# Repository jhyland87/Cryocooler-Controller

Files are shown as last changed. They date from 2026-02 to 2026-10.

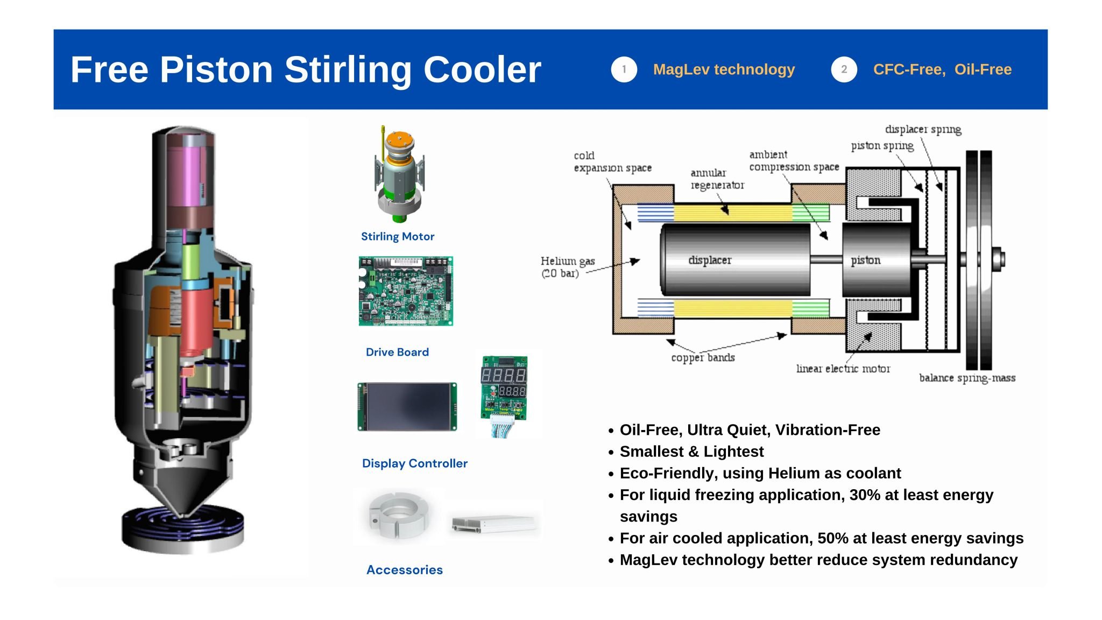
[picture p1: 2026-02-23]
resources/images/RS100-2-2048x1152.jpg

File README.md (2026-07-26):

# ESP32-S3 Cryocooler Controller

Firmware for an ESP32-S3 DevKit that automates the cooldown sequence of a cryogenic cooler. The controller manages a compressor-driven cold stage through ten operational states — from a cold start at room temperature (~295 K) down to an operating setpoint of 78 K, with a graceful shutdown sequence — while enforcing thermal safety limits, detecting back-EMF current spikes, streaming live telemetry via Protobuf over WebSocket, and serving a real-time Preact dashboard over WiFi.

---

## Hardware

| Component | Part | Interface | Address / Pin | Purpose |
|---|---|---|---|---|
| Microcontroller | ESP32-S3 DevKitC-1-N32R16V | — | — | Host MCU (32 MB flash, 16 MB PSRAM) |
| Cold-stage sensor | ADS122C04 + PT1000 RTD | I2C | 0x45 | Cold-stage temperature (4-wire, ratiometric) |
| Waveform generator | AD9833 DDS | SPI | CS: GPIO 7 | 60 Hz sine wave for compressor |
| DAC | AD5693R 16-bit | I2C | 0x4E | Amplifier power control |
| Power monitor | INA237 | I2C | auto | Bus voltage + current |
| IMU | LSM6DSOX 6-DOF | I2C | 0x6A | Vibration / overstroke detection |
| Fan / pump controller | EMC2303 three-channel PWM | I2C | 0x2F | Cooling fan (ch 0) + pump (ch 1) |
| Current sensor | ACS37800 | I2C | auto | Amplifier AC current monitoring |
| Compressor relay | SparkFun Qwiic Single Relay | I2C | 0x19 | Compressor on/off |
| Amplifier relay | SparkFun Qwiic Single Relay | I2C | 0x18 | Amplifier on/off |
| Coolant flow sensor | Alphacool ES (Hall-effect) | GPIO 10 | — | Coolant flow pulses |
| Coolant temperature | NTC thermistor | ADC GPIO 2 | — | Coolant temp via voltage divider |
| Status LED | WS2812 RGB | GPIO 38 | — | Fault / Ready indication |

**I2C bus:** SDA → GPIO 8, SCL → GPIO 9.

**SPI bus** (AD9833 only): CLK → GPIO 42, MISO → GPIO 41, MOSI → GPIO 40.

**Fan fault alert:** EMC2303 ALERT# → GPIO 14 (active-low, external pull-up).

---

## Architecture

All subsystem modules follow a standardised lifecycle pattern built on a CRTP base class (`ModuleBase<T>`) with compile-time interface enforcement. Modules are registered in declarative arrays and initialised/serviced via generic helpers — adding a new module is a one-liner. See [`docs/modules.md`](docs/modules.md) for the full module authoring guide.

```mermaid
flowchart TD
    subgraph Persistent ["Persistent Modules (init once at startup)"]
        HW[hardware<br/>Shared I2C + SPI buses]
        IMU[imu<br/>LSM6DSOX accelerometer]
        CMD[commands<br/>Serial console]
        DASH[dashboard<br/>WiFi + Preact SPA + WebSocket]
        TEL[telemetry<br/>Protobuf frame builder]
        SYS[sysinfo<br/>INA237 power monitor]
        OTA[ota<br/>HTTP firmware updates]
    end

    subgraph Control ["Control Modules (re-init on every Initialize state)"]
        COOL[cooling<br/>EMC2303 fan + pump<br/>software LUT]
        CH[cold_head<br/>ADS122C04 PT1000 RTD]
        AMP[amplifier<br/>AD9833 + AD5693R DAC + ACS37800]
        COMP[compressor<br/>Qwiic relay]
        IND[indicator<br/>WS2812 RGB LED]
    end

    subgraph FSM ["Core Logic"]
        SM[state_machine<br/>Pure FSM — no hardware calls]
    end

    CH  -->|tempC, coolingRate, stalled| SM
    AMP -->|rmsV, overstroke| SM
    IMU -->|overstroke| SM
    SYS -->|sysVoltage| SM

    SM -->|dacTarget| AMP
    SM -->|compressorRelay, amplifierRelay| COMP
    SM -->|faultIndMode, readyIndMode| IND
    SM -->|Output| TEL

    TEL --> DASH
    TEL --> CMD

    classDef persistent fill:#dbeafe,stroke:#3b82f6,color:#1e3a5f
    classDef control    fill:#dcfce7,stroke:#16a34a,color:#14532d
    classDef fsm        fill:#fef3c7,stroke:#d97706,color:#78350f

    class HW,IMU,CMD,DASH,TEL,SYS,OTA persistent
    class COOL,CH,AMP,COMP,IND control
    class SM fsm

    style Persistent fill:#eff6ff,stroke:#93c5fd
    style Control    fill:#f0fdf4,stroke:#86efac
    style FSM        fill:#fffbeb,stroke:#fcd34d
```

---

## Module Reference

### hardware

Initialises the shared I2C bus (`Wire.begin(SDA, SCL)`) and SPI bus (`SPI.begin(...)`) once at startup. All other modules access buses via `hardware::i2c()` and `hardware::spi()` rather than the global singletons. Provides `recoverI2c()` to reset the I2C bus to a clean idle state after a failed transaction, and an error monitor (`reportI2cError()` / `serviceI2c()`) that triggers automatic bus recovery when error counts exceed a threshold.

---

### state_machine

The core of the controller. Ingests sensor readings every tick and outputs a complete set of actuator targets. Contains no hardware calls — pure logic, fully unit-testable on the host PC.

**States:**

| # | Name | Description | FAULT LED | READY LED | DAC |
|---|---|---|---|---|-----|
| -1 | Off | System powered down | Off | Off | 0 |
| 0 | Initialize | Power-up self-check | Solid Amber | Solid Amber | 0 |
| 1 | Idle | Warm standby | Solid Red | Off | 0 |
| 2 | CoarseCooldown | Cooling above 85 K | Flash Fast Red | Off | proportional to temp |
| 3 | FineCooldown | Cooling below 85 K | Flash Fast Red | Flash Slow Green | proportional to temp |
| 4 | Overshoot | Below setpoint, settling | Flash Fast Red | Flash Fast Green | 0 |
| 5 | Settle | In setpoint band; Normal relay | Flash Fast Red | Flash Fast Green | 0 |
| 6 | Baseline | Collecting pre-run baseline (5 min) | Off | Solid Green | 0 |
| 7 | Operating | Normal cryogenic operation | Off | Solid Green | 0 |
| 8 | Shutdown | Graceful shutdown; DAC ramps down | Off | Off | ramps → 0 |
| 9 | Delay | Timed hold; resumes at configured next state | Solid Amber | Solid Amber | 0 |
| 127 | Fault | Terminal fault state | Flash Fast Red | Off | 0 |

**Key configuration** (all in `config.h`):

| Constant | Default | Description |
|---|---|---|
| `SETPOINT_C` | -195.15 °C (78 K) | Target cold-stage temperature |
| `COARSE_FINE_THRESHOLD_C` | -188.15 °C (85 K) | Coarse/Fine transition boundary |
| `SETPOINT_TOLERANCE_C` | 3.0 °C | Band around setpoint for settle/overshoot logic |
| `SETTLE_DURATION_MS` | 60 000 ms | Time stable before advancing to Baseline |
| `BASELINE_DURATION_MS` | 300 000 ms | Baseline collection window |
| `SHUTDOWN_DURATION_MS` | 5 000 ms | Graceful shutdown ramp duration |
| `STALL_DETECT_WINDOW_MS` | 600 000 ms | Stall detection observation window |
| `STALL_MIN_DROP_C` | 2.0 °C | Minimum temp drop required in the window |
| `BACKOFF_MAX_COUNT` | 10 | Max overstroke events before TooManyBackoffs fault |

---

### cold_head

Reads the PT1000 RTD via the ADS122C04 24-bit ADC over I2C (address 0x45). The ADC is configured for 4-wire ratiometric measurement with 250 µA IDAC excitation and a 3854 Ω external reference resistor. Raw ADC counts are converted to resistance, then to temperature via the Callendar-Van Dusen equation (above 0 °C) and AN709 polynomial (below 0 °C).

Uses a non-blocking two-phase state machine: start single-shot conversion → poll DRDY → read 24-bit result. Maintains a ring buffer of `TEMP_HISTORY_SIZE` timestamped samples for cooling-rate calculation (°C/min), stall detection, and cooldown progress (0–100 %).

| Function | Returns |
|---|---|
| `getLastTempK()` | Cold-stage temperature in Kelvin |
| `getLastTempC()` | Cold-stage temperature in Celsius |
| `getCoolingRateCPerMin()` | °C/min, positive = cooling |
| `isStalled()` | True if stall threshold exceeded |

---

### amplifier

Drives the AD9833 DDS (60 Hz sine wave), AD5693R 16-bit DAC (compressor power), and ACS37800 current sensor. Provides two ramp modes:

- `rampToVoltage(target)` — smooth ramp at ±`DAC_MAX_STEP_PER_INTERVAL` per tick
- `rampTowardShutdown(target)` — fast ramp at ±`DAC_SHUTDOWN_STEP_PER_INTERVAL` per tick

**Overstroke (back-EMF) detection:** A slow-tracking EMA forms the baseline. A reading exceeding `baseline + OVERSTROKE_CURRENT_THRESHOLD_A` fires `hasOverstroke()`, subject to `OVERSTROKE_DEBOUNCE_MS`. The EMA is primed for `OVERSTROKE_PRIME_READINGS` ticks on startup.

---

### imu

Drives the LSM6DSOX 6-DOF IMU over I2C (accelerometer only). On `init()` the accelerometer is configured and a one-time blocking calibration collects samples to compute per-axis offsets (gravity is removed from the Z offset).

Each `service()` call applies calibration offsets, runs a first-order low-pass filter, and computes roll/pitch from filtered acceleration. Motion / overstroke is flagged when acceleration magnitude deviates from 9.81 m/s² by more than `ACCEL_THRESHOLD_MPS2`; it clears after `MOTION_TIMEOUT_MS` of stillness.

A periodic FFT (`calculateFrequency()`) detects the compressor vibration frequency in the 45–75 Hz band using 256 samples at 400 Hz, with Hann windowing and quadratic peak interpolation.

| Function | Returns |
|---|---|
| `isInitialized()` | True if sensor was found and configured |
| `hasOverstroke()` | True while motion/overstroke is active |
| `getRoll()` / `getPitch()` | Orientation angles in degrees |
| `getAccelMag()` | Calibrated acceleration magnitude (m/s²) |
| `getFrequencyHz()` | Detected compressor frequency (Hz), or NAN |
| `getTemperature()` | IMU die temperature (°C) |

---

### sysinfo

Reads bus voltage and current via the INA237 power monitor over I2C. Applies EMA smoothing and exposes `getVoltage()`.

---

### cooling

Controls the cooling fan and pump via a single EMC2303 three-channel PWM controller over I2C (address 0x2F). Uses a custom `EMC230x` Arduino library (in `lib/EMC230x/`).

**Software LUT:** Replaces the previous EMC2101 hardware LUT. Each channel has an independently-configured temperature-to-duty lookup table with hysteresis, evaluated once per second from coolant temperature. Entries are sorted ascending by temperature; the evaluator only writes to the chip when the active row changes.

**Deferred init:** The EMC2303 is powered from a 3.3 V regulator derived from the 12 V rail. If 12 V is absent at boot, `init()` fails gracefully and `service()` retries once per second until the chip appears, then promotes itself to `MODULE_INIT_SUCCESS`.

**Fault detection:** The EMC2303's open-drain ALERT# pin (GPIO 14, external pull-up) is sampled every service tick. When asserted (LOW), all four status registers (fan, stall, spin-up, drive-fail) are read and decoded. Faults are exposed via `hasFanFault()` / `getFanFaultDurationMs()` and included in the telemetry frame.

**I2C bus recovery:** When the EMC2303 loses power mid-operation, it can hold the I2C SDA line low and block all other sensors on the shared bus. The service function calls `hardware::recoverI2c()` immediately on detecting an I2C failure to free the bus for other devices.

**Pump normalisation:** User-facing pump speeds are 0–100 % normalised, mapped to 0–`COOLING_PUMP_MAX_DUTY_PCT` (raw 0–255) at the hardware boundary. The pump stalls above ~16 % effective duty (~4400 RPM).

**Tracking monitors:** Score-based monitors for fan duty, coolant temperature, and flow rate detect sustained deviations from expected values.

| Function | Returns |
|---|---|
| `getCoolantTemperature()` | Coolant temperature in °C |
| `getCoolantFlowRate()` | Coolant flow rate in L/min |
| `getFanSpeed()` | Fan duty (0–255) |
| `getFanRPM()` | Fan tachometer RPM |
| `getPumpSpeed()` | Pump speed (normalised 0–100 %) |
| `getPumpRPM()` | Pump tachometer RPM |
| `hasFanFault()` | True while ALERT# is asserted |
| `getFanFaultDurationMs()` | Duration of current fault episode |

---

### compressor

Manages the compressor relay (SparkFun Qwiic Single Relay at 0x19) with timed-run support. `compressor start <duration>` energises the relay for a specified duration (e.g. `1h30m`, `45s`), clamped to `COMPRESSOR_MAX_RUN_MS`. Can be disabled at compile time with `ENABLE_COMPRESSOR false`.

---

### indicator

Drives the on-board WS2812 RGB LED (GPIO 38) according to the state machine's requested `Mode`. All flash timing is non-blocking — `update(nowMs)` is called every loop iteration.

| Mode | Colour | Rate |
|---|---|---|
| `SolidRed` | Red | — |
| `SolidGreen` | Green | — |
| `SolidAmber` | Amber | — |
| `FlashFastRed` | Red | 2 Hz |
| `FlashSlowGreen` | Green | 1 Hz |
| `FlashFastGreen` | Green | 2 Hz |

---

### dashboard

Connects to WiFi and serves a Preact single-page application with real-time telemetry:

- **HTTP** (port 80): serves the embedded SPA (`index.html`, `app.js`, `style.css`) and a JSON telemetry endpoint at `GET /api/telemetry`
- **WebSocket** (port 8080): streams Protobuf-encoded telemetry frames at 1 Hz
- **mDNS**: `cryocooler.local`

The dashboard frontend uses Preact + MUI + Vite and is bundled into firmware flash at build time via `scripts/embed_web.py`. WiFi credentials live in `include/arduino_secrets.h`.

---

### ota

HTTP OTA firmware update endpoint. `GET /ota` serves an upload form; `POST /ota` flashes new firmware. Enabled with `ENABLE_OTA true` in `config.h`.

---

### commands

Non-blocking USB serial command handler. `service()` accumulates characters and dispatches completed lines. The same `processLine()` function is used by the TCP server and by unit tests with a stub `Print`.

| Command | Action |
|---|---|
| `start` | Begin cooldown (from Off or Idle) |
| `stop` | Abort and return to Idle |
| `off` | Power off the system entirely |
| `reboot` | Reboot the MCU |
| `status` | Print current state and running flag |
| `summary` | Full snapshot of all sensor and actuator values |
| `fsm state` | Print current FSM state with time-in-state |
| `fsm history` | Print recent FSM state transitions |
| `fault clear` | Clear an active fault and return to Idle |
| `fault history` | Print fault log with reason and clear method |
| `board` | Print compile-time board/platform info |
| `i2c scan` | Scan I2C bus and print responding addresses |
| `reinit` | Re-initialise all or named modules |
| `cooling on/off` | Enable / disable cooling system |
| `cooling fan <N>` | Set fan: raw duty (0–255) or percent (0–100%) |
| `cooling pump <N>` | Set pump: raw duty (0–255) or percent (0–100%) |
| `set vout <V>` | Set DAC output voltage (0–120 V, 0–100 %, or `auto`) |
| `get vout` | Get current DAC output voltage |
| `relay` | Show current state of both relays |
| `relay amplifier on/off` | Control amplifier relay |
| `relay compressor on/off` | Control compressor relay |
| `compressor start <dur>` | Start timed compressor run (e.g. `1h30m`) |
| `compressor status` | Show compressor state and remaining time |
| `compressor stop` | Stop the compressor immediately |
| `telemetry on/off` | Enable / disable telemetry output |
| `telemetry delta on/off` | Delta-only or full frames |
| `dashboard on/off` | Enable / disable dashboard TCP broadcasts |
| `mock ...` | Sensor mock: `enable`, `disable`, `status`, `temp`, etc. |
| `ota status` | Print OTA partition and firmware version info |
| `update image` | Flash new firmware via HTTP upload |
| `help` | List all commands |

---

### telemetry

Snapshots all module values each tick into a `FrameBuilder`. The WebSocket path encodes frames as Protobuf binary via Nanopb; the HTTP `/api/telemetry` endpoint returns JSON. The schema source of truth is `proto/telemetry.proto`.

---

### frame_builder

Format-agnostic telemetry frame with a fluent field API. Renders to Serial Studio wire format or `JsonDocument` from the same snapshot.

---

### conversions

Header-only pure-math utilities with no hardware dependencies — safe for native unit tests.

| Function | Description |
|---|---|
| `resistanceToTemperaturePT1000(R)` | PT1000 Ω → °C (Callendar-Van Dusen / AN709) |
| `tempCToDacValue(...)` | Temperature → 12-bit DAC mapping |
| `tempCToFraction(...)` | Temperature → cooldown fraction [0.0, 1.0] |
| `msToHHMMSS(ms, buf)` | ms → `HH:MM:SS` string |
| `parseDurationMs(str, ...)` | Human duration string → ms (e.g. `1h30m`) |
| `formatDurationMs(ms, buf, len)` | ms → compact human string (e.g. `1h 30m 00s`) |

---

### sensor_mock

Injects synthetic sensor values into all modules for hardware-free FSM testing. When `sensor_mock::isActive()`, `read()`/`service()` in each module pull from `sensor_mock::get()` instead of hardware. Activated via the `mock` serial command.

---

## Transition Triggers

### Normal Operation Flow

`start()` selects the resume state from `tempK` and is valid from both **Off** and **Idle**. `Delay` is reachable from any non-Fault state via `startDelay()` — see [Global Transitions](#global-transitions).

```mermaid
stateDiagram-v2
    direction TB

    [*] --> Off
    Off  --> Initialize : reinit
    Idle --> Initialize : reinit
    Initialize --> Idle : init timer

    state "Cooldown Phase" as COOLDOWN {
        CoarseCooldown --> FineCooldown : temp < 85 K
        FineCooldown --> CoarseCooldown : temp > 85 K
    }

    state "Approaching Setpoint" as SETTLING {
        Overshoot --> Settle : in band
    }

    state "Stable Operation" as STABLE {
        Baseline --> Operating : baseline timer
    }

    Idle --> CoarseCooldown : start, temp <br/>≥ 85 K
    Idle --> FineCooldown   : start, below <br/>85 K
    Idle --> Overshoot      : start, below<br/> setpoint
    Idle --> Settle         : start, in band

    FineCooldown --> Overshoot : below setpoint
    FineCooldown --> Settle    : in band

    Settle --> Baseline : settle timer

    COOLDOWN --> Shutdown : stop
    SETTLING --> Shutdown : stop
    STABLE   --> Shutdown : stop
    Delay    --> Shutdown : stop
    Shutdown --> Idle     : shutdown<br/>timer

    Delay --> Idle           : timer → Idle
    Delay --> CoarseCooldown : timer → Coarse

    classDef startup  fill:#dbeafe,color:#1e3a5f
    classDef cooldown fill:#ccfbf1,color:#134e4a
    classDef settling fill:#fef3c7,color:#78350f
    classDef stable   fill:#dcfce7,color:#14532d
    classDef shutdown fill:#f1f5f9,color:#334155
    classDef delay    fill:#ede9fe,color:#3b0764

    class Off,Initialize,Idle startup
    class CoarseCooldown,FineCooldown cooldown
    class Overshoot,Settle settling
    class Baseline,Operating stable
    class Shutdown shutdown
    class Delay delay
```

### Fault Conditions

```mermaid
stateDiagram-v2
    direction LR

    state "Cooldown Phase" as COOLDOWN {
        CoarseCooldown
        FineCooldown
    }

    state "Approaching Setpoint" as SETTLING {
        Overshoot
        Settle
    }

    state "Stable Operation" as STABLE {
        Baseline
        Operating
    }

    COOLDOWN --> Fault : temp stall
    COOLDOWN --> Fault : too many backoffs
    SETTLING --> Fault : too many backoffs
    STABLE   --> Fault : too many backoffs
    Delay    --> Fault : too many backoffs

    Fault --> Idle       : clearFault()
    Fault --> Initialize : reinit()

    classDef cooldown fill:#ccfbf1,color:#134e4a
    classDef settling fill:#fef3c7,color:#78350f
    classDef stable   fill:#dcfce7,color:#14532d
    classDef delay    fill:#ede9fe,color:#3b0764
    classDef fault    fill:#fee2e2,stroke:#ef4444,color:#7f1d1d
    classDef startup  fill:#dbeafe,color:#1e3a5f

    class CoarseCooldown,FineCooldown cooldown
    class Overshoot,Settle settling
    class Baseline,Operating stable
    class Delay delay
    class Fault fault
    class Idle,Initialize startup
```

### Global Transitions

These originate from all non-Fault states and are omitted from the diagrams above.

| Trigger | Condition | To |
|---|---|-----|
| `off()` | — | Off |
| RMS overvoltage | `amplifier RMS V > AMPLIFIER_MAX_VOLTAGE_VAC` | Fault |
| Low system voltage | `systemVoltage > 0` and `< MIN_SYSTEM_VOLTAGE_VDC` | Fault |
| State oscillation | Same two states alternate ≥ `FSM_OSCILLATION_MIN_CYCLES` times in window | Fault |
| `startDelay()` | — | Delay |

---

## Build Pipeline

The firmware build runs three pre-build scripts in order before PlatformIO compiles:

### 1. Protobuf compilation (scripts/compile_proto.py)

Compiles `proto/telemetry.proto` into Nanopb C stubs (`src/generated/telemetry.pb.c`, `include/generated/telemetry.pb.h`). Auto-installs the `google.protobuf` Python package if missing.

Skip with `SKIP_PROTO_BUILD=1 pio run`.

### 2. Dashboard build (scripts/build_dashboard.py)

Runs `npm ci` in `dashboard/`, generates protobufjs stubs (`npm run proto:build`), then builds the Vite SPA (`npm run build`) into `data/`.

Skip with `SKIP_DASHBOARD_BUILD=1 pio run`.

### 3. Web embedding (scripts/embed_web.py)

Embeds `data/*.html/css/js` as `PROGMEM const char[]` arrays in `include/web_content.h`. The SPA is served directly from flash — no filesystem needed.

### Quick firmware iteration

```bash
SKIP_DASHBOARD_BUILD=1 pio run          # firmware only, skip npm/vite
SKIP_DASHBOARD_BUILD=1 pio run -t upload  # build + flash
```

---

## Dependencies

### PlatformIO libraries (platformio.ini)

| Library | Purpose |
|---|---|
| `majicdesigns/MD_AD9833` | DDS waveform generator |
| `bblanchon/ArduinoJson` | JSON serialisation |
| `mathieucarbou/ESPAsyncWebServer` | Async HTTP + WebSocket server |
| `robtillaart/RunningAverage` | Running average utility |
| `jonblack/arduino-fsm` | Finite state machine |
| `adafruit/Adafruit INA237 and INA238 Library` | I2C power monitor |
| `pololu/ACS37800` | AC current sensor |
| `kosme/arduinoFFT` | FFT for vibration frequency detection |
| `adafruit/Adafruit LSM6DS` | 6-DOF IMU driver |
| `adafruit/Adafruit AD569x Library` | AD5693R DAC |
| `sparkfun/SparkFun Qwiic Relay Arduino Library` | Relay control |
| `nanopb/Nanopb` | Protobuf C encoder/decoder |
| `sparkfun/SparkFun ADS122C04 ADC Arduino Library` | 24-bit ADC for PT1000 RTD |

### Local libraries (lib/)

| Library | Purpose |
|---|---|
| `EMC230x` | EMC2301/02/03/05 dual PWM fan/pump controller |
| `ContinuousZMCT103C` | Non-blocking AC current RMS sampling |
| `Device-Defined-Dashboard` | Serial Studio dashboard JSON generator |

### Dashboard (dashboard/package.json)

| Package | Purpose |
|---|---|
| Preact | Lightweight UI framework |
| MUI (Material UI) | Component library |
| MUI X-Charts | Telemetry chart components |
| Vite | Build tooling |
| protobufjs | WebSocket telemetry decoding |

### Platform

```ini
platform = espressif32@5.3.0   ; Arduino Core 2.0.6 + IDF 4.4.x
board    = esp32-s3-devkitc-1-n32r16v
```

---

## Setup

### WiFi credentials

Create `include/arduino_secrets.h` (excluded from version control):

```cpp
#define WIFI_SSID "your-network-name"
#define WIFI_PASS "your-password"
```

### Key tuning parameters

All application-level constants live in `config.h`. Hardware pin assignments live in `pin_config.h`. Internal algorithm parameters live in `config_advanced.h`. None have hardware includes, so all are safe to include in native unit tests.

---

## Testing

Unit tests run on the host PC via PlatformIO's native environment:

```bash
pio test -e native
```

Tests use a minimal Arduino stub (`test/test_native/stubs/`) that provides `millis()`, a `Print` class, and other shims. The state machine, serial command handler, and telemetry modules are compiled and exercised without hardware.

Embedded integration tests (requiring hardware) live in `test/test_embedded/` and run via:

```bash
pio test -e esp32s3
```

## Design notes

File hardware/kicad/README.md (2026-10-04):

# Cryocooler controller — KiCad schematic

KiCad 10 hierarchical schematic for the ESP32-S3 cryocooler controller. Open
`cryocooler.kicad_pro`. A PDF export is in `cryocooler-schematic.pdf`. No PCB layout yet.

GPIO assignments follow [`include/config/pin_config.h`](../../include/config/pin_config.h).
The hardware table in the top-level README is stale (wrong buses/pins for the IMU, DAC,
ACS37800 and EMC2303), so use this file instead.

## Sheets

| Sheet | Contents |
|---|---|
| `cryocooler.kicad_sch` (root) | ESP32-S3-WROOM-2-N32R16V, EN/BOOT, USB-C + ESD, I2C pull-ups |
| `power_input` | 12 V screw terminal, 5 A fuse, SMBJ16A TVS, bulk caps |
| `power_button` | LTC2954CTS8-2, IRF4905S high-side P-FET, KILL# bias, CL25N8-G (SOT-89) + red/green LED |
| `rails_logic` | AP63205 buck (12→5 V) → LD1117S33 (5→3.3 V) |
| `rails_15v` | ADP5071AREZ ±16.4 V (datasheet Fig. 47 values) → ADP7142 (+15 V), ADP7182 (−15 V) |
| `signal_gen` | 25 MHz osc, AD9833, OPA1656, MCP4921 + LM4040-2.5 + OPA188, AD633 |
| `amp_control` | GPIO6 → BSS138 → BSS84 high-side 12 V to amplifier REM, red/green LED |
| `amp_current` | ACS37800 (SPI) + ISO7741 + MIE1W0505 (VSEL→GND2 = 3.3 V output), 4×1 MΩ + 4.02 kΩ divider |
| `system_current` | INA237 (I2C 0x40) + 15 mΩ shunt in the switched 12 V rail |
| `cooling` | EMC2303 (0x4D via 33 kΩ ADDR_SEL pull-up; fan + pump), Alphacool ES flow tach and NTC |
| `cold_head` | ADS122C04 (I2C 0x45), 4-wire PT1000, 3.9 kΩ Rref |
| `imu` | LSM6DSOX in SPI mode with INT1/INT2 |
| `indicators` | READY / FAULT LEDs, WS2812B status LED behind a 74AHCT1G125 level shifter |

## GPIO map (ESP32-S3-WROOM-2)

| Signal | GPIO | Signal | GPIO |
|---|---|---|---|
| I2C SDA / SCL | 8 / 9 | AD9833 FSYNC | 7 |
| SPI SCK / MOSI / MISO | 42 / 41 / 40 | MCP4921 CS | 5 |
| LSM6DSOX CS / INT1 / INT2 | 1 / 2 / 39 | ACS37800 SCK / MOSI / MISO / CS | 11 / 12 / 13 / 17 |
| Amp REM enable | 6 | PWR_KILL (LTC2954 KILL#) | 10 |
| FAULT / READY LED | 14 / 15 | Flow tach | 18 |
| EMC2303 ALERT# | 21 | NTC ADC | 4 |
| Status RGB (WS2812B) | 38 | LTC2954 INT# (optional, unused by firmware) | 16 |

GPIO43 (TXD0) is left unconnected because it toggles with ROM boot messages; ACS37800 chip-select is on GPIO17. GPIO26–37 are reserved
by the octal flash/PSRAM and are left unconnected.

## Drawing conventions

Power symbols are always upright (supplies point up, grounds hang down) and resistors use the US zig-zag symbol
(`Device:R_US`). Every sheet is hand-laid in the same style: signal flow runs left to right, supplies are drawn as
shared rails with decoupling caps hanging off them, switching loops are kept compact, and nets are wired with
lines rather than net labels (labels are used only for global signals such as the GPIO nets, and for a few
local nets that would otherwise need long detours, for example the ISO7741 isolated-side SPI lines).

Bypass/decoupling capacitors for each IC are drawn together in a labelled block at the side of the sheet (supply rail, caps, ground bus) and connect to the IC through the shared power nets; regulator input/output and compensation capacitors stay in the circuit.

**No-overlap text rule.** Reference, value, net-label and note text may not overlap other text or a symbol body
(plus 1 mm for pin numbers). `tools/textlayout.py` places each field in the first free spot, hides a field only
if none exists, and `gen_schematic.py` exits non-zero if `text overlap check` reports any overlap. Pin names and
numbers drawn inside a library symbol, and labels that sit on their own wire, are outside the rule.

## Regenerating

The schematic files are generated; edit the Python and re-run, don't hand-edit the `.kicad_sch` files.
Each `build_*` function in `tools/gen_schematic.py` sets `sh.handwired = True` and draws its sheet in grid cells
(1 cell = 1.27 mm) with `place_ic`, `pose=at(column, row, rot)`, `wire`, `rail_symbol`, `rail_flag`, `spur` and
`net_label`; `tools/layout.py` (the auto-router) is still there for sheets that leave `handwired` off.
Wires are split at pins automatically, so a pin in the middle of a wire is connected.

```bash
python3 hardware/kicad/tools/make_lib.py        # lib/cryocooler.kicad_sym
python3 hardware/kicad/tools/gen_schematic.py   # root + sheets/
```

`tools/verify_netlist.py` checks the GPIO map against `pin_config.h`, missing footprints and
single-pin nets on a `kicad-cli sch export netlist` output; `tools/compare_netlists.py` compares the
connectivity of two netlists (useful after changing layout, which must not change connections; two-pin
passives may be flipped), and `tools/datasheet_rules.py` checks datasheet-critical connections.

## Review status

Every IC was audited against its datasheet; see [`DESIGN_REVIEW.md`](DESIGN_REVIEW.md) for the
errors found and fixed, what was verified, and the open issues that need a decision (notably:
the 12 V → 5 V stage is now an AP63205 buck instead of the over-limit LD1117S50).
`tools/datasheet_rules.py` re-checks 117 datasheet-derived connections on every change.

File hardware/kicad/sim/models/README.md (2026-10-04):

# Simulation models

- `ad633_behavioral.lib` - hand-written AD633 stand-in (W = X*Y/10, rail-limited). Not an Analog Devices model.
- `ti_original/OPA1656.LIB`, `ti_original/OPAx188.LIB` - Texas Instruments SPICE models. Not committed:
  download them from the OPA1656 and OPA188 product pages on ti.com (Design tools & simulation,
  SPICE model) and put the `.LIB` files in `ti_original/`. `cryocooler_sim.kicad_sch` references them
  through its Sim.Library fields.
- `opa1656.lib`, `opax188.lib` - ngspice-converted copies made by `../prep_models.py`. They did not converge
  in the headless runner; KiCad's own simulator runs the originals.

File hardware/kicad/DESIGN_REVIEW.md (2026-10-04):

# Design review: datasheet audit

Every IC and active discrete in the schematic was checked against its manufacturer datasheet
(pinout, supply range, required external parts, unused-pin rules, absolute maximums). The
connection-level findings are encoded as regression tests in
[`tools/datasheet_rules.py`](tools/datasheet_rules.py) (117 rules, run against the exported
netlist). ERC alone cannot catch a wrong circuit, so run both after any change:

```bash
kicad-cli sch export netlist --format kicadsexpr -o /tmp/cryo.net hardware/kicad/cryocooler.kicad_sch
python3 hardware/kicad/tools/datasheet_rules.py /tmp/cryo.net
python3 hardware/kicad/tools/verify_netlist.py /tmp/cryo.net      # GPIO map vs pin_config.h
```

## Errors found and fixed

These were wrong in my first version (several were also wrong in the original draft):

| Part | Problem | Datasheet fact | Fix |
|---|---|---|---|
| EMC2303 | ADDR_SEL tied to GND | ADDR_SEL decodes a **pull-up resistor** (Table 5-1): 33 kΩ → 0x4D | 33 kΩ to 3V3 |
| EMC2303 | PWM outputs unpulled | PWM outputs are open-drain by default and need a pull-up | 10 kΩ to 3V3 on PWM1/PWM2 |
| MIE1W0505 | VSEL tied to GND2 but a 5 V rail assumed | VSEL → GND2 gives **3.3 V**; 5 V needs VSEL to VOUT/float | Kept VSEL → GND2; the module now makes ISO_3V3 directly, so the LD1117 and ISO_5V on that side were removed |
| MIE1W0505 | Wrong output cap | 22 µF + 0.1 µF out, 10 µF + 0.1 µF in | Corrected. (It is an MPS part, not Murata.) |
| CL25 | Pin 2/3 swapped (VB was on NC) | VA = 1, VB = 2 (centre lead + tab), NC = 3 in both packages; N3 is TO-92, **N8 is SOT-89** | Fixed pinout; now **CL25N8-G (SOT-89)** as requested |
| Power LED | 120 Ω legs diverted the 25 mA away from the LED | CL25 is a 25 mA source shared by both legs | 330 Ω (about 9 mA reaches the LED) |
| ADP7182 | EN tied to GND | EN is dual-polarity (\|VEN\| ≥ 2 V); **EN = 0 V is off** | EN tied to VIN (−16.5 V) |
| ADP7182 | No stability cap | 100 pF across RFB1 recommended | Added |
| ADP5071 | Draft values (L1 10 µH, RC1 100 k, CC1 10 nF, …) | Tested values in Fig. 47 / Tables 9-11 | L1 3.3 µH, L2 6.8 µH, RC1 5.6 k / CC1 47 nF, RC2 12 k / CC2 68 nF, DFLS240 diodes, 10 µF/50 V outputs |
| ADP5071 | Rails only about ±15 V (no LDO headroom) | VPOS = 0.8 V (1 + RFT1/RFB1); VNEG = 0.8 V − 0.8 V·RFT2/RFB2 | RFT1 2.67 M / RFB1 137 k → +16.39 V; RFT2 2.55 M / RFB2 118 k → −16.49 V |
| ADP7142 / ADP7182 | 2.2 µF caps lose capacitance at 15 V DC bias | ≥ 1.5 µF effective required | 4.7 µF / 25 V |
| LSM6DSOX | SDx (pin 2) and SCx (pin 3) left floating | Must be tied to **VDDIO or GND** in I²C/SPI mode | Tied to GND |
| MCP4921 | Only 100 nF on VDD; Vref bias marginal | 0.1 µF + 10 µF on VDD; LM4040 needs ≥ 60-65 µA | + 10 µF; 8.2 k → 6.8 k |
| WS2812B | 3.3 V data into a 5 V part | VIH = 0.7 × VDD = 3.5 V | 74AHCT1G125 level shifter |
| AD633 | Output offset up to ±50 mV reached the amplifier | AD633 spec: output offset ±5 to ±50 mV | 10 µF DC-blocking cap + 100 kΩ |
| OPA1656 (sine gain stage) | R8 33 k gave 3.3 V pk (6.6 Vpp) full scale, under-using the amplifier's input range | ZE500.1 RCA input 0.2-6 V (unverified, from retailer listings); user wants Vctl 10 V = 10 Vpp (5 V pk, 3.5 Vrms) | R8 33 k → 51 k (gain 16.45, ~4.9 V pk with the AD9833's assumed 0.3 V pk; calibrate in firmware) |

## Verified as correct (no change needed)

| Part | Checked against | Result |
|---|---|---|
| LTC2954-2 (TSOT-23-8) | LTC2954 datasheet 2954fb | Pinout; no internal KILL pull-up (so the 5 V bias is required); KILL abs max 7 V; ONT floating = 32 ms; 100 nF PDT ≈ 0.7 s hold-off; EN#/INT# ratings |
| ESP32-S3-WROOM-2 | Datasheet v1.7 | Pins 28-30 are NC; IO47/48 are 1.8 V on R16V parts; strapping pins; EN needs a defined level |
| AD633JR (SOIC) | AD633 Rev A (pin drawing) | 1 Y1, 2 Y2, 3 −VS, 4 Z, 5 W, 6 +VS, 7 X1, 8 X2; ±15 V; RL ≥ 2 kΩ |
| AD9833 | AD9833 Rev E | COMP 10 nF → VDD, CAP/2.5V 100 nF, 0.1 + 10 µF on VDD, VINH 2.8 V at 5 V VDD |
| OPA1656 / OPA188 | TI datasheets | Pinouts, supply (VS ≤ 40 V), NC pins may float |
| INA237 | TI datasheet | Pinout, 0x40 with A0 = A1 = GND, IN+/IN− polarity, ±163.84 mV range |
| ADS122C04 | TI SBAS751B | Pinout, 0x45 (A0 = A1 = DVDD), ratiometric 4-wire RTD circuit, VREF ≥ 0.75 V (0.975 V), AIN2 may float |
| ISO7741 | TI SLLSEP4K | Pinout and channel directions, 0.1 µF decoupling, default output high |
| ACS37800 | Allegro datasheet | Pinout, 3.3 V variant, 0.1 µF, 4 × 1 MΩ + RSENSE divider (Fig. 1), SPI VIH 2.8 V |
| LD1117S33 | ST Rev 26 | Pinout (tab = VOUT), ≥ 10 µF output cap, 5 V input within the 15 V limit |
| AP63205 | Diodes DS41326 Rev 3-2 | Pinout 1 FB, 2 EN, 3 VIN, 4 GND, 5 SW, 6 BST; component values from Fig. 1 / Table 3; VIN ≤ 32 V |
| IRF4905S, BSS84, BSS138 | Infineon / Diodes / onsemi | Ratings and VGS(th); ±20 V gate limit not exceeded |
| USBLC6-2SC6 | ST Rev 7 | Pinout; drawn as a pass-through (ESP32 side on pins 4/6, connector side on 3/1) so each data line crosses the protection device instead of being tied across it |
| LM4040 | TI LM4040-N | SOT-23 pinout (pin 3 may float) |
| SG-8002CA | Epson datasheet (supplied) | Pin map 1 OE/ST, 2 GND, 3 OUT, 4 VCC; **PH = 5 V CMOS** with OE (high or open = enabled); 0.01-0.1 µF bypass; no filter in the supply line; 7.0×5.0 mm, 5.08 mm pitch footprint. Order the PH variant, e.g. SG-8002CA 25.000000 MHz PH |
| Alphacool ES | Datasheet + manual | Standard 3-pin fan connector; NTC 0.53-194 kΩ (10 kΩ at 25 °C) |

## Resolved: 12 V → 5 V stage

The LD1117S50 (7 V drop, estimated 1.9-4.1 W in a SOT-223, VIN abs max 15 V) was replaced with the
**Diodes AP63205WU-7** 5 V / 2 A synchronous buck, using the datasheet circuit (DS41326 Fig. 1 / Table 3):
4.7 µH (Bourns SRN6045TA-4R7M: 26 mΩ, Isat 6.8 A, Irms 4.5 A), 10 µF + 100 nF input, 2 × 22 µF output,
100 nF bootstrap, EN to VIN, FB to the 5 V output. VIN rating is 3.8-32 V (40 V for 400 ms), which covers the
26 V TVS clamp. Estimated loss at 0.3-0.6 A is 0.1-0.4 W (θJA 89 °C/W, about 10-36 °C rise). The LD1117S33
stays on the 5 V rail (1.7 V headroom, about 0.7 W at 400 mA).

## Supply: Dell XYK93 (Delta DPS-2000EB class)

Reseller listings give about 12.2 V at about 164 A (200-240 V mains in) and a 12 V standby rail rated 3.5 A. Check
the Delta DPS-2000EB datasheet for the exact figures and the PS_ON pinout (I could not find it).

* **Use the main 12 V rail** with PS_ON held low (breakout board). The standby rail is limited to 3.5 A, which is tight
  for the fans and pump. The LTC2954 button still works, because it switches the board's own supply.
* **Fault current:** the supply can deliver about 160 A, so the 5 A SMD fuse (F1) is a backup only; confirm its
  DC breaking capacity in the chosen part's datasheet. Add an **inline high-breaking-capacity fuse (7.5-10 A, for example an
  automotive blade fuse) at the PSU end** of the cable.
* **Standby LED current** (about 25 mA, 0.3 W) is not a concern on a mains-powered supply.
* The 12.2 V level is inside every regulator's limits (AP63205 3.8-32 V, LTC2954 2.7-26.4 V, IRF4905 55 V).

## Open issues

1. Power LED draws about 25 mA from VIN in standby (the CL25 current is always flowing); acceptable on this supply.
2. *Resolved:* ACS37800 chip-select moved from GPIO43 (U0TXD, toggles with ROM boot messages) to **GPIO17**
   (`pin_config.h` updated), and 10 kΩ pull-ups to 3V3 on the ISO7741 CS, SCLK and MOSI inputs give defined idle
   levels while the ESP32 GPIOs float in reset.
2. Order the AP63205 as **AP63205WU-7** (fixed 5 V, 1.1 MHz); the 5 V buck switches with ±6% spread spectrum,
   so keep the SW node and input loop small on the PCB.

## Not verifiable from a datasheet I could read

* **LM4040 accuracy grade:** choose the A or B grade for the DAC reference.
* **MIE1W0505 footprint:** your vendor model (SnapEDA); I checked pad names, not the land pattern.
* **SPI modes** (AD9833 mode 2, ACS37800 mode 3, others mode 0/3): set by the firmware libraries.
* **PCB-level items** (creepage between ISO_GND and the logic side, ground returns, copper pours).

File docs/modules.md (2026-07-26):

# Module System

This document covers the module lifecycle pattern, how to create a new module, and how modules are initialised and serviced in `main.cpp`.

---

## Overview

Every subsystem in the firmware is implemented as a C++ **namespace** with free functions. A thin `Module` struct inside each namespace inherits from `ModuleBase<T>` (CRTP) to provide a standardised lifecycle interface that the compiler enforces at build time.

Modules are registered in **declarative arrays** of `ModuleEntry` descriptors. Generic helpers (`initGroup`, `serviceWithLog`, `reportStatus`) drive init and service loops from these arrays — no per-module boilerplate in `main.cpp`.

**Key files:**

| File | Role |
|---|---|
| `include/module.h` | CRTP base, enums, traits, registry helpers |
| `src/main.cpp` | Module arrays, init groups, service loop |

---

## Lifecycle

Every module goes through two phases:

### 1. Initialisation (init)

Called once during `setup()`. Returns an `InitStatus`:

| Status | Meaning |
|---|---|
| `MODULE_INIT_NOT_STARTED` | `init()` has not been called yet |
| `MODULE_INIT_IN_PROGRESS` | Still running (calibration, WiFi, etc.) |
| `MODULE_INIT_SUCCESS` | Completed successfully |
| `MODULE_INIT_HARDWARE_ERROR` | Hardware device failed to respond (I2C/SPI NACK) |
| `MODULE_INIT_DEPENDENCY_ERROR` | A required dependency is unavailable |
| `MODULE_INIT_CONFIG_ERROR` | Invalid or missing configuration |
| `MODULE_INIT_TIMEOUT` | Exceeded allowed time budget |
| `MODULE_INIT_UNKNOWN_ERROR` | Catch-all |

### 2. Service (service)

Called every `loop()` tick. Returns a `ServiceStatus`:

| Status | Meaning |
|---|---|
| `MODULE_SERVICE_NOT_STARTED` | `service()` has not been called yet |
| `MODULE_SERVICE_OK` | Ran and produced valid output this tick |
| `MODULE_SERVICE_SKIPPED` | Skipped this tick (time-gated, disabled, no new data) |
| `MODULE_SERVICE_ERROR` | A recoverable error occurred; output may be stale |

---

## Creating a New Module

### Step 1: Define the namespace and functions

```cpp
// include/mymodule.h
#pragma once
#include "module.h"

namespace mymodule {

module::InitStatus    init();
module::ServiceStatus service();
float getValue();

// ── Module adapter ──────────────────────────────────────────────
struct Module : ModuleBase<Module> {
    static module::InitStatus    init()    { return _initStatus = mymodule::init(); }
    static module::ServiceStatus service() { return _serviceStatus = mymodule::service(); }
};

ASSERT_MODULE_INTERFACE(Module);

} // namespace mymodule
```

### Step 2: Implement the functions

```cpp
// src/mymodule.cpp
#include "mymodule.h"
#include "hardware.h"
#include "logger.h"

static LogStream _Log = Log.createChildLogger("mymodule");

namespace mymodule {

module::InitStatus init() {
    // Hardware setup, calibration, etc.
    TwoWire& i2c = hardware::i2c();
    i2c.beginTransmission(0x42);
    if (i2c.endTransmission() != 0) {
        return module::MODULE_INIT_HARDWARE_ERROR;
    }
    _Log.println("Sensor detected");
    return module::MODULE_INIT_SUCCESS;
}

module::ServiceStatus service() {
    // Non-blocking periodic work
    // ...
    return module::MODULE_SERVICE_OK;
}

float getValue() { return 42.0f; }

} // namespace mymodule
```

### Step 3: Register in main.cpp

Add the module to the appropriate array:

```cpp
#include "mymodule.h"

// Add to the appropriate group:
static const module::ModuleEntry persistentModules[] = {
    // ... existing entries ...
    MODULE_ENTRY(mymodule, false),   // false = non-fatal init failure
};
```

That's it. The module will be automatically initialised, serviced, and included in the boot status banner.

### Key rules

1. **`init()` must cache its result** by assigning to `_initStatus`:
   ```cpp
   static module::InitStatus init() { return _initStatus = mymodule::init(); }
   ```

2. **`service()` must cache its result** by assigning to `_serviceStatus`:
   ```cpp
   static module::ServiceStatus service() { return _serviceStatus = mymodule::service(); }
   ```

3. **`service()` must not block.** Use time-gating, state machines, or async patterns for long operations.

4. **Use `ASSERT_MODULE_INTERFACE(Module);`** after the struct definition. This produces a clear compile error if `init()` or `service()` is missing or has the wrong return type.

---

## Module Registry

### ModuleEntry struct

A type-erased descriptor with function pointers — no vtable, no heap allocation:

```cpp
struct ModuleEntry {
    const char*    name;
    InitStatus     (*initFn)();
    InitStatus     (*getInitStatus)();
    ServiceStatus  (*serviceFn)();
    ServiceStatus  (*getServiceStatus)();
    bool           fatal;   // true = halt startup if init fails
};
```

### MODULE_ENTRY macro

Creates a `ModuleEntry` from any namespace containing a conforming `Module` struct:

```cpp
MODULE_ENTRY(cooling, false)
// expands to:
// { "cooling", cooling::Module::init, cooling::Module::getInitStatus,
//   cooling::Module::service, cooling::Module::getServiceStatus, false }
```

### Helper functions

All three are templates that accept any printf-style log function:

| Function | Purpose |
|---|---|
| `module::initGroup(entries, count, emitFn, logFn, yieldFn)` | Initialise every module in an array. Logs before/after each init. Calls optional `emitFn` (e.g. `telemetry::emitSafe`) after each step for dashboard progress. Calls optional `yieldFn` to feed the FreeRTOS watchdog. Returns `false` if any fatal entry fails. |
| `module::serviceWithLog(entry, prevStatus, logFn)` | Service a module and log only on health-status transitions (healthy ↔ unhealthy). Prevents per-tick spam. |
| `module::reportStatus(entries, count, logFn)` | Print the boot banner — lists all modules that failed to init. Returns the failure count. |

---

## Module Groups in main.cpp

Modules are organised into four arrays. **Order within each array encodes dependency constraints.**

### Persistent modules

Initialised once at boot. Never re-initialised on `reinit`. These provide the communication path (console, dashboard, telemetry) that the operator uses to issue commands.

```mermaid
flowchart LR
    logger --> imu --> commands --> ota --> dashboard --> espnow["espnow
    (conditional)"] --> telemetry --> sysinfo

    classDef mod fill:#dbeafe,stroke:#3b82f6,color:#1e3a5f
    classDef cond fill:#e0e7ff,stroke:#6366f1,color:#312e81,stroke-dasharray: 5 5
    class logger,imu,commands,ota,dashboard,telemetry,sysinfo mod
    class espnow cond
```

- OTA before dashboard (routes must be registered before the HTTP server starts)
- dashboard before espnow (WiFi must be up)

### Control modules

Re-initialised on every FSM `reinit()` (entering the Initialize state). This allows hardware peripherals to be reconfigured after a logical system reset without a full MCU reboot.

```mermaid
flowchart LR
    compressor["compressor
    (conditional)"] --> cooling --> amplifier --> cold_head

    classDef mod fill:#dcfce7,stroke:#16a34a,color:#14532d
    classDef cond fill:#dcfce7,stroke:#16a34a,color:#14532d,stroke-dasharray: 5 5
    class cooling,amplifier,cold_head mod
    class compressor cond
```

- compressor first (de-energise relay as early as possible)

### Tick-service modules

Serviced every `loop()` iteration with health-transition logging:

```mermaid
flowchart LR
    sysinfo --> imu --> amplifier --> cooling

    classDef mod fill:#e0e7ff,stroke:#6366f1,color:#312e81
    class sysinfo,imu,amplifier,cooling mod
```

### Boot banner

A combined array of all modules (including special-cased ones) used for the one-time status report on the first `loop()` iteration.

---

## Special-Cased Modules

These modules don't fit the uniform init/service signature and remain hand-coded in `main.cpp`:

| Module | Reason |
|---|---|
| `hardware` | Fatal init — halts startup if it fails. Initialised before all other modules. |
| `indicator` | Must init before WiFi to avoid `neopixelWrite()` deadlock on ESP32-S3. Has its own timer-driven `update(nowMs)` in the loop. |
| `state_machine` | Non-standard `update(tempC, coolingRate, rmsV, stalled, nowMs, overstroke, sysVoltage)` signature. Returns actuator targets. |
| `telemetry` | `emit(out)` takes `state_machine::Output` as input. `emitSafe()` is used during init for dashboard progress. |
| `cold_head` | In the time-gated section of the loop, before `state_machine::update()`. Includes fault checking internally. |
| `sensor_mock` | No `Module` struct. Called once per gated tick to advance mock ramps before module reads. |
| `commands` | Serviced unconditionally every tick (before the time gate) so the console is always reachable. |

---

## Init Flow (setup)

```mermaid
flowchart TD
    S([setup]) --> HW["hardware::Module::init()
    FATAL — halts on failure"]
    HW --> IND["indicator::Module::init()
    before WiFi"]

    IND --> PM[initPersistentModules]
    PM --> PMG["module::initGroup(persistentModules)
    logger → imu → commands → ota →
    dashboard → espnow → telemetry → sysinfo"]

    PMG --> SM["state_machine::Module::init()
    pure logic, always succeeds"]

    SM --> RI[state_machine::reinit]
    RI --> CM[initControlModules]
    CM --> CMG["module::initGroup(controlModules)
    compressor → cooling →
    amplifier → cold_head"]

    classDef fatal fill:#fee2e2,stroke:#ef4444,color:#7f1d1d
    classDef special fill:#fef3c7,stroke:#d97706,color:#78350f
    classDef group fill:#dbeafe,stroke:#3b82f6,color:#1e3a5f
    classDef control fill:#dcfce7,stroke:#16a34a,color:#14532d

    class HW fatal
    class IND,SM special
    class PM,PMG group
    class CM,CMG control
```

## Service Flow (loop)

```mermaid
flowchart TD
    L([loop]) --> CMD["commands::Module::service()
    unconditional — console always reachable"]

    CMD --> TICK["tickServiceModules[]
    sysinfo → imu → amplifier → cooling
    serviceWithLog — logs only health transitions"]

    TICK --> I2C["hardware::serviceI2c(nowMs)
    I2C error monitor + bus recovery"]
    I2C --> LED["indicator::update()
    at INDICATOR_UPDATE_INTERVAL_MS cadence"]

    LED --> GATE{LOOP_INTERVAL_MS
    gate}
    GATE -->|not yet| RET([return])
    GATE -->|elapsed| MOCK["sensor_mock::service()
    advance mock ramps"]

    MOCK --> CH["cold_head::service()
    read RTD + fault check"]
    CH --> FSM["state_machine::update(...)
    returns actuator targets"]
    FSM --> ACT["indicator::setFaultMode / setReadyMode
    compressor::Module::service"]
    ACT --> TEL["telemetry::emit(out)
    dashboard::Module::service"]

    classDef always fill:#dbeafe,stroke:#3b82f6,color:#1e3a5f
    classDef tick fill:#e0e7ff,stroke:#6366f1,color:#312e81
    classDef infra fill:#f1f5f9,stroke:#94a3b8,color:#334155
    classDef gated fill:#dcfce7,stroke:#16a34a,color:#14532d
    classDef exit fill:#f1f5f9,stroke:#cbd5e1,color:#64748b

    class CMD always
    class TICK tick
    class I2C,LED infra
    class MOCK,CH,FSM,ACT,TEL gated
    class RET exit
```

---

## Optional Interface

`ModuleBase<T>` provides default implementations for optional methods. Override only what you need:

| Method | Default | Override when... |
|---|---|---|
| `service()` | Returns `SERVICE_SKIPPED` | Module has periodic work |
| `enable()` | No-op | Module output can be suspended |
| `disable()` | No-op | Module output can be suspended |
| `isEnabled()` | Returns `true` | Module tracks enabled state |

### Status queries (provided by ModuleBase, no override needed)

| Method | Returns |
|---|---|
| `getInitStatus()` | Cached `InitStatus` from last `init()` call |
| `isInitialized()` | `true` if init status is `SUCCESS` |
| `getServiceStatus()` | Cached `ServiceStatus` from last `service()` call |
| `overrideInitStatus(s)` | Override cached status (for deferred/hot-plug init) |

---

## Deferred (Hot-Plug) Initialisation

Some hardware (e.g. the EMC2303 fan controller) may not be powered at boot. The pattern for handling this:

1. `init()` returns `MODULE_INIT_HARDWARE_ERROR` when the device is absent.
2. `service()` checks `Module::getInitStatus() != SUCCESS` and periodically retries.
3. On success, call `Module::overrideInitStatus(MODULE_INIT_SUCCESS)` to promote the module.
4. On I2C failure, call `hardware::reportI2cError()` and `hardware::recoverI2c()` to free the shared bus.

See `src/cooling.cpp` for a complete example.

---

## Compile-Time Enforcement

### Trait detection

`module_traits::is_module<T>` returns `true` at compile time if `T` has both `init()` and `service()` with the correct return types. Used internally by `ASSERT_MODULE_INTERFACE`.

### ASSERT_MODULE_INTERFACE(Module)

Place this immediately after your `Module` struct definition. It produces a descriptive static_assert failure if the interface is not satisfied:

```
error: static assertion failed: Module does not satisfy the Module interface:
       must provide static module::InitStatus init()
       and static module::ServiceStatus service()
```

---

## Conventions

- **Namespace = module name.** The namespace name is used in log output, serial commands, and the boot banner.
- **One `.cpp` + one `.h` per module.** The header declares the public API; the implementation file is self-contained.
- **Static state.** Module state is file-scope `static` variables in the `.cpp` file. No globals, no singletons.
- **Child loggers.** Each module creates `static LogStream _Log = Log.createChildLogger("name");` for prefixed log output.
- **Bus access via `hardware::`** — never use the global `Wire` or `SPI` directly.
- **Mock support.** When `sensor_mock::isActive()`, skip hardware reads and pull values from `sensor_mock::get()` instead.
- **Non-blocking.** `service()` must return promptly. Use state machines or time-gating for multi-step operations.

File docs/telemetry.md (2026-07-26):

# Adding a New Telemetry Field

This document walks through every file that must be touched to add a new
telemetry value end-to-end.  The system has **two independent output paths**
that both need updating:

| Path | Transport | Encoder | Decoder |
|---|---|---|---|
| **Serial Studio / HTTP JSON** | Serial (CSV) + TCP + HTTP GET | `FrameBuilder` in `telemetry.cpp` | Serial Studio project / browser `JSON.parse()` |
| **WebSocket binary** | WebSocket | Nanopb in `telemetry_pb.cpp` | protobufjs in `decodeTelemetry.ts` |

Both paths share the same dot-notation key convention (`group.field_name`).

---

## Worked Example

We'll add a hypothetical field `cooling.pump_pressure_bar` (a float read from
`cooling::getPumpPressure()`).

---

## Step 1 — src/telemetry.cpp: emit() and buildStartupFrame()

`emit()` is called once per control tick (1 Hz) and populates `lastFrame_`.
`buildStartupFrame()` is the startup slow-path that is used before the first
`emit()` completes.  Both must be kept in sync.

### 1a — emit()

Find the `cooling.*` block and add your field:

```cpp
// src/telemetry.cpp  ~line 600
lastFrame_
    ...
    .field("cooling.pump_rpm",       "%u",   cooling::getPumpRPM())
    .field("cooling.pump_pressure_bar", "%.2f", cooling::getPumpPressure())  // ← add
    ...
```

`FrameBuilder::field(name, fmt, value)` accepts any numeric or string type.
The format string controls both the Serial Studio output and how the value is
stored internally (float/int/string determines the JSON type).

### 1b — buildStartupFrame()

The same field must appear in `buildStartupFrame()` so the HTTP dashboard gets
a valid structure even during startup.  If the module might not be ready yet,
guard it:

```cpp
// src/telemetry.cpp  ~line 298 (inside the coolingReady block)
if (coolingReady) {
    frame
        ...
        .field("cooling.pump_rpm",          "%u",   cooling::getPumpRPM())
        .field("cooling.pump_pressure_bar", "%.2f", cooling::getPumpPressure())  // ← add
        ...
} else {
    frame
        ...
        .field("cooling.pump_rpm",          "%s", "")
        .field("cooling.pump_pressure_bar", "%s", "")  // ← add (empty sentinel)
        ...
}
```

### 1c — (Optional) Delta-mode passive list

If the field changes every tick and should **not** trigger a Serial Studio line
on its own (e.g. a slowly-drifting value), add it to `kPassiveFields[]` near
the top of `telemetry.cpp`:

```cpp
static const char* const kPassiveFields[] = {
    ...
    "cooling.pump_pressure_bar",   // ← add if it's noisy/continuous
};
```

### 1d — Check FrameBuilder::MAX_FIELDS

If the build produces a compile-time assertion failure about field count, bump
the limit in `include/frame_builder.h`:

```cpp
static constexpr uint8_t MAX_FIELDS = 130;  // increase if needed
```

Count fields by searching for `.field(` calls across both `emit()` and
`buildStartupFrame()`.

---

## Step 2 — proto/telemetry.proto: Schema definition

The `.proto` file is the single source of truth for the WebSocket binary
format.  Every field must live inside a **message** that maps to a dot-notation
prefix.

### Adding to an existing message

```protobuf
// proto/telemetry.proto
message Cooling {
  int32  status        = 1;
  int32  pump_on       = 2;
  float  temp_c        = 3;
  float  flow_rate_lpm = 4;
  uint32 fan_speed     = 5;
  uint32 fan_rpm       = 6;
  uint32 pump_speed    = 7;
  uint32 pump_rpm      = 8;
  float  pump_pressure_bar = 9;   // ← add; next available field number
}
```

> **Field numbers are permanent.**  Never renumber or reuse a field number
> after the firmware has been deployed — doing so silently corrupts decoding
> on old clients.  Always append using the next available number.

### Adding to a new message / group

If you need a brand-new group prefix (e.g. `vacuum.*`):

1. Add the new message to `telemetry.proto`:

```protobuf
message Vacuum {
  float pressure_mbar = 1;
  float pump_speed    = 2;
}
```

2. Add a field for it in `TelemetryFrame`:

```protobuf
message TelemetryFrame {
  ...
  Vacuum vacuum = 16;   // next available field number in TelemetryFrame
}
```

### String fields

If the field is a string, add an entry to `proto/telemetry.options` to set a
fixed maximum size (required by Nanopb to avoid heap allocation):

```
cryocooler.Cooling.pump_label   max_size:24
```

---

## Step 3 — Delete stale generated files

After editing `.proto`, the generated C and JS stubs are stale.  Delete them
so the build pipeline regenerates them unconditionally:

```bash
rm src/generated/telemetry.pb.c
rm include/generated/telemetry.pb.h
rm dashboard/src/generated/telemetry.js
rm dashboard/src/generated/telemetry.d.ts
```

The next `pio run` will regenerate all four files automatically via
`scripts/compile_proto.py` (C stubs) and `npm run proto:build` (JS stubs).

---

## Step 4 — src/telemetry_pb.cpp: Nanopb encoder

This file populates the Nanopb struct that is encoded and sent over WebSocket.
It reads from the same module getters as `telemetry.cpp` but fills struct
fields rather than calling `FrameBuilder::field()`.

```cpp
// src/telemetry_pb.cpp  — inside the cooling section
frame_.has_cooling = true;
frame_.cooling.status        = cooling::isEnabled() ? 1 : 0;
...
frame_.cooling.pump_rpm      = cooling::getPumpRPM();
frame_.cooling.pump_pressure_bar = cooling::getPumpPressure();   // ← add
```

The struct field names are generated from the `.proto` field names in
snake_case (e.g. `pump_pressure_bar` → `frame_.cooling.pump_pressure_bar`).

> **For new top-level messages** you also need to set the `has_<message>` flag
> and initialise the nested struct, following the pattern used by
> `frame_.has_cooling`, `frame_.has_system`, etc.

---

## Step 5 — dashboard/src/types/telemetry.ts: TypeScript interface

Add the new field to the appropriate nested interface so TypeScript knows about
it:

```typescript
// dashboard/src/types/telemetry.ts
cooling?: {
  status?: number;
  pump_on?: number;
  temp_c?: number;
  flow_rate_lpm?: number;
  fan_speed?: number;
  fan_rpm?: number;
  pump_speed?: number;
  pump_rpm?: number;
  pump_pressure_bar?: number;   // ← add
};
```

For a new group, add an entirely new interface property:

```typescript
vacuum?: {
  pressure_mbar?: number;
  pump_speed?: number;
};
```

---

## Step 6 — dashboard/src/utils/decodeTelemetry.ts: Protobuf → TypeScript mapping

Map the protobufjs-generated camelCase property to the snake_case TypeScript
field.  protobufjs converts `pump_pressure_bar` → `pumpPressureBar`
automatically.

```typescript
// dashboard/src/utils/decodeTelemetry.ts
if (f.cooling) {
  out.cooling = {
    ...
    pump_rpm:           f.cooling.pumpRpm     ?? undefined,
    pump_pressure_bar:  f.cooling.pumpPressureBar ?? undefined,   // ← add
  };
}
```

For a new top-level message:

```typescript
if (f.vacuum) {
  out.vacuum = {
    pressure_mbar: f.vacuum.pressureMbar ?? undefined,
    pump_speed:    f.vacuum.pumpSpeed    ?? undefined,
  };
}
```

> **camelCase rule:** protobufjs converts every snake_case proto field name to
> camelCase on the JS side.  `pump_pressure_bar` → `pumpPressureBar`,
> `flow_rate_lpm` → `flowRateLpm`, etc.

---

## Step 7 — include/dashboard_config.h: Serial Studio layout

Add a `DatasetCfg` entry in the appropriate group array so the field appears
in the Serial Studio desktop dashboard:

```cpp
// include/dashboard_config.h  — inside coolingDatasets[]
{
    .title          = "Pump Pressure",
    .units          = "bar",
    .telemetryKey   = "cooling.pump_pressure_bar",
    .widget         = ss::WidgetType::Gauge,
    .widgetMin      = 0,
    .widgetMax      = 10,
    .alarmLow       = 0,
    .alarmHigh      = 8,
    .alarmEnabled   = true,
    .graph          = true,
    .log            = true,
    .overviewDisplay = true,
},
```

The `telemetryKey` must exactly match the dot-notation key used in
`FrameBuilder::field()` in `telemetry.cpp`.

For a new group, add a new `DatasetCfg` array and a new `GroupCfg` entry in
`dataGroups[]`.

---

## Step 8 — Web dashboard (optional)

These are only needed if you want the field visible in the Preact dashboard.

### 8a — History buffer (App.tsx)

To record a rolling 100-sample history for use in a chart, add the key to
`HISTORY_KEYS`:

```typescript
// dashboard/src/App.tsx
const HISTORY_KEYS = [
  ...
  'cooling.pump_pressure_bar',   // ← add
] as const;
```

### 8b — Quick-read tile (App.tsx)

To show the value as a large numeric tile in the top row:

```typescript
// dashboard/src/App.tsx
const TILES: TileConfig[] = [
  ...
  { label: 'Pump P', key: 'cooling.pump_pressure_bar', unit: 'bar', dp: 2, color: '#80cbc4' },
];
```

### 8c — Chart component

Pass the history buffer slice to whichever chart component is appropriate, or
create a new one.  Use `getHistory('cooling.pump_pressure_bar')` to retrieve
the data.

---

## Summary Checklist

| # | File | What to do |
|---|---|---|
| 1a | `src/telemetry.cpp` — `emit()` | Add `.field("group.key", "fmt", getter())` |
| 1b | `src/telemetry.cpp` — `buildStartupFrame()` | Same field, with empty-string sentinel in the `else` branch |
| 1c | `src/telemetry.cpp` — `kPassiveFields[]` | Add key if it should not trigger delta output on its own |
| 1d | `include/frame_builder.h` | Bump `MAX_FIELDS` if the assertion fires |
| 2  | `proto/telemetry.proto` | Add field to existing message (or new message + `TelemetryFrame` entry) |
| 2s | `proto/telemetry.options` | Add `max_size` entry for any new string field |
| 3  | Generated stubs | Delete `src/generated/telemetry.pb.c`, `include/generated/telemetry.pb.h`, `dashboard/src/generated/telemetry.{js,d.ts}` |
| 4  | `src/telemetry_pb.cpp` | Populate the new `frame_.<message>.<field>` from the getter |
| 5  | `dashboard/src/types/telemetry.ts` | Add `field?: type` to the appropriate nested interface |
| 6  | `dashboard/src/utils/decodeTelemetry.ts` | Map `f.<message>.<camelCaseField>` to `out.<group>.<snake_case_field>` |
| 7  | `include/dashboard_config.h` | Add `DatasetCfg` entry (and `GroupCfg` if new group) |
| 8a | `dashboard/src/App.tsx` — `HISTORY_KEYS` | Add key for chart history (optional) |
| 8b | `dashboard/src/App.tsx` — `TILES` | Add tile entry for quick-read display (optional) |
| 8c | Dashboard component | Wire `getHistory('group.key')` into a chart (optional) |

---

## Notes

- **Key naming convention:** always `group.field_name` in snake_case.  The
  group prefix must match the proto message name used in `TelemetryFrame`
  (converted to snake_case: `ColdHead` → `cold_head`).
- **Proto field numbers:** append-only, never reuse.  Check the highest
  existing number in the message before adding.
- **`int64`/`uint64` proto fields:** protobufjs returns these as `Long` objects.
  Use the `toLong()` helper in `decodeTelemetry.ts` when mapping them.
- **Build shortcut:** set `SKIP_DASHBOARD_BUILD=1` in your environment to skip
  the full npm/Vite build and iterate on firmware-only changes faster:
  ```bash
  SKIP_DASHBOARD_BUILD=1 pio run
  ```

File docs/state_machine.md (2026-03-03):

# Cryocooler State Machine

## Diagram

### Normal Operation Flow

`start()` selects the resume state from `tempK` and is valid from both **Off**
and **Idle**; only the Idle transitions are shown to reduce clutter.  `Delay`
is reachable from any non-Fault state via `startDelay()` — see
[Global Transitions](#global-transitions-any-state).

```mermaid
stateDiagram-v2
    direction TB

    [*] --> Off
    Off  --> Initialize : reinit
    Idle --> Initialize : reinit
    Initialize --> Idle : init timer

    state "Cooldown Phase" as COOLDOWN {
        CoarseCooldown --> FineCooldown : temp < 85 K
        FineCooldown --> CoarseCooldown : temp > 85 K
    }

    state "Approaching Setpoint" as SETTLING {
        Overshoot --> Settle : in band
    }

    state "Stable Operation" as STABLE {
        Baseline --> Operating : baseline timer
    }

    Idle --> CoarseCooldown : start, temp ≥ 85 K
    Idle --> FineCooldown   : start, below 85 K
    Idle --> Overshoot      : start, below setpoint
    Idle --> Settle         : start, in band

    FineCooldown --> Overshoot : below setpoint
    FineCooldown --> Settle    : in band

    Settle --> Baseline : settle timer

    COOLDOWN --> Shutdown : stop
    SETTLING --> Shutdown : stop
    STABLE   --> Shutdown : stop
    Delay    --> Shutdown : stop
    Shutdown --> Idle     : shutdown timer

    Delay --> Idle           : timer → Idle
    Delay --> CoarseCooldown : timer → Coarse
```

### Fault Conditions

Three fault types — **RMS overvoltage**, **low system voltage**, and **state
oscillation** — fire from *any* non-Fault state and are listed in the
[Global Transitions](#global-transitions-any-state) table.  The diagram below
shows the state-specific faults; composite groupings match the normal-flow
diagram.

```mermaid
stateDiagram-v2
    direction TB

    state "Cooldown Phase" as COOLDOWN {
        CoarseCooldown
        FineCooldown
    }

    state "Approaching Setpoint" as SETTLING {
        Overshoot
        Settle
    }

    state "Stable Operation" as STABLE {
        Baseline
        Operating
    }

    COOLDOWN --> Fault : temp stall
    COOLDOWN --> Fault : too many backoffs
    SETTLING --> Fault : too many backoffs
    STABLE   --> Fault : too many backoffs
    Delay    --> Fault : too many backoffs

    Fault --> Idle       : clearFault()
    Fault --> Initialize : reinit()
```

---

## Global Transitions (any state)

These transitions originate from all non-Fault states and are omitted from the
diagram above to keep it readable.

| Trigger | Condition | To | FaultReason |
|---|---|---|---|
| `off()` | — | Off | — |
| RMS overvoltage | `amplifier RMS V > AMPLIFIER_MAX_VOLTAGE` | Fault | `RmsOvervoltage` |
| Low system voltage | `systemVoltage > 0` and `systemVoltage < MIN_SYSTEM_VOLTAGE_VDC` | Fault | `LowSystemVoltage` |
| State oscillation | FSM alternates between same two states >= `FSM_OSCILLATION_MIN_CYCLES` times within `FSM_OSCILLATION_WINDOW_MS` | Fault | `StateOscillation` |
| `startDelay()` | — | Delay | — |

---

## State Reference

| State | Value | Relay | FAULT indicator | READY indicator | DAC target |
|---|:-:|---|---|---|---|
| Off | -1 | Bypass | Off | Off | 0 |
| Initialize | 0 | Bypass | Solid Amber | Solid Amber | 0 |
| Idle | 1 | Bypass | Solid Red | Off | 0 |
| CoarseCooldown | 2 | Bypass | Flash Fast Red | Off | proportional to temp |
| FineCooldown | 3 | Bypass | Flash Fast Red | Flash Slow Green | proportional to temp |
| Overshoot | 4 | Bypass | Flash Fast Red | Flash Fast Green | 0 |
| Settle | 5 | **Normal** | Flash Fast Red | Flash Fast Green | 0 |
| Baseline | 6 | **Normal** | Off | Solid Green | 0 |
| Operating | 7 | **Normal** | Off | Solid Green | 0 |
| Shutdown | 8 | Bypass | Off | Off | ramping to 0 (fast) |
| Delay | 9 | Bypass | Solid Amber | Solid Amber | 0 |
| Fault | 127 | Bypass + **Alarm** | Flash Fast Red | Off | 0 |

The DAC target is computed proportional to how far `tempK` has dropped from
`AMBIENT_START_K` toward `SETPOINT_K`, and is only non-zero during
CoarseCooldown and FineCooldown.  The amplifier ramps toward the target each
tick; Shutdown uses a faster ramp rate via `amplifier::rampTowardShutdown()`.

---

## Fault Reference

| FaultReason | Value | Trigger | Originating states |
|---|:-:|---|---|
| RmsOvervoltage | 1 | `amplifier::getLastRmsVoltage() > AMPLIFIER_MAX_VOLTAGE` | Any non-Fault |
| TemperatureStall | 2 | Stall-detect window expired without sufficient temp drop | CoarseCooldown, FineCooldown |
| TooManyBackoffs | 3 | `backoffCount >= BACKOFF_MAX_COUNT` | All running states |
| LowSystemVoltage | 4 | `systemVoltage < MIN_SYSTEM_VOLTAGE_VDC` (0.0 ignored) | Any non-Fault |
| StateOscillation | 5 | FSM oscillation detector fired | Any non-Fault |

Fault is a **terminal state**. The only exits are `clearFault()` to Idle and
`reinit()` to Initialize. Both paths reset `faultReason`, `backoffCount`, and
`backoffDacOffset`.

---

## Behavioural Notes

**start() resume logic** — The starting state is chosen from the current
cold-stage temperature so the system resumes correctly after a power cycle
without triggering spurious stall faults.  `start()` is valid from both Off
and Idle with identical temperature-based branching.

**Settle timer** — The timer only advances while the temperature is inside the
setpoint band (`SETPOINT_K +/- SETPOINT_TOLERANCE_K`).  Any excursion out of
band resets the timer to zero; the full `SETTLE_DURATION_MS` must elapse
continuously in-band before the transition to Baseline fires.

**Back-EMF backoff** — Each overstroke event detected by the IMU reduces the
effective DAC target by `BACKOFF_DAC_STEP`.  The penalty accumulates until
`BACKOFF_MAX_COUNT` is reached, at which point the `TooManyBackoffs` fault is
triggered.  The offset and counter both reset on `clearFault()` and `reinit()`.

**Delay state** — A generic timed hold reachable from any non-Fault state via
`startDelay(nowMs, durationMs, nextState)`.  The destination is either Idle or
CoarseCooldown; any other value defaults to Idle.  `stop()` can interrupt a
pending delay.

**Fault is terminal** — The only exits are `clearFault()` to Idle and
`reinit()` to Initialize.  Both reset `faultReason`, `backoffCount`, and
`backoffDacOffset`; `reinit()` additionally re-runs all hardware module inits
via the registered `onInitializeCallback`.

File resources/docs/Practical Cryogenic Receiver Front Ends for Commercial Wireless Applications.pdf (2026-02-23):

# Practical Cryogenic Receiver Front Ends for Commercial Wireless Applications

### Balam A. Willemsen

### Superconductor Technologies Inc., Santa Barbara, California 93111, USA

Abstract — Long-life, high-reliability cryocoolers, developed in the past decade, have allowed for the limited deployment of cryogenic microwave electronics in commercial wireless networks. We survey some of the background leading to current CRFEs and experience learned from early deployments. System reliability is a key issue for wireless providers, and must be an inherent consideration for CRFE design. CRFEs can be designed for lower cost by consolidating, eliminating and simplifying parts and assemblies. Here we focus on a new approach for computer aided filter trimming of complex filters in complex RF paths. Finally, we look ahead to other potential advances in CRFEs.

Index Terms — Cryogenic electronics, Land mobile radio equipment, Land mobile radio spectrum management, Circuit tuning.

I. INTRODUCTION

Since the discovery of superconductivity in 1911, there has been interest in making use of the unique electronic properties of materials as they are cooled to extremely low temperatures for practical applications. By the mid 1960s several applications were on the verge of practicality. Yet, for all this time one thing remains true, “cryogenic electronics will only be as useful as the cost and reliability of the refrigeration

permits.” [1] In the radio frequency and microwave arena,

### cryogenics was thus relegated for many decades to high value applications in radio astronomy and satellite communication

where the costs of reliable refrigeration were acceptable.
In the late 1980s, two important changes occurred that led to the work described in this manuscript: The discovery of High Temperature Superconductors (HTS) in 1987, and the evolution and rapid deployment of large terrestrial wireless communications networks. By 1997, the field had matured to the point that limited quantities of Cryogenic Receiver Front Ends (CRFEs) had already been deployed with the wireless providers and had been subjected to life tests by the basestation manufacturers.
Today, over 6,000 CRFEs are in use in North American wireless networks. While several companies, large and small, have pursued this market and developed and tested prototypes, only Superconductor Technologies Inc. (STI) has achieved any measurable level of deployment. The goal of this paper is to summarize some of the key technical design considerations of the most recent generation of STI CRFE, which are all aimed at reducing recurring cost, and thus increasing the practicality of the end product. Much background information can be found in a variety of other sources such as [2] or [3].

II. BENEFITS OF CRFES TO WIRELESS NETWORKS

CRFEs that incorporate HTS, such as the Superlink Rx® offer a unique combination of sensitivity, selectivity and size when compared with other technologies. The sensitivity is mainly provided by cryogenically cooled LNA, which does not add as much noise to the signal as it would if it were not cryogenically cooled. Selectivity is primarily improved by means of the thin-film HTS “brick-wall” filter which is typically not much larger than a postage stamp, while providing the selectivity and loss characteristics of a much larger filter. Of course, the overall system size is not determined by the filters alone, but the overhead of the cryopackaging, cryocooler and controller can be offset by sharing these among some large number of RF paths. A typical CRFE contains 6 filter/LNA paths. The system performance benefits provided by using a CRFE can be particularly significant in today’s CDMA networks which can be particularly sensitive to noise and interference. [4]
STI has performed numerous uplink enhancement trials over a period of 4 years to help quantify these benefits with multiple customers, infrastructure types, regions. In particular, 10 of these trials have been in CDMA networks at 850 MHz. One useful and simple to measure metric that can be looked at is the reduction in handset transmit power, which is an indirect measurement of the base station sensitivity. Over these 10 CDMA 850 trials, the average reduction in handset transmit power was 4.1 dB. More details on how these trials break down in terms of region or infrastructure type are shown in Table I.

TABLE I
SUMMARY OF TRIAL RESULTS FOR STI CRFES IN CDMA 850 MHZ NETWORKS.
Category | Handset transmit power change (dB) | #
Average | -4.1 | 10
Urban | -5.5 | 3
Suburban | -3.5 | 3
Rural | -3.5 | 4
OEM A | -4.3 | 7
OEM B | -4.1 | 2
OEM C | -2.5 | 1
978-1-4244-2804-5/09/$25.00 © 2009 IEEE | 1457 | IMS 2009

III. CRYOCOOLERS AND SYSTEM RELIABILITY

One of the key reasons STI has succeeded where others have not, was the early emphasis on developing our own, compact, low-cost, efficient, high-reliability free-piston Stirling cycle cryocooler[5]. The breakdown of costs of the key subsystems in a typical CRFE is shown in Figure 1. It can clearly be seen that far from an “invisible cryocooler” the cryocooler and its DSP based controller circuit board are a significant, but tolerable 24% of the total system cost. Production volume remains the only way to reduce the cryocooler cost, while various ways to reduce costs in the other areas will be discussed in sections IV-VI.

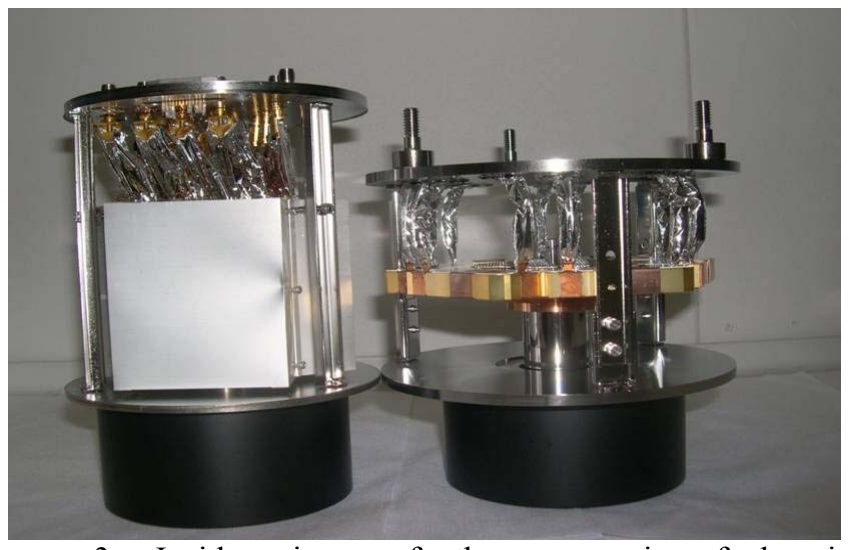
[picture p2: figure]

### As of late 2007, the population of 6,000 deployed cryocoolers in CRFEs had surpassed 200 million cumulative runtime hours. Thus, on average, each cryocooler had been running continuously for over 4 years!

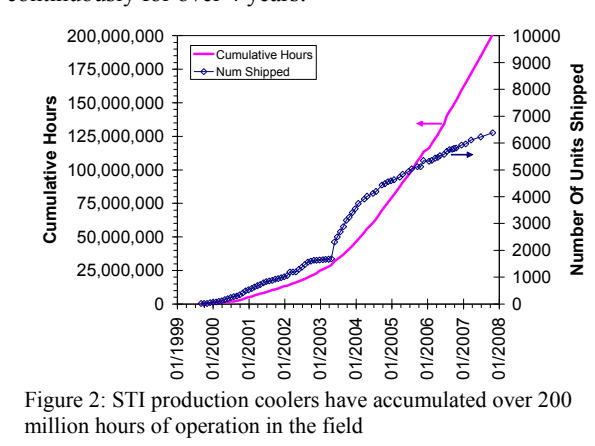
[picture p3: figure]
Cumulative Hours; Number Of Units Shipped; Cumulative Hours Num Shipped; million hours of operation in the field

The overall system MTBF > 500,000 hours is not limited by the cryocooler or the HTS, or even the cryopackaging. Instead, most of the system failures in the field have occurred because of the more conventional components such as the printed circuit boards and the cooling fans.
Of course the relative low-cost and high-reliability of the STI Sapphire crycooler make it attractive for other cryogenic electronic applications. As such, it was selected for use in the

Allen Telescope Array, a radio astronomy project which went online in late 2007.

IV. DESIGN FOR LOW COST

Design for low-cost and high reliability implies eliminating parts and simplifying processes where possible. As initially conceived [10] and deployed in 1997, the STI CRFE was a very complicated assembly requiring many custom machined parts with features from multiple sides. While this is acceptable for satellites or other applications where these costs are dwarfed by other costs, it is not for widespread commercial applications.
Thus, in 2004 we undertook a major effort to redesign the CRFE for lower cost. Since much of the cost of the CRFE is in the cryopackaging, much of the effort was expended there. Much of this simplification can bee seen in Figures 3 and 4, showing pictures of the insides of a 2004 vintage dewar and one from 2008. As can be seen, the assembly has been greatly simplified, with many parts being consolidated and/or eliminated altogether. In particular, many threaded parts, mainly screws and connectors have been eliminated or replaced with spring clips.

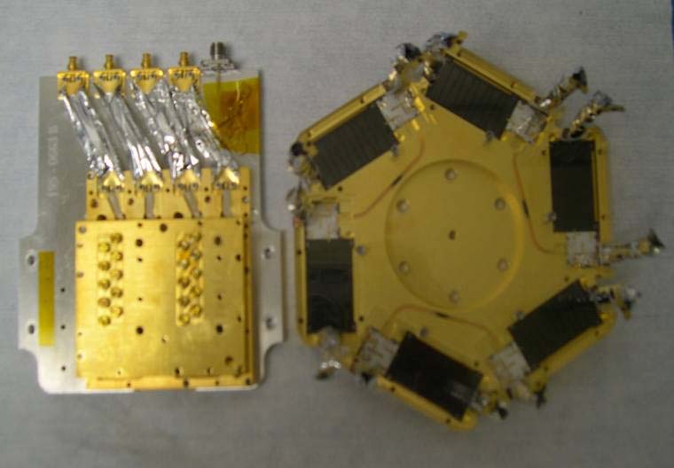
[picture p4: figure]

Figure 4: Expanded views of one of the three microenclosures in a 2004 dewar (left) and a 2008 microenclosure.

Figure 3: Inside views of the cryogenic rf housings (microenclosures) inside 2004 dewar (left) and 2008 dewar (right). The 2008 dewar has been optimized to eliminate parts as compared to the 2004 design.

Figure 2: STI production coolers have accumulated over 200

Cold Circuits,
30%

Cryopackage,
33%

Cooler, 24%

System, 13%

Figure 1. Breakdown of loaded costs of CRFE subsystems as of 2008. The dominant sources of cost are the cold circuits, cryopackaging and cryocooler/controller.

V. FILTER TRIMMING

Another area where this is apparent is in the fine-tuning of the filter. It is very common for high performance filters to make use of mechanical tuning elements to correct for manufacturing tolerances which can affect the center frequency of the filter, as well as its return loss. At STI we initially incorporated dielectric tuners using sapphire cylinders above our filters [11]. These work very well, providing sufficient tuning range to adjust center frequency and return loss. However they still require precise, fine-detail machining to incorporate the fine threads required for fine positioning of the dielectric rod, and since these actuators form an integral part of the RF enclosure, their cost is shipped with the final product.
Another approach was developed at Conductus, where the tuning elements are small pieces of HTS attached to a spring clip[12]. The actuator for the spring clips was designed as a separate piece which could be removed from the part once the filter was tuned. In this way, some of the cost is shifted from the product to the tool required to make the part, which can then be amortized over a large number of products.
In ref. 6 we described an approach for computer aided filter trimming, which allows the filter to be trimmed for center-frequency and return-loss without any additional mechanical tuners. The additional features required for trimming are fabricated along with the filter and thus do not add any cost. This approach leads to well tuned filters in their test housing, but by the time the filters are integrated with the rest of the rf chain required for the system that includes bond-wires, LNAs, cryocables, switches and connectors the return loss of the chain is degraded.
In this respect, the mechanical tuner approach can lead to better system performance, as it allows the filter to be tuned so as to compensate for any mismatches in the other components in the rf chain. As a first approach, the pre-tuned filters were integrated with the rest of the components in the standard mechanically tuned filter housing, removing 8 or 9 of the 10 tuners required for each filter for a substantial reduction in labor and materials cost for trimming each filter.

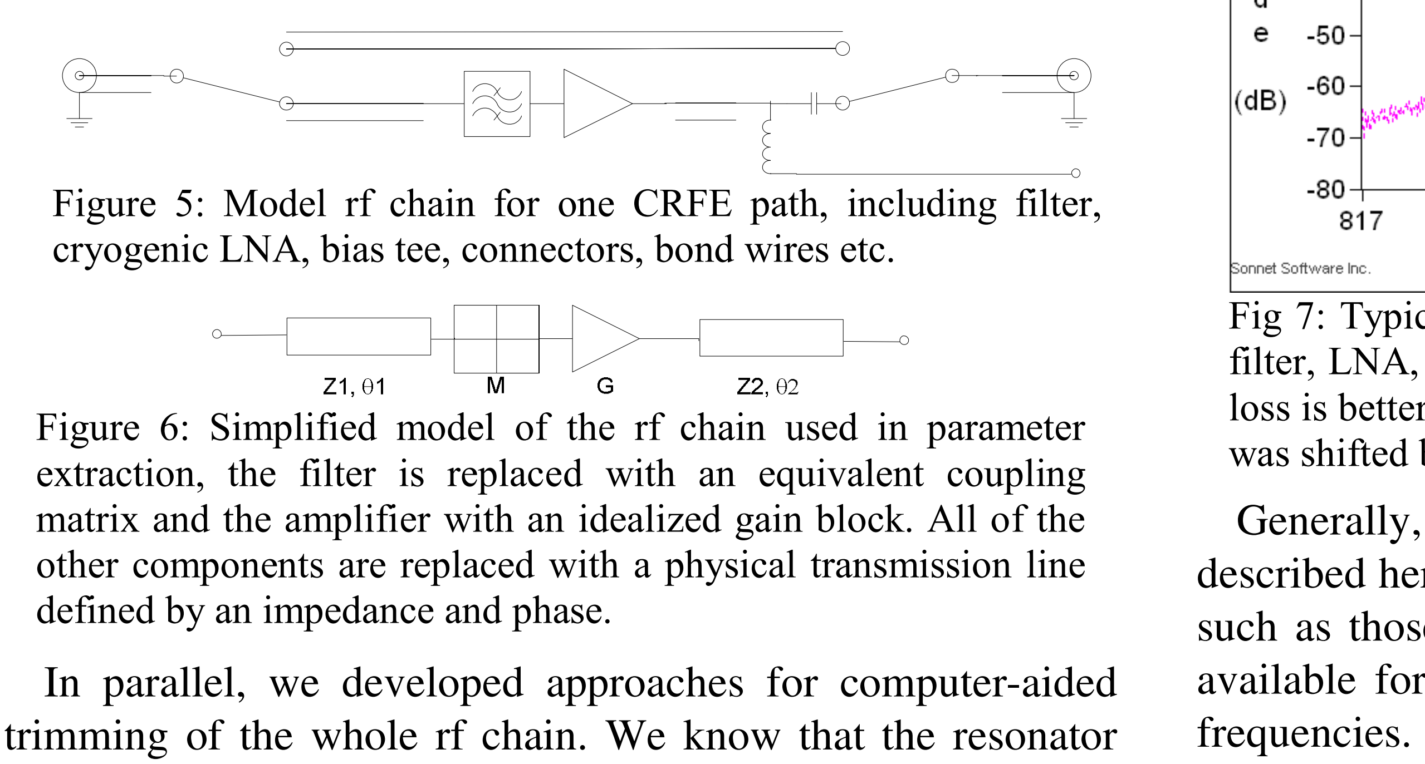
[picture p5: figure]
frequencies.; defined by an impedance and phase.

In parallel, we developed approaches for computer-aided trimming of the whole rf chain. We know that the resonator frequencies alone are sufficient to optimize the rf chain from our mechanical tuning experience, so we should not have to add any additional trimming features to the filters. We add complexity to the objective function used in the curve fitting and consider only S11 and S21 when fitting, as our simplified model of the RF chain does not model S12 or S22 well. As before, we optimize only the resonator frequencies to trim the rf chain, leaving the extracted coupling values, gain and transmission-line parameters constant during the optimization. In practice, this approach leads to as good ot better system return-loss than the mechanical tuner approach with very high yields (>95%). The most significant source of failure in the process is human error, where the wrong recipe is applied to the wrong filter and/or other damage is done to the filter during trimming. Ultimately, in high enough volume, the scribing process itself could be automated to improve yield further.
As such, the filter trimming process which used to take a technician 20-30 minutes per rf path can largely be automated with a technician only required to move the dewar from one station to another.

### 1) Cool down and collect filter S-parameter data 2) Bin filters for similar turn-on characteristics

3) Assemble microenclosure/dewar (filters, LNAs,

cryocables, switches, …) 4) Cool down and collect dewar S-parameters 5) Perform parameter extraction on dewar S-paramters 6) Determine filter trimming recipe 7) Apply filter trimming recipe to set of filters in dewar (manual) 8) Cool down and collect final dewar data 9) Weld dewar for final system integration

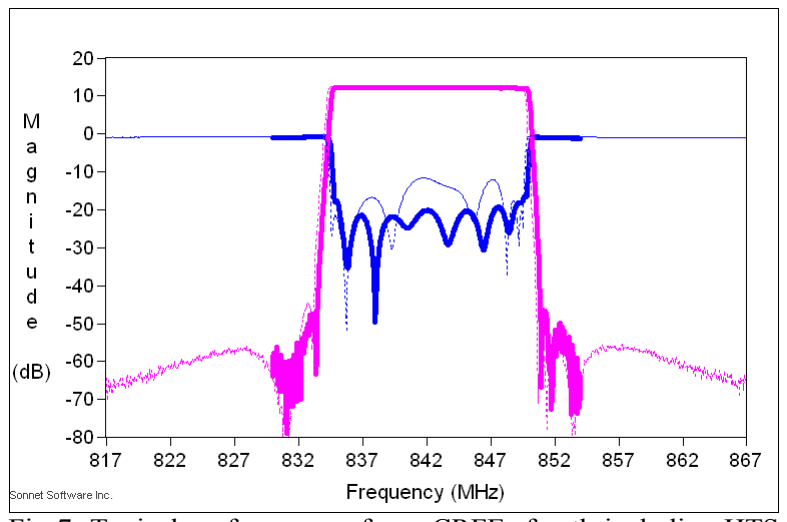
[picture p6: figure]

Generally, the filter analysis and trimming processes described here also work well with dynamically tunable filters such as those described in [9] or [10] where the only knobs available for optimizing the filter response are the resonator

Figure 6: Simplified model of the rf chain used in parameter extraction, the filter is replaced with an equivalent coupling matrix and the amplifier with an idealized gain block. All of the other components are replaced with a physical transmission line

Figure 5: Model rf chain for one CRFE path, including filter, cryogenic LNA, bias tee, connectors, bond wires etc.
Fig 7: Typical performance of one CRFE rf path including HTS filter, LNA, cryocables, switches and connectors. Average return loss is better than -16 dB for the entire path. In this case, the filter was shifted by 300 kHz and optimized for return loss.

VI. FUTURE DIRECTIONS

As was seen in Figure 1, the cold circuits themselves make up a substantial portion of the cost of a CRFE, so efforts to reduce their cost can be beneficial. The cost of the HTS filters is dominated by the cost of the substrate, so that the circuit cost can be affected in three ways. The simplest of these is to reduce the cost of the substrate material itself, i.e. switching from Magnesium Dioxide (MgO) to a more commonly used substrate such as Sapphire. Substrate cost can also be tied to the size of the circuit, which can be reduced either by growing higher performance HTS materials[7] and/or miniaturizing the circuits. We expect that in the coming years, one or more of these approaches will be used to reduce filter cost.
There are also many applications where the transmit side of the link would also benefit from lower losses and sharper filtering, but so far the power levels required have remained out of reach of cryogenic circuits. This may change over the next few years as base station transmit powers drop and by making use of novel circuit approaches[8].

VII. CONCLUSION

Long-life, high-reliability cryocoolers enable the use of cryogenic microwave circuits in commercial wireless networks. For six channel HTS CRFEs like today’s Superlink Rx, the cryocooler does not dominate either system cost or reliability. Other components must also be designed for lower cost by simplification, in particular the cryopackaging. The introduction of computer-aided filter trimming has been an area of substantial improvement for both cost and overall system performance.

ACKNOWLEDGEMENT

The author wishes to acknowledge the assistance and support of everyone at STI, in particular R. B. Hammond, N.
O. Fenzi, E. R. Soares, S. M. Bilski, G. Tsuzuki, A. Karandikar and A. Fiedler for many useful discussions regarding this manuscript.

REFERENCES
[1] Schmitt, R.W., "Poles and zeros: Cryogenic electronics," Proceedings of the IEEE, vol.52, no.10, pp. 1091-1091, Oct. 1964
[2] H. | Weinstock | and | M. | Nisenoff | (eds.), | “Microwave
Superconductivity”, | Proc. | NATO | ASI | on | Microwave
Superconductivity, Millau, France, August 1999, Kluwer, 2001.
[3] R. W. Simon, R. B. Hammond, S. J. Berkowitz, and B. A. Willemsen, “Superconducting microwave filter systems for cellular telephone base stations,” Proc. IEEE, vol. 92, pp. 1585-1596, October 2004.
[4] M. I. Salkola, and D. J. Scalapino, “Benefits of superconducting technology to wireless CDMA networks,” IEEE Trans. Vehicular Tech., vol. 55, pp. 943 – 955, May 2006.
[5] A. O’Baid, A. Fiedler, and A. Karandikar, “STI’s Solution for High Quantity Production of Stirling Coolers” in Cryocoolers 13, R. G. Ross Jr. ed., Proc. 13th International Cryocooler Conf., March 29, 2004 New Orleans, Louisiana, pp. 51-58, 2005.
[6] G. Tsuzuki, M. P. Hernandez, and B. A. Willemsen, “Tuning fork filter design for hand scribe tuning,” 2005 IEEE MTT-S Int. Microwave Symp. Dig., vol. 3, pp. 1471-1474, June 2005.
[7] L. S. J. Peng, and B. H. Moeckly, “RF properties of (RE)Ba2Cu3O7-δ (RE=Er, Ho, and Dy) superconducting thin films for wireless communications” IEEE Trans. Appl. Supercond., vol 15, pp. 3710-3713, June 2005.
[8] G. L. Matthaei, | B. A. Willemsen, | E. M. Prophet, | and G.
Tsuzuki, “Zig–Zag-Array Superconducting Resonators for Relatively High-Power Applications,” IEEE Trans. Microwav. Theory And Tech., vol 56, pp 901-912, April 2008.
[9] G. Tsuzuki, M. P. Hernandez, E. M. Prophet, S. Jimenez, and B.
A. Willemsen, “Ultra-Selective Constant-Bandwidth Electro-mechanically Tunable HTS Filters,” 2006 IEEE MTT-S Int. Symp. Dig., San Francisco, CA, pp 693-696, June 2006.
[10] E. M. Prophet, J. Musolf, B. F. Zuck, S. Jimenez, K. E. Kihlstrom, B. A. Willemsen, “Highly-selective electronically-tunable cryogenic filters using monolithic, discretely-switchable MEMS capacitor arrays,” IEEE Trans. Appl. Supercond., vol. 15, pp 956 – 959, June 2005.
[11] M. J. Scharen, D. R. Chase, A. M. Ho, A. O'Baid, K. F. Raihn,
R. J. Forse, “Filter subsystems for wireless communications,” IEEE Trans. Appl. Supercond., vol. 7, pp 3744-3749, Jun. 1997
[12] J. R. Sochor “Compressable tuning element for microwave resonators and method of making same”, US Patent 5,968,876 (1999).

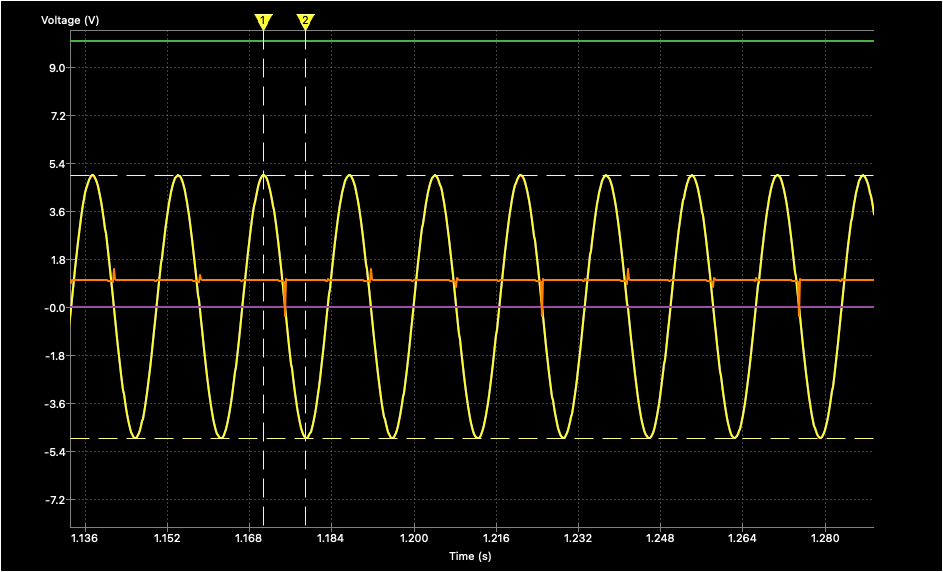
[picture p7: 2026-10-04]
hardware/kicad/sim/screenshots/input-v2.5-output-10vpp.png

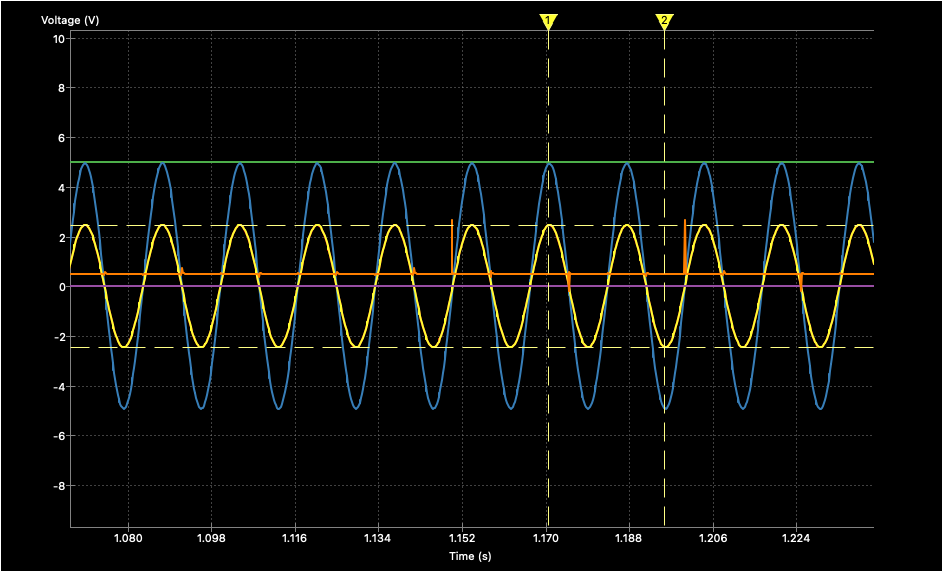
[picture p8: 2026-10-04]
hardware/kicad/sim/screenshots/input-v1.25-output-5vpp.png

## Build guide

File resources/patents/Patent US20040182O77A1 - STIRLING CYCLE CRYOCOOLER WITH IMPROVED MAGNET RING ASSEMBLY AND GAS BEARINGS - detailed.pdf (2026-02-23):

## (19) United States

US 20040182O77A1

# (12) Patent Application Publication (10) Pub. No.: US 2004/0182077 A1

O'Baid et al. | (43) Pub. Date: | Sep. 23, 2004
(54) STIRLING CYCLE CRYOCOOLER WITH
IMPROVED MAGNET RING ASSEMBLY

Publication Classification
AND GAS BEARINGS | (51) Int. Cl | F02G 1/04; FO1B 29/10;
F25B 9/00
(75) Inventors: Amr Hassan O'Baid, Goleta, CA (US); (52) U.S.C. ... 60/520; 62/6 Wallace Y. Kunimoto, Santa Barbara,
CA (US)
Correspondence Address: | (57) | ABSTRACT
O’MELVENY & MEYERS
S.'', Stry." | A piston assembly for use in a motor comprises a cylinder 9 | having a bore, an electrically conductive piston reciprocally
(73) Assignee: Superconductor Technologies, Inc., | disposed within the cylinder bore, a gas cavity formed
Santa Barbara, CA | within the piston, and one or more gas bearings associated
with the piston, each of the one or more gas bearings
(21) Appl. No.: | 10/767,110 | including an aperture formed within the piston and an
1-1. | electrically conductive tubular member extending through
(22) Filed: | Jan. 28, 2004 | the aperture, the tubular member having a lumen in com
Related U.S. Application Data | munication between the gas cavity and the cylinder bore.
The piston assembly may be used in connection with a motor
(63) Continuation of application No. 10/160,570, filed on | used in a cryocooler that is driven by oscillating magnetic
May 30, 2002, now Pat. No. 6,694,730. | energy fields.

UU
106 | 124 | 104 110 108 ( 136
2 | RN | NHSt s | s
Sces | ula-a-a-a-a-ayaaa.. | I | SS
2N. SGN | SS 240SE. Lizzi TSSEY:2's

## ESS SESS

220 2.36 | % | 3.24% is
N SNEHESF 214 | S. IEEEzzlz. 2N.I.T.ZN

## Patent Application Publication Sep. 23, 2004 Sheet 1 of 7 US 2004/0182077 A1

### Prior Art

38 | SNSE2 = -SNS) SN-Z, N 7 YSS, SS7, SS SSS | W

N

# Null 272

42

## NCKKZZZ Z7%

NYaNYa YaYa Ya NNNNNNNNNNNNNNNNNN NY 7.7%f KNNSZZiS,

36

Patent Application Publication Sep. 23, 2004 Sheet 2 of 7 | US 2004/0182077 A1
y Area | sees | a | SY essessess

16

FIG. 5 Yasa SYSease as S.

24 | 2O | 32 | 54
Prior Art

### Patent Application Publication Sep. 23, 2004 Sheet 3 of 7 US 2004/0182077 A1

### Patent Application Publication Sep. 23, 2004 Sheet 4 of 7 US 2004/0182077 A1

Ø atte

AAAAAY

Ø |8|Ž

# (~~ [[e?]?:~*~ç) Zº §fffffffff?Ž?ZZZZZZZZZZZZZZZZZZZZZZZZZZZZZZZZZZZZZ) >

Patent Application Publication Sep. 23, 2004 Sheet 6 of 7 | US 2004/0182077 A1
160 | 140 | 154 | 162
... v. . . . \, N | - N - | Y M. | , ' | ' | ' | ' | ',
FIG. | 1 1 | 7 | 142

164

170 | -166

### Patent Application Publication Sep. 23, 2004 Sheet 7 of 7 US 2004/0182077 A1

KKUNSTEEEEEEEEEEEEEEEEE========No.§ OESOESOEKK

190
FIG.

198
14

# FIG. 1 5

US 2004/0182077 A1

STIRLING CYCLE CRYOCOOLER WITH IMPROVED MAGNET RING ASSEMBLY AND GAS BEARINGS

RELATED APPLICATION
0001. This application is a continuation of U.S. applica tion Ser. No. 10/160,570, filed May 30, 2002, now allowed. The 570 application is incorporated by reference as if set forth fully herein.

FIELD OF THE INVENTION
0002 The field of the invention relates generally to cryocoolers, and more particularly to Stirling cycle cryo
coolers.

BACKGROUND OF THE INVENTION
0.003 Recently, substantial attention has been directed to the field of Superconductors and to Systems and methods for using Such products. Substantial attention also has been to directed to Systems and methods for providing a cold environment (e.g., 77 K or lower) within which Supercon ductor products Such as Superconducting filter Systems may

function.
0004 One device that has been widely used to produce a cold environment within which Superconductor devices may function is the Stirling cycle refrigeration unit or Stirling cycle cryocooler. Such devices typically comprise a dis

placer unit and a compressor unit, wherein the two units are in fluid communication and are driven by one or more linear or rotary motorS. Conventional displacer units generally have a “cold' end and a “hot” end, the warm end being in fluid communication with the compressor unit. Displacer units generally include a displacer having a regenerator mounted therein for displacing a fluid, Such as helium, from one end, i.e., the cold end of the displacer unit, to the other end, i.e., the warm end, of the displacer unit. A piston assembly of the motor functions to apply additional pressure to the fluid when the fluid is located Substantially within the warm end of the displacer unit, and to relieve pressure from the fluid when the fluid is located substantially within the cold end of the displacer unit. In typical cryocoolers, the piston and displacer units oscillate at 60 Hz. In this fashion, the cold end of the displacer unit may be maintained, for example, at 77 K, while the warm end of the displacer unit is maintained, for example, at 15 degrees above ambient temperature. Devices Such as Superconducting filters are then typically placed in thermal contact with the cold end of the displacer unit via a heat acceptor. Heat is transferred from the device to the heat acceptor. The heat transferred to the heat acceptor then passes to the helium gas contained in the displacer unit.
0005. A typical motor used in a cryocooler comprises a piston assembly on which there is mounted a magnet ring assembly that transforms an oscillating magnetic energy field generated by motor coils to reciprocating mechanical

energy that is applied to the piston assembly. For example, FIGS. 1 and 2 illustrate a prior art piston/magnet assembly 10, which includes a piston assembly 12 and a magnet ring assembly 14 mounted thereon. Referring Specifically to

FIGS. 3-6, the magnet ring assembly 14 includes eight magnets 16 that are cylindrically arranged to provide a radial magnetic field. To affix the magnets 16 in place, the magnet

### Sep. 23, 2004

ring assembly 14 comprises an upper magnet holder 18, which includes an annular receSS 20 that captures the topS 22 of the magnets 16, and a lower magnet holder 24, which includes an annular recess 26 that captures the bottoms 28 of the magnets 16. Preferably, the walls that straddle the annular recesses 20 and 26 are as thin as possible (e.g., 0.0050 inch), so that the thickness of the magnets 16 can be maximized. For purposes of Structural integrity, the magnets 16 are held in place by bonding the tops 22 and bottoms 30 of the magnets 16 within the respective annular recesses 20 and 26. The magnet ring assembly 14 further comprises eight ring rods 32, which are located between the respective eight magnets 16 and TIG welded through corresponding

holes 34 within the upper and lower magnet holders 18 and 24 to maintain the Structural integrity of the magnet ring assembly 14.

0006 Referring back to FIGS. 1 and 2, the piston assembly 12 comprises a cylinder 36 having a bore 38, a cylindrical piston 40 that axially moves within the bore 38 of the cylinder 36, a piston end cap 42 disposed mounted in the end of the piston 40, and a piston bracket 44 disposed on the opposite end of the piston 40. As best shown in FIGS. 1 and 4, the upper magnet holder 18 of the magnet ring assembly 14 comprises eight radially to circumferentially disposed mounting apertures 46, and the piston bracket 44

comprises eight corresponding circumferentially disposed mounting apertures 48, which are used to firmly bolt the magnet ring assembly 14 to the piston assembly 12, as illustrated in FIG. 1. So that the top surface of the upper magnet holder 18 is flush with the mounting Surface of the piston bracket 44, the piston bracket 44 further includes eight radially disposed apertures 50 between the mounting apertures 48 to accommodate the ends of the ring rods 32 (shown best in FIG. 3) protruding through the upper magnet
holder 18.
0007 Referring still to FIG. 2, the piston assembly 12 further comprises gas bearingS 52 that receive gas, e.g., helium, from a sealed cavity 54 within the piston 40. It should be noted that any Suitable of gas bearingS 52 can be used. In the illustrated embodiment, four circumferentially disposed pairs of gas bearings 52 (only two pairs shown) are used. A check valve 56 (best shown in FIG. 1) provides a unidirectional flow of gas from the front of the piston 40, through the Sealed cavity 54 and out through the gas bearingS 52. Preferably, the gas bearingS 52 comprise ori

fices that are on the order of a one or two mils (e.g., 1.5 mils), so that only a Small amount of gas escapes from the Sealed cavity 54 though the gas bearingS 52, thereby pre Serving the preSSure that has built up in the Sealed cavity 54 until the next stroke of the piston 40. Typically, only 2-5 percent of gas that is displaced by the piston 40 enters the sealed cavity 54 through the check valve 56.
0008 Because the smallest drill bit currently is around 2.9 mils with a maximum length of about 30 mils, the orifices of the gas bearingS 52 cannot be drilled. Instead, each of the gas bearings 52 includes an aperture 58 in which there is disposed a gas bearing restrictor in the form of a screw 60 that can be turned to adjust the rate of gas that flows through the gas bearing 52. That is, the length of the passage created by the threaded helix between the screw 60 and the aperture 58 can be decreased or increased by carefully rotating the screw 60 in and out of the aperture 58 until the correct flow rates are attained in all gas bearingS 52.

Alternatively, Sapphire/ruby or glass orifices (not shown) with very Small diameters can be used as the gas bearing restrictor to provide a consistent gas flow at the designed rate

without requiring adjustment. These orifices, however, can only be made So long, and as will be described in more detail below, have reliability problems. The piston assembly 12 further comprises centering ports 62 (shown in FIG. 1), which provide a return gas circuit from region adjacent the back of the piston 40 to the region adjacent the front of the piston 40.
0009 Due to the tight tolerances (typically, about 5 mils) between the magnet ring assembly 14 and adjacent lamina tions (only internal lamination 28 shown) that are disposed on both the inside and outside Surface of the magnet ring assembly 14, the circularity of the magnet ring assembly 14 must be perfect or near-perfect, So that it does not rub against the adjacent laminations. For the same reason, the concen tricity between the piston 40 and the magnet ring assembly 14 must be perfect or near-perfect. In addition, the magnets 16 must be in a perfect or near-perfect cylindrical equidistant arrangement, So that the generated magnetic field is radially uniform. In this manner, a uniform load will be provided to the gas bearingS 52, thereby maximizing the efficiency of the piston assembly 12. Thus, it can be appreciated that great care must be taken when assembling the magnet ring assem bly 14, resulting in often tedious and time consuming process that is magnified by the relatively large number of parts (eighteen-eight magnets, eight ring rods, two magnet holders) that make up the magnet ring assembly 14. Notably, magnet Segments cannot currently be made as a single fully cylindrical piece due to magnetic technology limitations.

Thus, multiple magnets must be painstakingly mounted within the upper and lower magnet holders 18 and 24. Also, the measures taken to ensure that the magnet ring assembly 14 and piston 40 are concentric along their lengths, namely, the drilling of the apertures 50 within the piston bracket 44

that accommodate the protruding ring rods 32, provide additional time-consuming Steps. Furthermore, because the walls adjacent the annular recesses 20 and 26 of the respec tive upper and lower magnet holders 18 and 24 are prefer ably very thin, So that the thickness of the magnets 16 can

be maximized, these walls are often inadvertently perfo rated, resulting in the Scrapping of the respective magnet

holder.
0010. In addition, all eight screws 60 within the apertures 58 of the gas bearings 52 have to be iteratively adjusted and the flow rate measured throughout the fabrication process of the cryocooler to ensure that the gas bearingS 52 exhibit the designed flow rate at the end of the final assembly process. Great care must be taken when rotating the screws 60 within the apertures 58, so that the heads of the screws 60 are not Stripped. Occasionally, however, this will occur, requiring that the expensive piston assembly 12 be Scrapped.

0.011 Reliability of the cryocooler is another concern. In the field of commercial Radio Frequency (RF) communica tions, it is desired that Stirling cycle cryocoolers provide maintenance free operation for tens of thousands of hours, and more preferably, at least forty thousand hours. After mere thousands of operational hours, however, cryocoolers that incorporated piston/magnet assemblies similar to the assembly 10 described above were failing. It was discovered that, when the piston 40 banged against the cylinder 36, the epoxy joints between the magnets 16 and the upper and lower magnet holders 18 and 24 would break and/or the magnet ring assembly 14 would go out of round, causing the magnet ring assembly 14 to rub against the adjacent lami nations and/or unequal loading of the gas bearingS 52. AS a result, the magnet ring assembly 14 would deteriorate rap idly. Thus, the high energy transmitted to the magnet ring assembly 14 due to the high frequency application of the

motor Stresses the importance of the attachment technique between magnet and the magnet holder. It was also discov ered that when Sapphire/ruby or glass orifices are alterna tively used as the gas restrictors, a Static charge would build up as the gas flows through them at 60 Hz. As a result, very fine particles would collect within the very small diameters (typically about 0.0012 inch in diameter) and eventually plug them.

0012. Thus, there is a need for an improved magnet ring assembly and gas bearing restrictor that can be used with piston assemblies, Such as those found in cryocoolers.
SUMMARY OF THE INVENTION
0013 The present inventions are directed to magnet ring assemblies and piston/magnet assemblies, motors, and cryo coolers that utilize Such magnet ring assemblies. In accor

dance with the present inventions, a magnet ring assembly comprises a cylindrical magnet holder having an inner Surface, and one or more magnets disposed around the inner Surface of the cylindrical magnet holder. In the preferred embodiment, a plurality of equidistantly Spaced magnets is disposed around the inner Surface of the cylindrical magnet holder. So that the magnets conform to the cylindrical magnet holder, each of the plurality of magnets is preferably

arcuate and comprises an outer radius of curvature Substan tially equal to the inner radius of the cylindrical magnet holder. The magnets can be captured by the magnet holder in a variety of directions.
0014 For example, the magnets can be rotationally cap tured by bonding them to the inner Surface of the magnet holder. The magnets can be radially captured by providing the plurality of magnets with a radially uniform magnet polarity, Such that they mutually magnetically repel each

other against the inner Surface of the cylindrical magnet holder. Also, each of the magnets can exhibit an outer arcuate length that is greater than the inner arcuate length, Such that any one of the magnets is captured by the edges of the adjacent magnets, and thus cannot be displaced radially inward. The magnets can be axially captured by forming an annular ledge on the inner Surface of the magnet holder and disposing one of the axial edges of each magnet on the annular ledge, and Swaging the axial edge of magnet holder around the other axial edge of each of the magnets. 0015. By way of non-limiting example, the afore-de Scribed magnet ring assembly provides various advantages. For example, the magnets can be mechanically captured to Sustain high frequency operation of the piston on which the magnet ring assembly is mounted. Also, assuming that the magnet holder is a unibody Structure, the number of parts (not including the magnet Sectors) can be reduced to one, and no TIG Welds are required. In addition, alignment of the magnet Sectors can be easily accomplished, Since the magnet SectorS Self-align to each other as they are inserted into the magnet holder. Also, Since the magnet Sectors are not asSociated with the outer Surface of the magnet holder, the outer Surface can be grinded, Such that it is concentric with
the inner Surface thereof.

0016. The present inventions are also directed to gas bearing restrictors, and piston assemblies, motors, and cryo coolers that utilize Such gas bearing restrictors. In accor dance with the present inventions, a piston assembly com prises a cylinder having a to bore, an electrically conductive piston reciprocally disposed within the cylinder bore, a gas cavity formed within the piston, and one or more gas bearings associated with the piston. Each of the gas bearings includes an aperture formed within the piston and an elec

trically conductive tubular member extending through the aperture. The tubular member includes a lumen in commu nication between the gas cavity and the cylinderbore. In the preferred embodiment, the tubular member is a composite tube composed of outer and inner tubes that are press-fit into the aperture.
0.017. By way of non-limiting example, the afore-de Scribed gas bearing provides various advantages. For example, because the tubular member is electrically con ductive, Static buildup is minimized, thereby minimizing the chances that the orifice will become plugged. In addition, if the tubular member is a composite tube formed of outer and inner tubular members, the wall of the composite tube can be made thick for ease of placement into the aperture, while forming an inner lumen that is relatively Small. Thus, no adjustment of the gas bearings are required, and at most, one flow measurement needs to be performed, since the size of the lumen will not change during the manufacturing process.

BRIEF DESCRIPTION OF THE DRAWINGS
0.018. The drawings illustrate the design and utility of preferred embodiments of the present invention, in which Similar elements are referred to by common reference numerals. In order to better appreciate how the above-recited and other advantages and objects of the present inventions are obtained, a more particular description of the present inventions briefly described above will be rendered by reference to specific embodiments thereof, which are illus trated in the accompanying drawings. Understanding that these drawings depict only typical embodiments of the invention and are not therefore to be considered limiting of its Scope, the invention will be described and explained with additional Specificity and detail through the use of the accompanying drawings in which:
0.019 FIG. 1 is a top view of a prior art piston/magnet assembly;

0020 FIG. 2 is a cross-sectional view of the piston/ magnet assembly of FIG. 1, taken along the line 2-2,

0021 FIG. 3 is a perspective view of a magnet ring assembly used in the piston/magnet assembly of FIG. 1;

0022 FIG. 4 is a top view of the magnet ring assembly of FIG. 3;
0023 FIG. 5 is a cross-sectional view of the magnet ring assembly of FIG. 4, taken along the line 4-4;

0024 FIG. 6 is a cross-sectional view of the magnet ring assembly of FIG. 4, taken along the line 5-5;

0.025 FIG. 7 is a cross-sectional view of a cryocooler constructed in accordance with one preferred embodiment of the present inventions,
0.026 FIG. 8 is a cross-sectional view of a novel piston/ magnet assembly used in the cryocooler of FIG. 7;

0027 FIG. 9 is another cross-sectional view of the pis ton/magnet assembly used in the cryocooler of FIG. 7;

0028 FIG. 10 is still another cross-sectional view of the piston/magnet assembly used in the cryocooler of FIG. 7;

0029 FIG. 11 is a close-up view of a novel gas bearing used in the piston/magnet assembly of FIG. 8;

0030 FIG. 12 is a plan view of a composite tube used in the gas bearing of FIG. 11;
0031 FIG. 13 is a perspective view of a novel magnet ring assembly used in the piston/magnet assembly of FIG.

8;
0032 FIG. 14 is a cross-sectional view of the magnet ring assembly of FIG. 13, taken along the line 13-13; and

0033 FIG. 15 is a cross-sectional view of the magnet ring assembly of FIG. 13, taken along the line 14-14.

DETAILED DESCRIPTION OF THE PREFERRED EMBODIMENTS
0034 FIG. 7 illustrates a Stirling cycle cryocooler 100 constructed in accordance with a preferred embodiment of the present inventions. AS shown, the Stirling cycle cryo cooler 100 includes a displacer unit 102 that is associated With a cold region Pop and a Warm region Por at its opposite ends, a compressor unit 104, which is in fluid communication with the displacer unit 102, and a heat exchanger unit 106 between the displacer unit 102 and the compressor unit 104. The cryocooler 100 also includes a passive counterbalancer 107, which cancels the movement of the moving internal components of the compressor unit 104, thereby minimizing vibration of the cryocooler 100. 0035. The compressor unit 104 comprises a pressure housing assembly 108, motor 110, spring assembly 112, and a compression chamber 114 that is coincident with the warm region Por. The housing assembly 118 comprises a front bracket 120, a rear bracket 122, and a cylindrical housing Section 124 mounted therebetween. The Spring assembly 112 comprises a Spring bracket 126, and a pair of axially

spaced flexure springs 128 and 130 mounted thereon, which as will be described in further detail below, provide the necessary displacement phase between the compression and displacement functions of the cryocooler 100. The motor 110 comprises a piston/magnet assembly 132 and a magnetic induction assembly 134, which magnetically communicate with each other to provide the reciprocating action required to compress the fluid, e.g., gaseous helium, within the compression chamber 114. The piston/magnet assembly 132 comprises a piston assembly 136 and an associated magnet ring assembly 138.

0036) Referring further to FIGS. 8-10, the piston assem bly 136 includes a cylinder 140 that is mounted to the front bracket 120 of the housing assembly 118 (shown in FIG. 7), a piston 142 slideably disposed within a bore 146 of the cylinder 140, and a piston mounting bracket 148 for mechanically coupling the piston 142 to the piston flexure Spring 128 of the Spring assembly 112, and for mechanically coupling the magnet ring assembly 138 to the piston 142. The piston 142, along with the magnet ring assembly 138, is thus adapted for reciprocating motion within the cylinder
140. The piston 142 comprises a bore 150 in which there is disposed a displacer lining 152, which as will be described in further detail, is associated with the displacer unit 102 and facilitates the fluid displacement function of the cryocooler. 0037 Referring specifically to FIG. 8, the piston assem bly 136 further comprises a plurality of gas bearings 154 (in the illustrated embodiment, four pairs of gas bearings) that are circumferentially disposed about and circumferentially formed around the piston 142 in an equidistant manner, a substantially sealed cavity 156 formed within the piston 142 for providing gas, e.g., helium, to the gas bearings 154, and a check valve 158 that provides a unidirectional fluid communication conduit from the warm region PHOT (i.e., the compression to chamber 114) to the sealed cavity 156 when the pressure of the gas within that region exceeds the pressure within the cavity 156 (i.e., exceeds the piston reservoir pressure). Thus, it can be appreciated that when the piston 142 moves towards the compression chamber 114, the gas from the compression chamber 114 is forced through the check valve 158, into the sealed cavity 156, and out through the gas bearings 154.

0038. With specific reference to FIG. 11, the detailed structure of one of the gas bearings 154 will now be described. The gas bearing 154 comprises a bearing Space 160 formed within the external Surface 162 of the piston 142, an aperture 164 transversely extending from the bear ing space 160 through the wall 164 of the piston 142 and into the sealed cavity 156, and a composite tube 166 that extends through the aperture 164. The composite tube 166 comprises a lumen 168 that is in communication between the bearing space 160 and the sealed cavity 156 to provide a flow of gas from the sealed cavity 156 into the cylinder 140.

0039) Preferably, the aperture 164 is formed by trans versely drilling a hole through wall 164 of the piston 142. In the illustrated embodiment, the hole has a diameter of approximately 0.020 inch and a length of 0.100 inch. The outer diameter and length of the composite tube 166 is approximately 0.020 inch and 0.100 inch, respectively, and the diameter of the lumen 168 is approximately 0.0012 inch. Thus, the relatively thick wall of the composite tube 166, which in the illustrated embodiment is approximately 0.0094 inch thick, allows the composite tube 166 to be easily preSS-fit into the aperture 164. Significantly, the composite

tube 166 is composed of an electrically conductive material, Such as, e.g., Stainless Steel. As a result, the composite tube 166 is electrically grounded through the electrically conduc tive piston 142, and thus, a “static charge” will not build up, thereby preventing or at least minimizing the collection of dust particles within the lumen 168. Also, because the diameter of the lumen 168 does not change during the manufacturing process of the cryocooler 100, and is consis tent throughout any given run of a tubing, flow measure ments for each gas bearing 154 need not be performed, or at the most performed only once, thus reducing cost.
0040. Referring to FIG. 12, the composite tube 166 can be advantageously composed of an outer tubular member 170 and an inner tubular member 172 to provide the proper wall thickness of the composite tube 166, while allowing for a very small diameter lumen 168. Specifically, to manufac ture the composite tube 166 with exemplary inner and outer diameters of 0.0012 inch and 0.020 inch, long lengths of Stainless Steel tubing, Similar to “hypodermic needle tub ing.” can be fabricated with an inner diameter of 0.0015 inch
and an outer diameter of 0.0070 inch to form the inner tubular member 172. Long lengths of Stainless Steel tubing
can be fabricated with an inner diameter of 0.0075 inch and an outer diameter of 0.0020 inch to form the outer tubular
member 170. The outer tubular member 170 is then Swaged over the inner tubular member 172 to form a long length of the thick wall composite tube 166, which will have an outer diameter of 0.020 inch, an inner diameter of approximately 0.0012 inch (reduced from 0.0015 inch due to the Swaging), and a wall thickness of 0.0094 inch. The length of the

composite tube 166 is then cut into 0.100 inch lengths, the ends of which can be chemically etched to provide multiple burr-free composite tubes 166. Alternatively, the length of the composite tube 166 can be cut using “wire electric discharge machining to provide for a multiplicity of burr free composite tubes 166. The lengths of the composite tubes 166 are selected to provide the exact flow rate through to the lumen 168 of the composite tube 166. The composite tubes 166 are then press-fit into the drilled apertures 164 within the piston 142. A suitable manufacturer for fabricat ing the composite tube 166 is Phillips & Johnston, Inc., located in Glen Ellyn, Ill.
0041) Referring specifically to FIGS. 9 and 10, the piston assembly 136 further comprises a pair of front centering port assemblies 174 (FIG. 9) and a pair of rear centering port assemblies 176 (FIG. 10) to provide a pres sure release conduit between the space 178 at the rear end of the compressor unit 104 and the compression chamber 114. Specifically, each front centering port assembly 174 includes double transverse ports 180 that communicate with the cylinder 140, and a lumen 182 that axially extends within the front 179 of the piston 142 and provides communication between the double ports 180 and the compression chamber
114. Each rear centering port assembly 176 includes double transverse ports 184 that communicate with the cylinder 140, and a lumen 186 that axially extends within the rear 181 of the piston 142 and provides communication between the double ports 182 and the rear space 178 in the compressor unit 104. The double ports 180 and 184 communicate with each other through an annular indentation (not shown) formed on the inner surface of the cylinder 140, so that the rear Space 178 momentarily communicates with the com pression chamber 114 as the piston reciprocally moves within the cylinder 140, thereby equalizing the pressure between the rear space 178 and the compression chamber
114. Notably, the axial displacement between each of the double ports 180 or 184 provide a self-compensating air flow over an operating range of the piston 142. That is, only one port from each of the double ports 180 and 184 provide air flow during low piston 142 strokes, while both ports from each of the double ports 180 and 184 provide air flow during high piston 142 Strokes. In this manner, the piston 142 is not axially biased towards the compression chamber 114 by pressure that may otherwise build up in the rear space 178 as gas flows from the gas bearings 154 into the rear Space
178.
0042. With specific reference to FIGS. 13-15, the magnet ring assembly 138 will now be described. The magnet ring assembly 138 comprises a unibody cylindrical magnet

holder 188 and a plurality of arcuate magnet sectors 190 mounted within the magnet holder 188. In the illustrated embodiment, eight magnet sectors 190 are used, but it should be understood, that any number of magnet Sectors 190 can be used to provide the proper magnetic interaction with the magnetic induction assembly 134. The eight magnet sectors 190 are circumferentially disposed about the inner surface 192 of the magnet holder 188 in a circular equidis tant pattern. Each of the magnet sectors 190 exhibits an outer radius of curvature r, and has an outer Surface 191 within an outer arcuate length l, and an inner Surface 192 with an arcuate length 1. So that the outer surfaces 191 of the magnet sectors 190 are flush within the inner surface 192 of the magnet holder 188, the outer radius of curvature r, for each of the magnet sectors 190 is equal to the inner radius r2 of the magnet holder 188.
0043. The magnet holder 188 is composed of a high resistivity material (270 microhm cm), Such as, e.g., stain leSS Steel or any non-magnetic material. In this manner, magnetic losses through the magnet holder 188 are mini mized. To further reduce the magnetic losses, the wall thickness of the magnet holder 188 Surrounding the magnet sectors 190 is reduced, e.g., to less than 0.012 inch, by machining the outer Surface 194 of the magnet holder 188. The inner surface 192 of the magnet holder 188 is machined to establish the true position to Outer diameter needed for alignment of the piston 142 with the cylinder 140.
0044) The eight magnet sectors 190 are affixed in place in three directions: the axial direction (Z-direction), rotational direction (e-direction), and the radial direction (r direction). In the axial direction, the magnet sectors 190 are axially captured from both ends to eliminate any chance of escape due to the alternating axial motion of the magnet ring assembly 138. Specifically, each of the magnet sectors 190

comprises opposing axial edges 196 and 198, one of which is axially affixed in the first direction by an annular ledge 200 formed around the inner Surface 192 of the magnet holder 188, and the other of which is axially affixed in the

Second direction by Swaging the axial edge 202 of magnet holder 188 inward. In addition to capturing the magnet sectors 190, the swaged axial edge 202 provides structural integrity to the magnet holder 188, So that the magnet ring assembly 138 maintains circularity. In the rotational direc tion, the magnet sectors 190 are bonded to the inner surface 192 of the magnet holder 188 using a suitable bonding material, Such as, e.g., epoxy, which exhibits good Shear Strength at high temperatures. In the radial direction, the arrangement of the magnet SectorS 190 have a uniform radial polarity. In the illustrated embodiment, the polarity of the magnet sectors 190 is oriented with the North Pole pointing outward and the South Pole pointing inward. Thus, the uniform radial polarity repels each magnet sector 190 from the other magnet sectors 190 towards the inner surface 192 of the magnet holder 188. In this manner, the outwardly radial magnetic force facilitates the Securing of the magnet sectors 190 to the magnet holder 188. In addition, because each of the magnet Sectors 190 has an outer arcuate length l, that is greater than an inner arcuate length li., an interfer ence fit is provided between adjacent magnet sectors 190, thereby preventing the magnet sectors 190 from being radially displaced from the adjacent magnet sectors 190.

004.5 Thus, it can be appreciated that the magnet sectors 190 are mechanically captured to Sustain high frequency operation of the piston 142. Other advantages are provided by the magnet ring assembly 138. For example, compared to

the prior art magnet ring assembly 138 illustrated in FIGS. 3-6, the number of parts (not including the magnet Sectors
190) is reduced from ten to one, and 16 TIG welds are eliminated, thereby also eliminating the need to drill aper tures within the piston mounting bracket 148 in order to accommodate ring rods. In addition, alignment of the mag net Sectors 190 is easily accomplished, since the magnet sectors 190 self-align to each other as they are inserted into the magnet holder 188. Also, since the magnet sectors 190 are not associated with the outer Surface 194 of the magnet holder 188, the outer surface 194 can be grinded, such that

it is concentric with the inner Surface 192 thereof.
0046 Referring back to FIG. 7, the magnetic induction assembly 134 comprises internal laminations 208 mounted to the outside of the cylinder 140, external laminations 210
that are mounted between the front and rear motor brackets
120 and 122 in close outward proximity to the magnet ring assembly 138 to form a gap (not shown), and a motor coil

212 that lies within the recesses formed within the external
laminations 210 and Surrounds the magnet ring assembly
138. The internal and external laminations 208 and 210 are
preferably composed of a ferrous material. Thus, it will be appreciated that as the electrical polarity of the coil 212 is alternately Switched back and forth, the resulting magnetic force that is applied to the magnet ring assembly 138 acroSS the gap changes. As a result, the magnet ring assembly 138 reciprocally moves within the gap, and the piston 142 accordingly reciprocally moves within the cylinder 140. 0047 The displacer unit 102 functions in a conventional manner and includes a displacer housing 214, a displacer cylinder assembly 216, a displacer rod 218, and a heat acceptor 220. The displacer cylinder assembly 216 com prises a displacer body 222 that is slideably mounted within the displacer housing 214, and a regenerator 224 mounted within the displacer body 222. The displacer body 222 rests against a displacer liner 226 affixed to an inner wall 228 of the displacer housing 214. The displacer rod 218 is slideably disposed within the displacer liner 152 mounted within the piston bore 150, and is coupled at one end 230 to a base section 231 of the displacer body 222 and coupled at the other end 232 to the displacer flexure spring 130. Thus, under appropriate conditions, it is possible for the displacer body 222 to oscillate within the displacer housing 214.

0048. The heat acceptor 220 includes a radial component 234 and an annular component 236. The radial component 234 is generally perpendicular to the long axis of the

displacer unit 102. The annular component 236 extends from the radial component 234 and extends axially beyond the edge of the displacer cylinder assembly 216, abutting against a distal end 238 of the displacer liner 226. The heat acceptor 220 is preferably brazed to the displacer housing 214 to provide a hermetically sealed environment. The heat acceptor 220 is preferably made from high purity copper or oxygen-free-high-conductivity (OFHC) copper. The dis placer cylinder assembly 216 includes a plurality of radial holes 240. The radial holes 240 permits additional flow of helium within the cold region Po, impinging directly on the heat acceptor 220. The radial holes 240 assist in decreas ing the convective resistance between the heat acceptor and the helium gas within the cryocooler 100. The structure and function of the heat acceptor 220 is discussed in further detail in U.S. Pat. No. 6,327,862 entitled “Stirling Cycle Cryocooler With Optimized Cold End Design,” which is hereby expressly incorporated herein by reference.
0049. The heat exchanger unit 106, which is located between the displacer unit 102 and the compressor unit 104, includes a heat exchanger block 242 and a flow diverter 244. The heat exchanger block 242 is mounted to the front bracket 120 of the compressor unit 104, and includes a plurality of internal heat eXchanger fins 244 and a plurality of external heat rejector fins 246. Thus, the heat eXchanger unit 106 is designed to facilitate heat dissipation from a gas, Such as helium, that is compressed in the warm region Por located at the juncture between the displacer unit 102 and the compressor unit 104 (the region Por also is referred to herein as the compression chamber 114). Preferably, the heat eXchanger block 242, internal heat eXchanger fins 244 and external heat rejector fins 246 are made from a thermally conductive metal Such as high purity copper.

0050. During operation, the piston 142 and displacer cylinder assembly 216 preferably oscillate at a resonant frequency of approximately 60 Hz, and in Such a manner that the oscillation of the displacer cylinder assembly 216 is approximately 90 out of phase with the oscillation of the piston 142. Stated somewhat differently, it is preferred that the motion of the displacer cylinder assembly 216 will “lead” the motion of the piston 142 by approximately 90. 0051. Those skilled in the art will appreciate that, when the displacer cylinder assembly 216 moves to the cold region Po, most of the fluid, e.g. helium, Within the system moves around the flow diverter 244 and through the internal heat eXchanger fins 244 into the warm region P. Due to the phase difference between the motion of the displacer cylinder assembly 216 and the piston 142, the piston 142 should be at mid-Stroke and moving in a direction toward the heat acceptor 220 when the end of the displacer cylinder assembly 216 is located near the heat acceptor 220. This causes the helium in the warm region Por, i.e., the compression chamber 114, to be compressed, thus raising the temperature of the helium. The heat of compression is transferred from the compressed helium to the internal heat eXchanger fins 244 and from there to the heat eXchanger block 242 and external heat rejector fins 246. From the heat rejector fins 246, the heat is transferred to ambient air. As the displacer cylinder assembly 216 moves to the warm region Por, the helium is displaced to the cold region P. AS the helium passes through the displacer body 222, it deposits heat within the regenerator 224, and exits into the cold region P at approximately 77 K. At this time, the compressor piston 142 preferably is at mid-Stroke and moving in the direction of the Spring assembly 112. This causes the helium in the cold region PCOLD to expand further reducing the temperature of the helium and allowing the helium to absorb heat. In this fashion, the cold region
P. functions as a refrigeration unit and may act as a “cold" SOCC.

0.052 Although particular embodiments of the present inventions have been shown and described, it will be under stood that it is not intended to limit the present inventions to the preferred embodiments, and it will be obvious to those skilled in the art that various changes and modifications may be made without departing from the Spirit and Scope of the present inventions. Thus, the present inventions are intended to cover alternatives, modifications, and equivalents, which may be included within the Spirit and Scope of the present inventions as defined by the claims.

What is claimed is:
1. A piston assembly for use in a motor, comprising:
a cylinder having a bore;
an electrically conductive piston reciprocally disposed within the cylinder bore;

a gas cavity formed within the piston; and
one or more gas bearings associated with the piston, each of the one or more gas bearings including an aperture formed within the piston and an electrically conductive tubular member extending through the aperture, the tubular member having a lumen in communication between the gas cavity and the cylinder bore.
2. The piston assembly of claim 1, wherein the lumen has an inner diameter equal to or less than 0.0020 inch.
3. The piston assembly of claim 1, wherein the lumen has an inner diameter equal to or less than 0.0015 inch.
4. The piston assembly of claim 1, wherein the tubular member has a diameter equal to or less than 0.0200 inch.
5. The piston assembly of claim 1, wherein the tubular member has a length between 0.100 inch and 0.200 inch.
6. The piston assembly of claim 1, wherein the tubular member is press fit into the aperture. 7. The piston assembly of claim 1, wherein the tubular member is a composite tube composed of an inner tubular
member and an outer tubular member.
8. The piston assembly of claim 1, wherein the one or more gas bearings comprises a plurality of gas bearings. 9. The piston assembly of claim 8, wherein the plurality of gas bearings are equidistantly disposed around a circum

ference of the piston. 10. The piston assembly of claim 1, further comprising a

unidirectional check Valve in communication between the
exterior of the piston and the gas cavity. 11. The piston assembly of claim 1, wherein each of the one or more gas bearings further comprises a bearing Space formed within the piston, wherein the lumen is in commu nication with the cylinder bore via the bearing Space. 12. A piston assembly for use in a motor, comprising:

a cylinder having a bore;
an electrically conductive piston reciprocally disposed within the cylinder bore;

a gas cavity formed within the piston; and
one or more gas bearings associated with the piston, each of the one or more gas bearings including an aperture formed within the piston and an electrically conductive composite tube extending through the aperture, the composite tube comprising an Outer tubular member and an inner tubular member, the inner tubular member having a lumen in communication between the gas cavity and the cylinder bore.
13. The piston assembly of claim 12, wherein the lumen has an inner diameter equal to or less than 0.0020 inch.
14. The piston assembly of claim 12, wherein the lumen has an inner diameter equal to or less than 0.0015 inch.
15. The piston assembly of claim 12, wherein the inner
tubular member has an outer diameter less than 0.010 inch.
16. The piston assembly of claim 12, wherein the inner tubular member has an Outer diameter equal to or less than
0.007 inch.
17. The piston assembly of claim 12, wherein the com posite tube has a diameter equal to or less than 0.0200 inch.
18. The piston assembly of claim 12, wherein the com posite tube has a length between 0.100 inch and 0.200 inch.
19. The piston assembly of claim 12, wherein the com posite tube is press fit into the aperture.

20. The piston assembly of claim 12, wherein the outer tubular member is Swaged onto the inner tubular member.
21. The piston assembly of claim 12, wherein the one or more gas bearings comprises a plurality of gas bearings.
22. The piston assembly of claim 21, wherein the plurality of gas bearings are equidistantly disposed around a circum ference of the piston. 23. The piston assembly of claim 12, further comprising

a unidirectional check Valve in communication between the
exterior of the piston and the gas cavity. 24. The piston assembly of claim 12, wherein each of the one or more gas bearings further comprises a bearing Space formed within the piston, wherein the lumen is in commu nication with the cylinder bore via the bearing Space. 25. A cryocooler, comprising:

a compressor unit, including
a piston assembly including a cylinder having a bore, an electrically conductive piston reciprocally disposed within the cylinderbore, a gas cavity formed within the piston, and one or more gas bearings associated with the piston, each of the one or more gas bearings including an aperture formed within the piston and an electrically conductive composite tube extending through the aperture, the composite tube comprising an

outer tubular member and an inner tubular member, the inner tubular member having a lumen in communica tion between the gas cavity and the cylinder bore.
a magnet ring assembly including a cylindrical magnet holder having an inner Surface, and a plurality of magnets disposed around the inner Surface of the cylindrical magnet holder, the magnet ring assembly being mounted to the piston bracket; and

one or more electrical coils that Surround an outer Surface
of the cylindrical magnet holder of the magnet ring assembly;

a displacer unit in fluid communication with the com preSSor unit; and
a heat eXchange unit between the compressor unit and displacer unit.
26. The cryocooler of claim 25, wherein the lumen has an inner diameter equal to or less than 0.0020 inch.
27. The cryocooler of claim 25, wherein the lumen has an inner diameter equal to or less than 0.0015 inch.
28. The cryocooler of claim 25, wherein the inner tubular
member has an outer diameter less than 0.010 inch.
29. The cryocooler of claim 25, wherein the inner tubular member has an outer diameter equal to or less than 0.007
inch.
30. The cryocooler of claim 25, wherein the composite tube has a diameter equal to or less than 0.0200 inch.
31. The cryocooler of claim 25, wherein the composite tube has a length between 0.100 inch and 0.200 inch.
32. The cryocooler of claim 25, wherein the composite tube is preSS fit into the aperture. 33. The cryocooler of claim 25, wherein the outer tubular

member is Swaged onto the inner tubular member.
34. The cryocooler of claim 25, wherein the one or more gas bearings comprises a plurality of gas bearings.
35. The cryocooler of claim 34, wherein the plurality of gas bearings are equidistantly disposed around a circumfer ence of the piston. 36. The cryocooler of claim 25, further comprising a

unidirectional check Valve in communication between the
exterior of the piston and the gas cavity.
37. The cryocooler of claim 25, wherein each of the one or more gas bearings further comprises a bearing Space formed within the piston, wherein the lumen is in commu nication with the cylinder bore via the bearing Space. 38. A motor, comprising:

a piston assembly including a cylinder having a bore, an electrically conductive piston that is reciprocally dis posed within the cylinder bore, and a piston bracket disposed on the end of the piston;
a gas cavity formed within the piston;
one or more gas bearings associated with the piston, each of the one or more gas bearings including an aperture formed within the piston and an electrically conductive tubular member extending through the aperture, the tubular member having a lumen in communication between the gas cavity and the cylinder bore;
a magnet ring assembly including a cylindrical magnet holder having an inner Surface and an annular ledge formed around the inner Surface, and a plurality of magnets disposed around the inner Surface of the cylindrical magnet holder, each of the plurality of magnets comprising opposing axial edges, one of the axial edges being disposed on the annular ledge, the magnet ring assembly being mounted to the piston bracket; and
a magnetic induction assembly operably coupled to the magnet ring assembly.
39. The motor of claim 38, wherein the magnets are equidistantly spaced from each other.
40. The motor of claim 38, wherein each of the plurality of magnetS is arcuate.
41. The motor of claim 40, wherein the cylindrical magnet holder has an inner radius, and each of the plurality of magnets comprises an outer radius of curvature Substantially equal to the inner radius of the cylindrical magnet holder.
42. The motor of claim 40, wherein each of the plurality of magnets exhibits an Outer arcuate length and an inner arcuate length, the inner arcuate length being less than the outer arcuate length. 43. The motor of claim 38, wherein the plurality of magnets has a radially uniform magnetic polarity.
44. The motor of claim 38, wherein the plurality of magnets is bonded to the inner Surface of the cylindrical magnet holder.
45. The motor of claim 38, wherein the cylindrical magnet holder comprises a Swaged axial edge opposite the annular ledge, and the other of the axial edges of each of the plurality of magnets is captured by the Swaged axial edge of the cylindrical magnet holder.
46. The motor of claim 38, wherein the cylindrical magnet holder is composed of a non-magnetic material.
47. The motor of claim 38, wherein the cylindrical magnet holder is a unibody Structure.
48. The motor of claim 38, wherein the magnetic induc tion assembly comprises:

one or more coils Surrounding the piston assembly; one or more internal laminations adjacent inner Surfaces of the plurality of magnets, and
one or more external laminations Surrounding the one or more coils and being adjacent to the outer Surface of the cylindrical magnet holder of the magnet ring assembly.
k | k | k | k | k

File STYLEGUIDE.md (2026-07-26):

# Style Guide

Coding conventions for this repository. The C++ firmware and the TypeScript
dashboard each have their own idioms; match the surrounding code, and prefer an
existing pattern over inventing a new one.

---

## C++ firmware

### Module pattern (the core convention)

Every subsystem is a **namespace of free functions** plus a thin CRTP adapter
that the compiler uses to enforce the lifecycle contract. See
[`include/module.h`](include/module.h) and [`docs/modules.md`](docs/modules.md).

```cpp
namespace mymodule {

module::InitStatus    init();      // called once from setup(); must not block
module::ServiceStatus service();   // called every loop() tick; must not block

struct Module : ModuleBase<Module> {
    static module::InitStatus    init()    { return mymodule::init(); }
    static module::ServiceStatus service() { return mymodule::service(); }
};
ASSERT_MODULE_INTERFACE(Module);

} // namespace mymodule
```

- Register the module in the appropriate `ModuleEntry` array in
  [`src/main.cpp`](src/main.cpp) — array order encodes init/service dependencies.
- Guard `Module` structs that call `millis()` (or other Arduino APIs) with
  `#ifdef ARDUINO` so the `native` host-test build still compiles.
- `init()` returns an `InitStatus` (`MODULE_INIT_SUCCESS`,
  `MODULE_INIT_HARDWARE_ERROR`, …). `service()` returns a `ServiceStatus`
  (`MODULE_SERVICE_OK`, `MODULE_SERVICE_SKIPPED`, `MODULE_SERVICE_ERROR`).
  Return the honest status — callers log health transitions from it.

### The no-blocking rule

**Blocking code is only allowed in `setup()` / module `init()`.** Nothing in
`loop()` or any `service()` may block (no `delay()`, no busy-waits, no blocking
I/O). Time-gate periodic work against `tick::nowMs()` and return
`MODULE_SERVICE_SKIPPED` when there is nothing to do this tick.

### Timing

Call `tick::update()` at the top of `loop()`, then read `tick::nowMs()` /
`tick::deltaMs()` everywhere else — do not sprinkle `millis()` calls that drift
within a tick.

### Naming

- Descriptive names; **no single-letter or ambiguous variable names.**
- `UpperCamelCase` for types/structs/enums; `lowerCamelCase` for functions and
  variables; `CONSTANT_CASE` for compile-time constants and macros.
- Namespaces are lower_snake or lowercase matching the subsystem (`cold_head`,
  `imu`). Proto message `ColdHead` maps to telemetry prefix `cold_head`.

### Control flow

Prefer early returns / guard clauses over deep nesting. Keep the happy path at
the base indentation.

### Comments — Doxygen

The firmware is Doxygen-documented. Match the existing house style:

- **File header** on every hand-written `.h`/`.cpp`:
  ```cpp
  /**
   * @file mymodule.h
   * @brief One-line summary of what this unit owns.
   *
   * Longer prose if useful.
   */
  ```
- **Every public/exported function** gets a `/** */` block with a description,
  `@param` for each parameter, and `@return` where it returns a value. Terse
  one-line `/** ... */` is fine for obvious members. `///` single-line docs are
  also accepted (both are used in the codebase).
- Use `@code ... @endcode` for examples and the
  `// ─── Section ───` banner comments to group related declarations.
- Keep implementation comments short (`//`), explaining *why*, not narrating.
- **Never edit generated files** (`web_content.h`, `*.pb.*`, `*/generated/*`).

Regenerate docs with `doxygen Doxyfile` (see [`AGENTS.md`](AGENTS.md)).

---

## TypeScript dashboard (`dashboard/`)

Preact + MUI + Vite. Existing conventions to match:

- **TSDoc** file headers (`/** @file ... @brief ... */`) and one-line `/** */`
  docs on exported symbols and notable members.
- `// ─── Section ───` banner comments to group config / helpers / hooks.
- Components are function components; hooks live in `src/hooks/`, shared types in
  `src/types/`, pure helpers in `src/utils/`.
- `proto/telemetry.proto` drives the generated decoder — remember protobufjs
  converts snake_case proto fields to camelCase on the JS side.

For broader TypeScript style (naming, `type` vs `interface`, no `any`, etc.),
this project follows the standard Google TypeScript conventions where the
dashboard grows.

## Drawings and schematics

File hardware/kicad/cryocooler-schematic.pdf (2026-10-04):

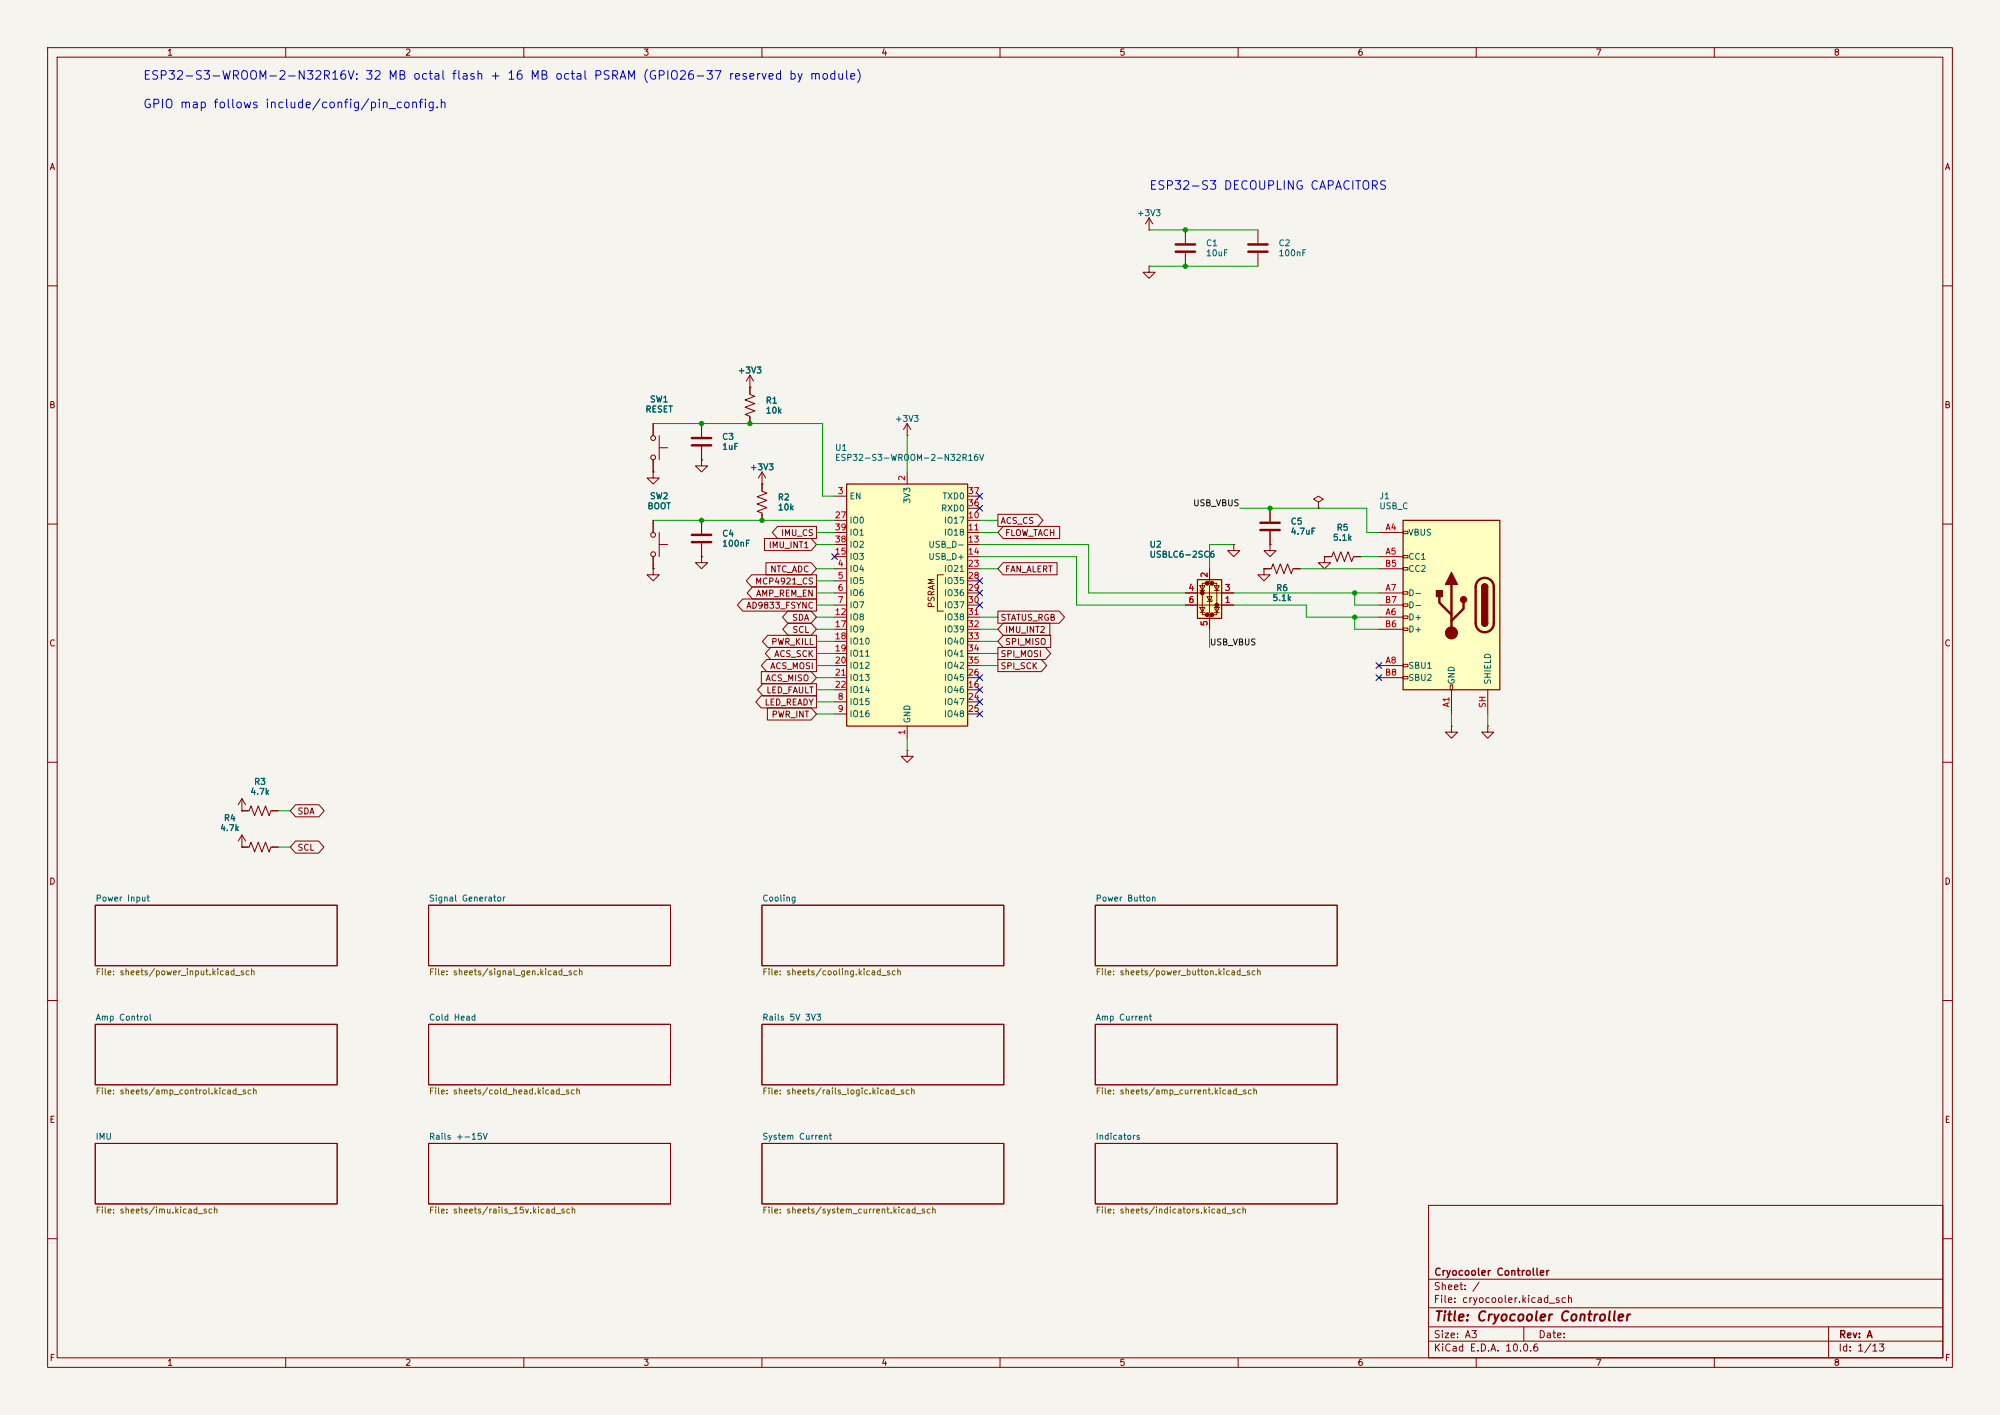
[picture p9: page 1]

ESP32-S3-WROOM-2-N32R16V: 32 MB octal flash + 16 MB octal PSRAM (GPIO26-37 reserved by module)

GPIO map follows include/config/pin_config.h

File: sheets/imu.kicad_sch Power Input File: sheets/power_input.kicad_sch

Signal Generator File: sheets/signal_gen.kicad_sch Cold Head

Amp Current File: sheets/amp_current.kicad_sch Power Button

File: sheets/cooling.kicad_sch Rails 5V 3V3

Amp Control File: sheets/amp_control.kicad_sch

System Current File: sheets/system_current.kicad_sch

Indicators File: sheets/indicators.kicad_sch

Size: A3 | Rev: A | F Date:
KiCad E.D.A. 10.0.6 | Id: 1/13

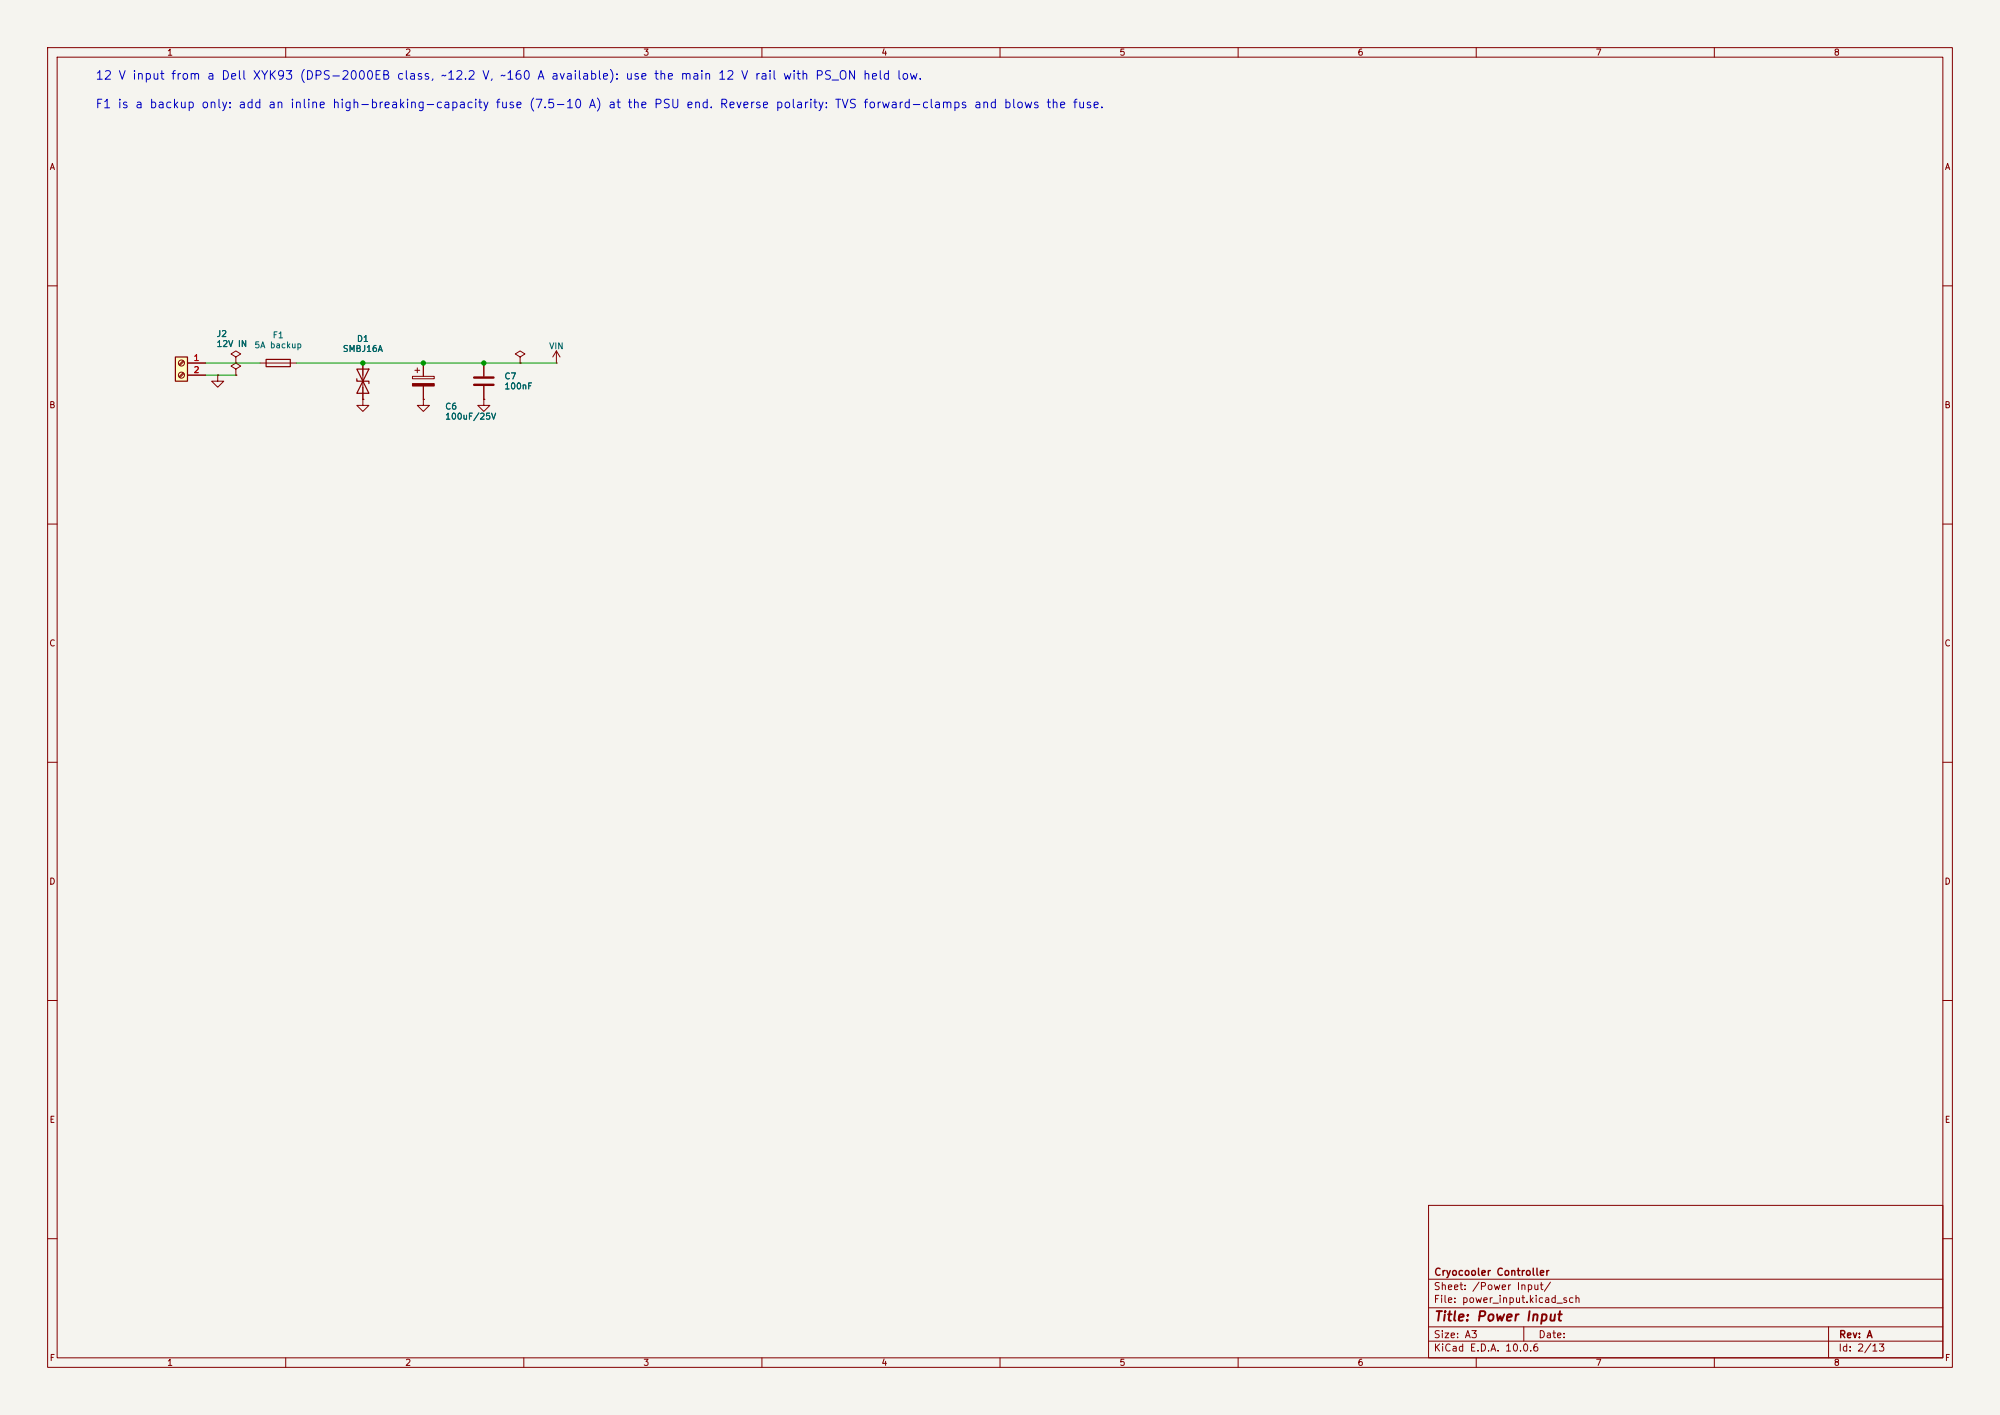
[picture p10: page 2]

12 V input from a Dell XYK93 (DPS-2000EB class, ~12.2 V, ~160 A available): use the main 12 V rail with PS_ON held low. D1

100nF F1 is a backup only: add an inline high-breaking-capacity fuse (7.5-10 A) at the PSU end. Reverse polarity: TVS forward-clamps and blows the fuse.

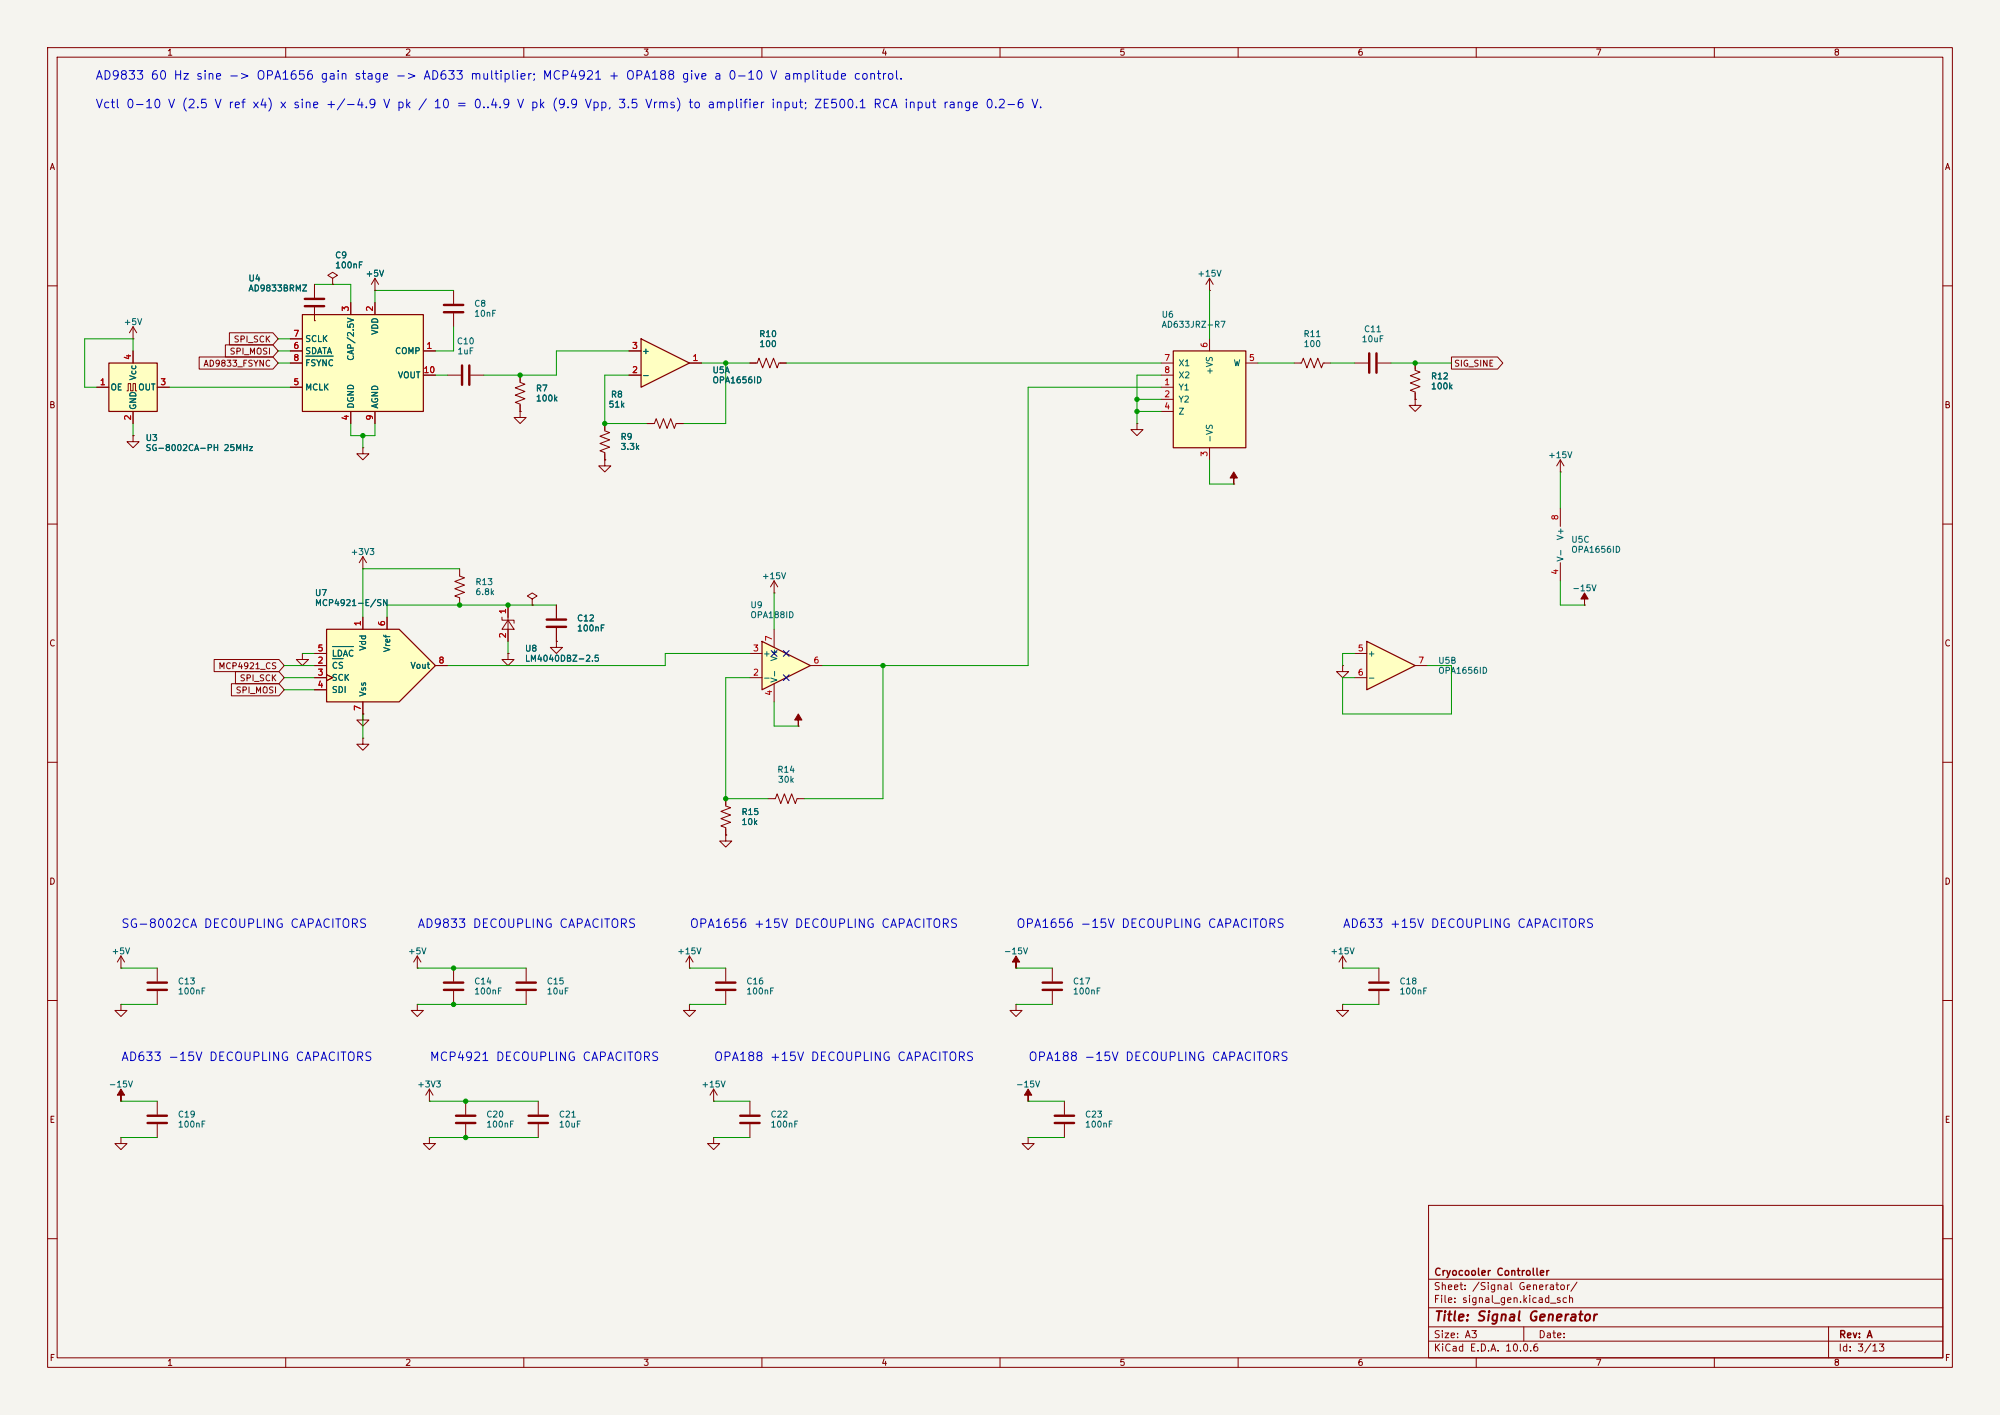
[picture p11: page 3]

AD9833 60 Hz sine -> OPA1656 gain stage -> AD633 multiplier; MCP4921 + OPA188 give a 0-10 V amplitude control.

Vctl 0-10 V (2.5 V ref x4) x sine +/-4.9 V pk / 10 = 0..4.9 V pk (9.9 Vpp, 3.5 Vrms) to amplifier input; ZE500.1 RCA input range 0.2-6 V. C9

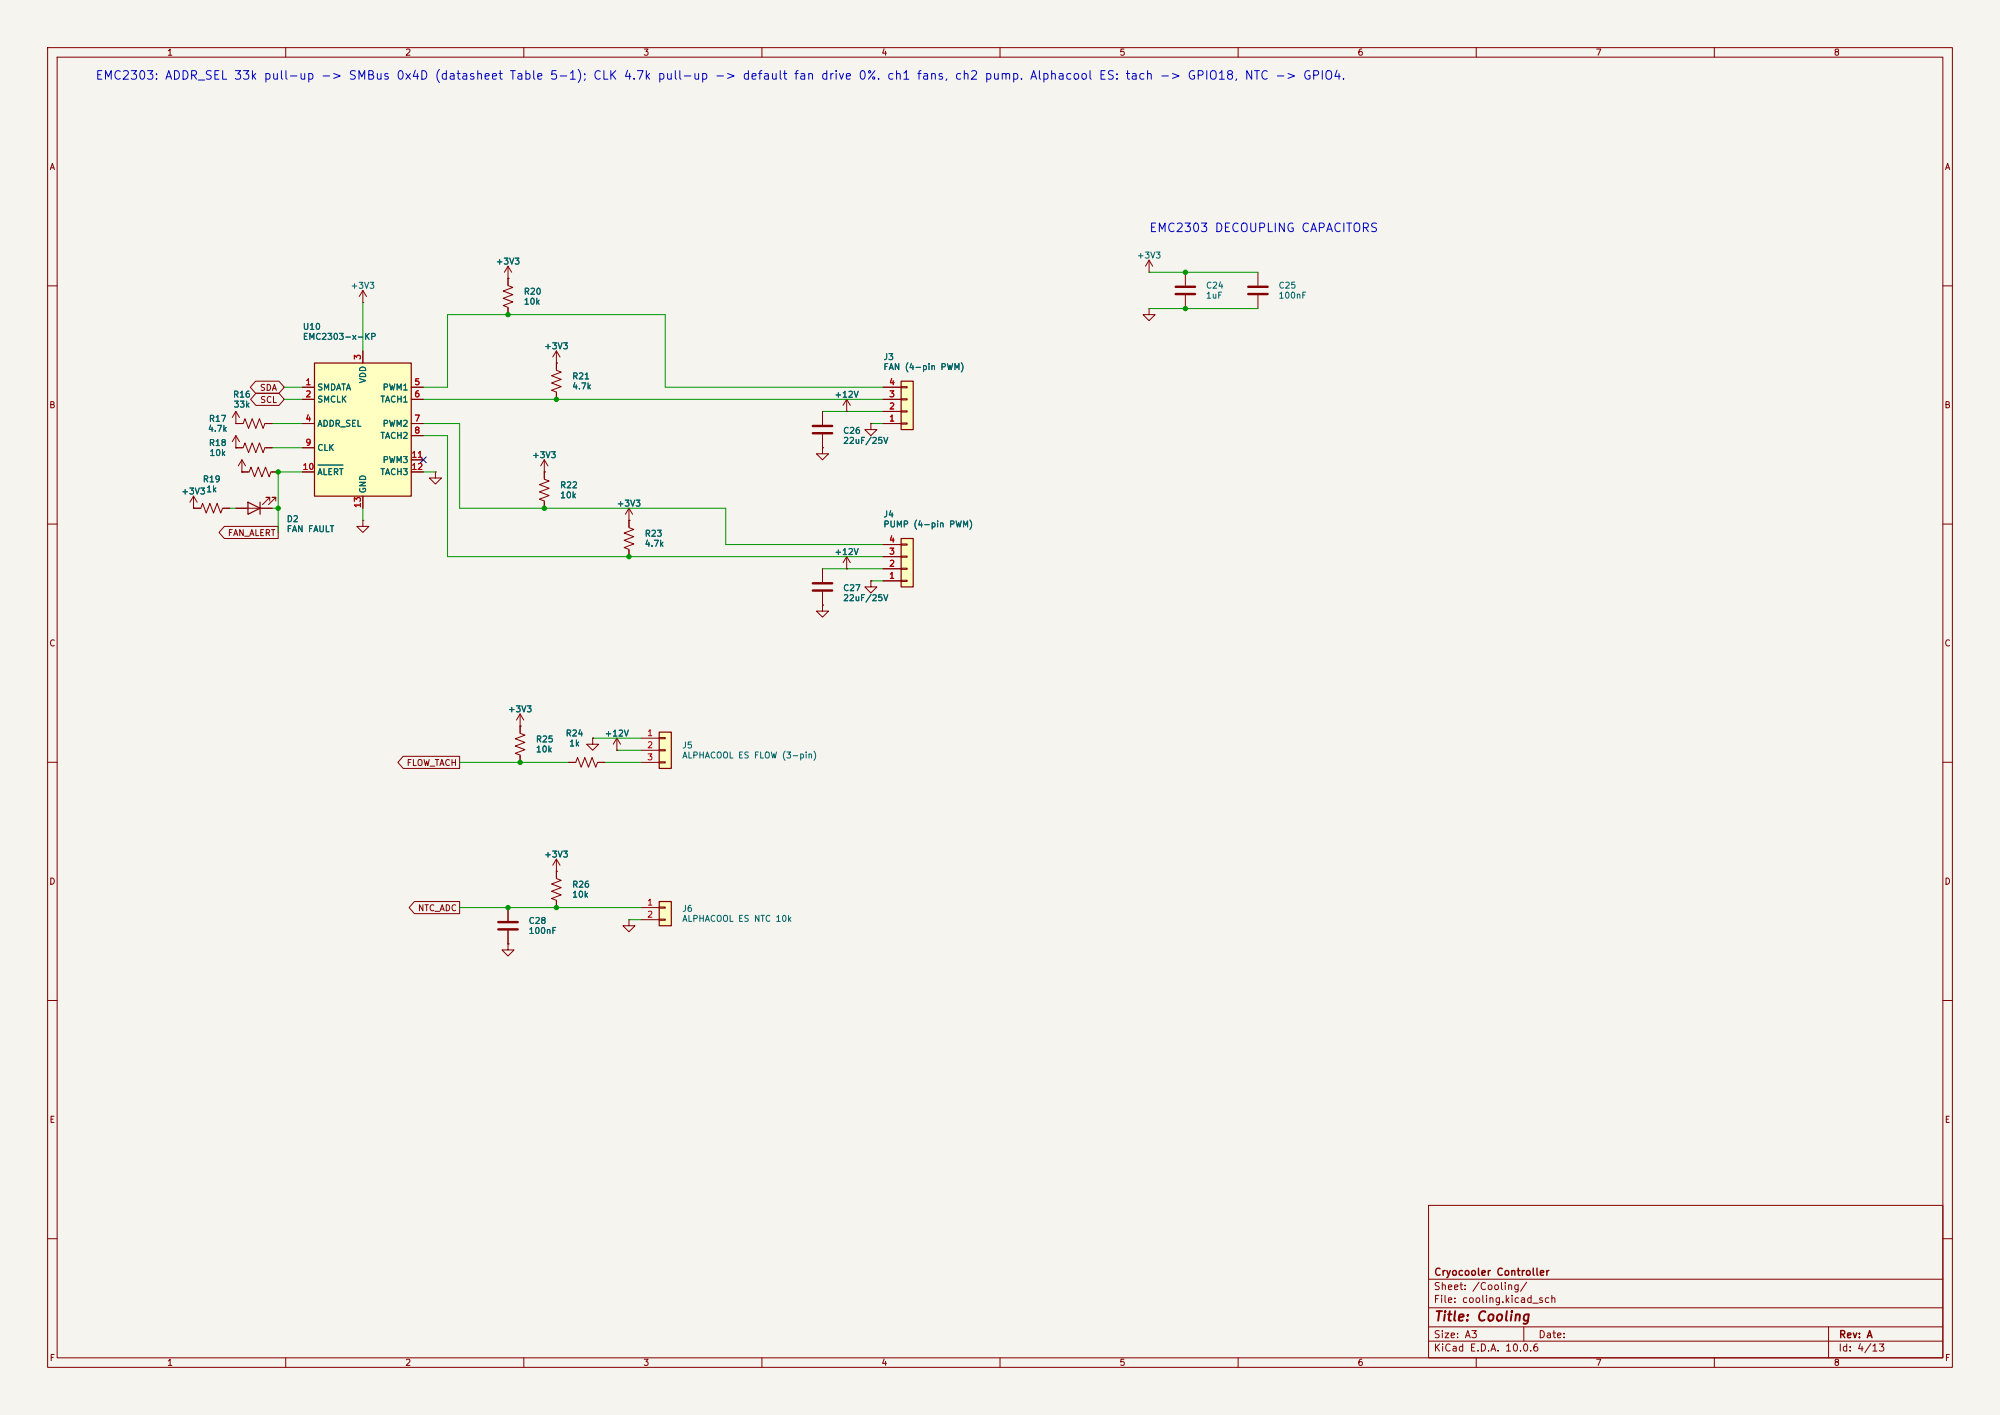
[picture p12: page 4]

EMC2303: ADDR_SEL 33k pull-up -> SMBus 0x4D (datasheet Table 5-1); CLK 4.7k pull-up -> default fan drive 0%. ch1 fans, ch2 pump. Alphacool ES: tach -> GPIO18, NTC -> GPIO4. D2

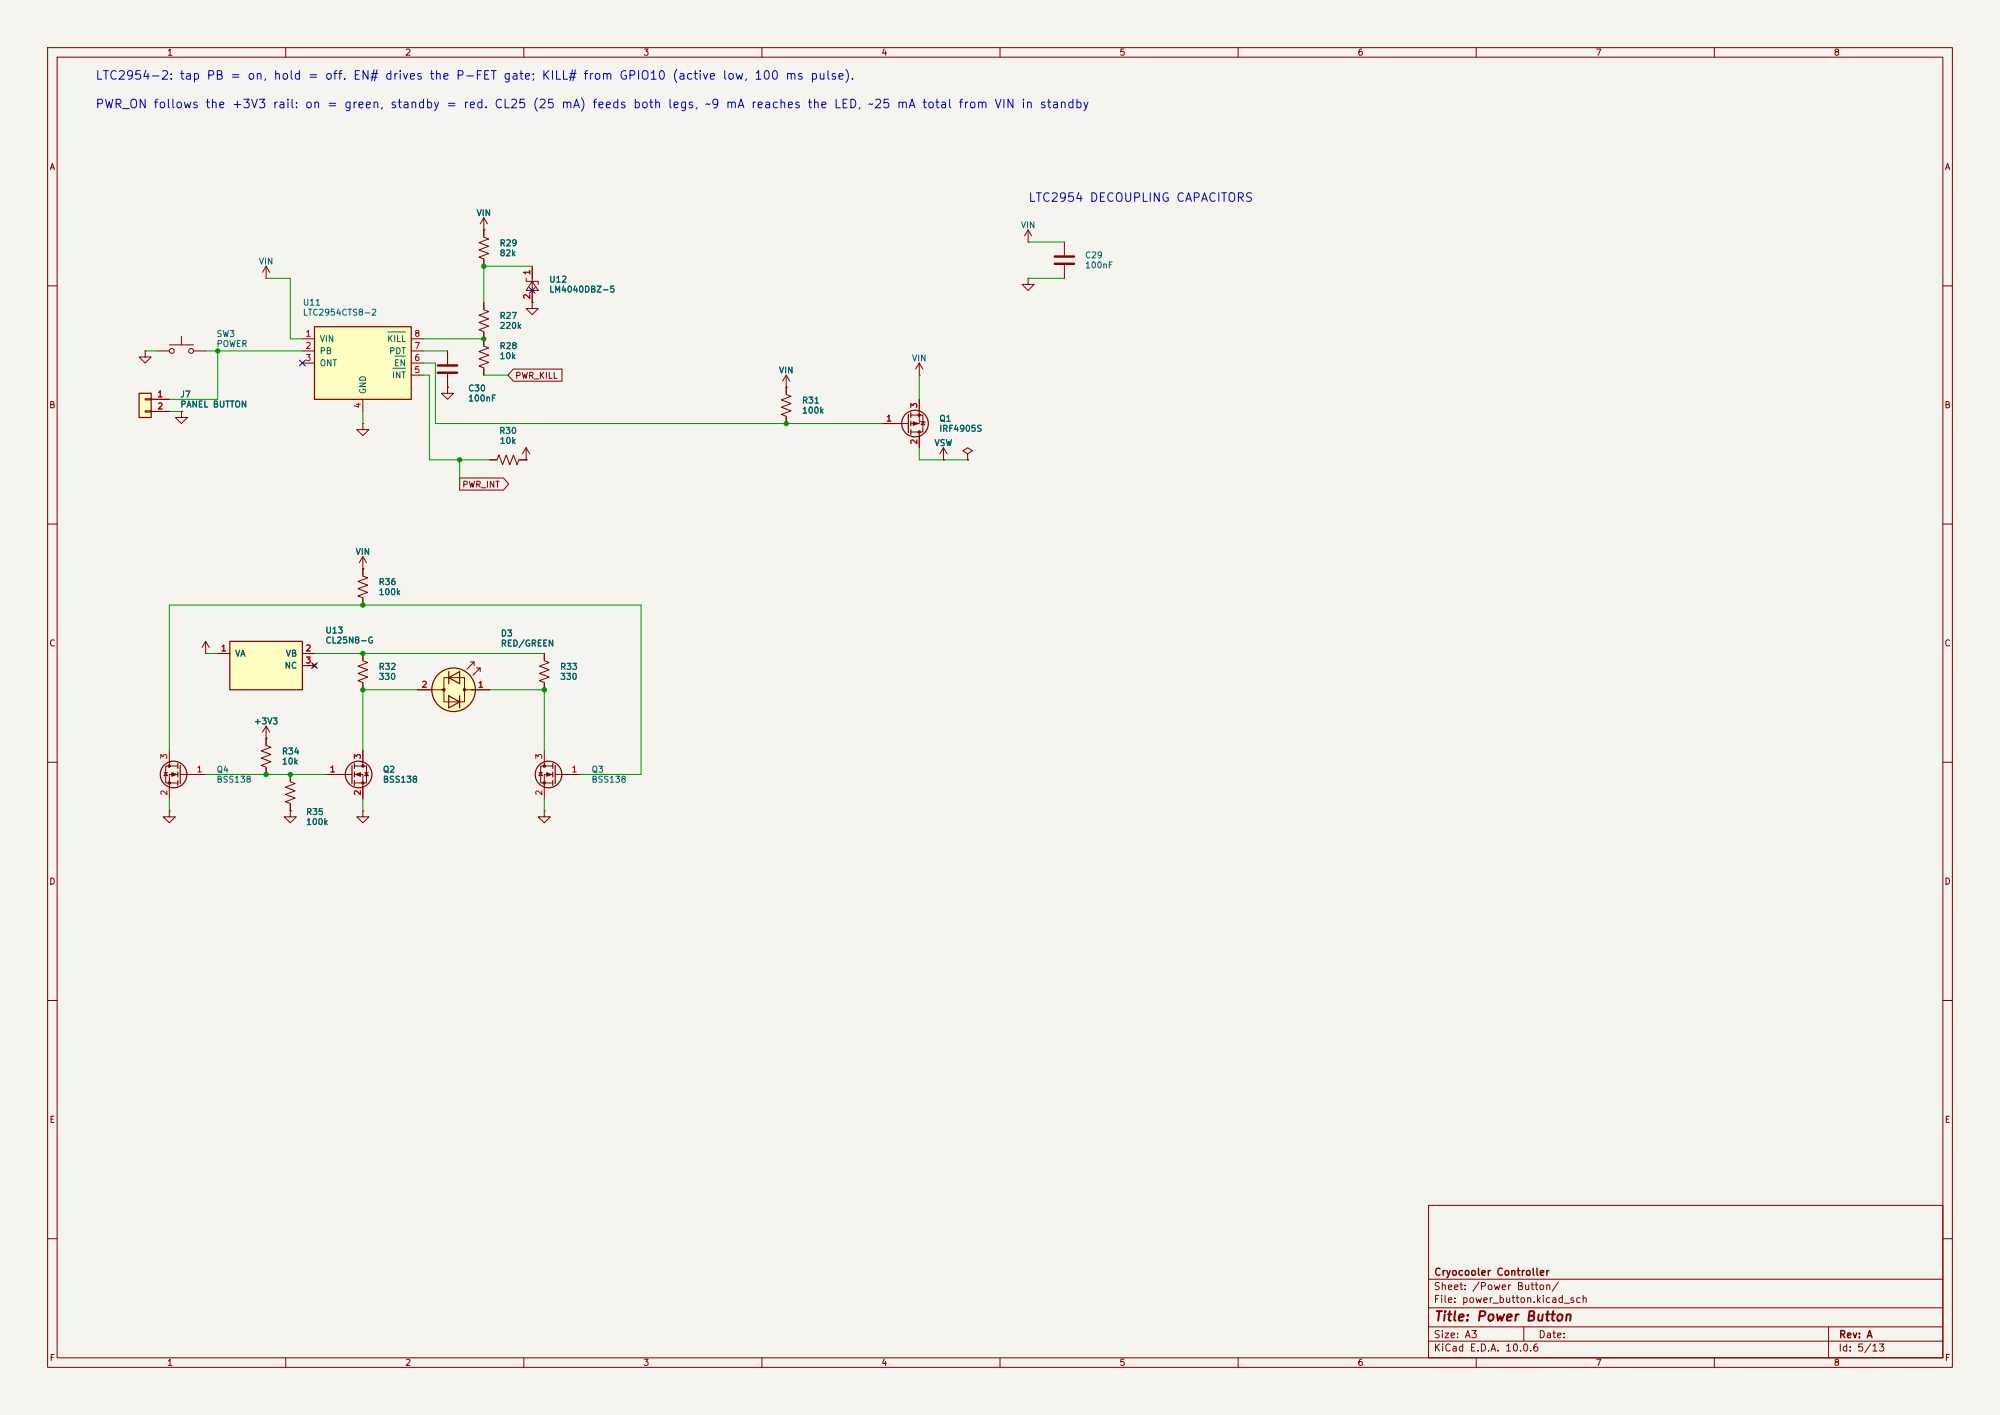
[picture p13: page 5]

330 PWR_KILL PWR_INT LTC2954-2: tap PB = on, hold = off. EN# drives the P-FET gate; KILL# from GPIO10 (active low, 100 ms pulse).

PWR_ON follows the +3V3 rail: on = green, standby = red. CL25 (25 mA) feeds both legs, ~9 mA reaches the LED, ~25 mA total from VIN in standby

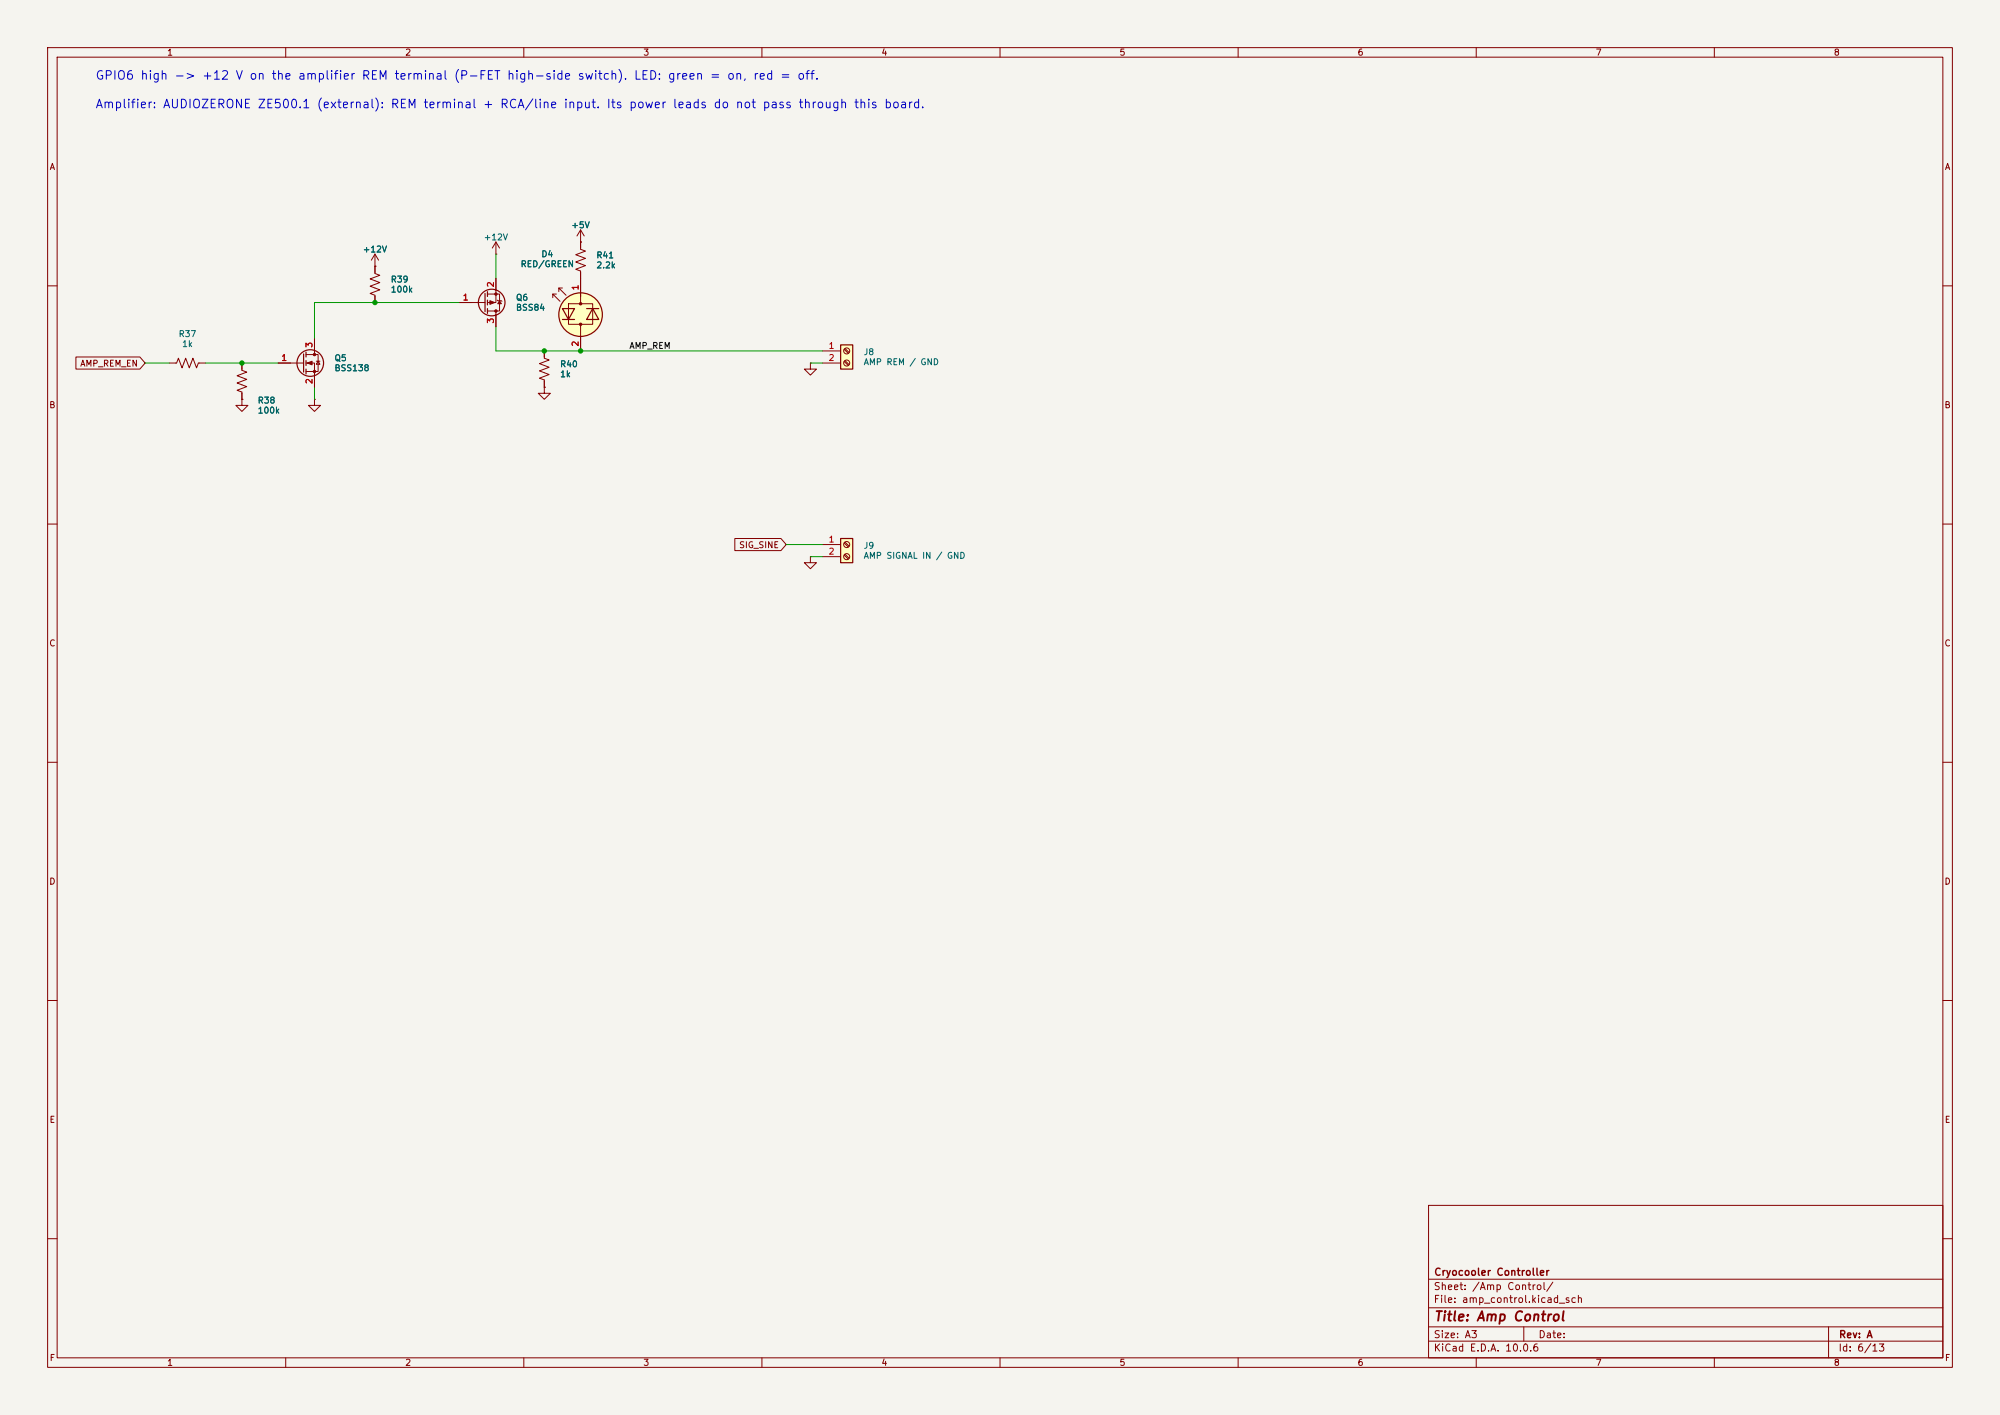
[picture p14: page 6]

GPIO6 high -> +12 V on the amplifier REM terminal (P-FET high-side switch). LED: green = on, red = off. Q5BSS138

AMP_REM Amplifier: AUDIOZERONE ZE500.1 (external): REM terminal + RCA/line input. Its power leads do not pass through this board.

AMP SIGNAL IN / GND

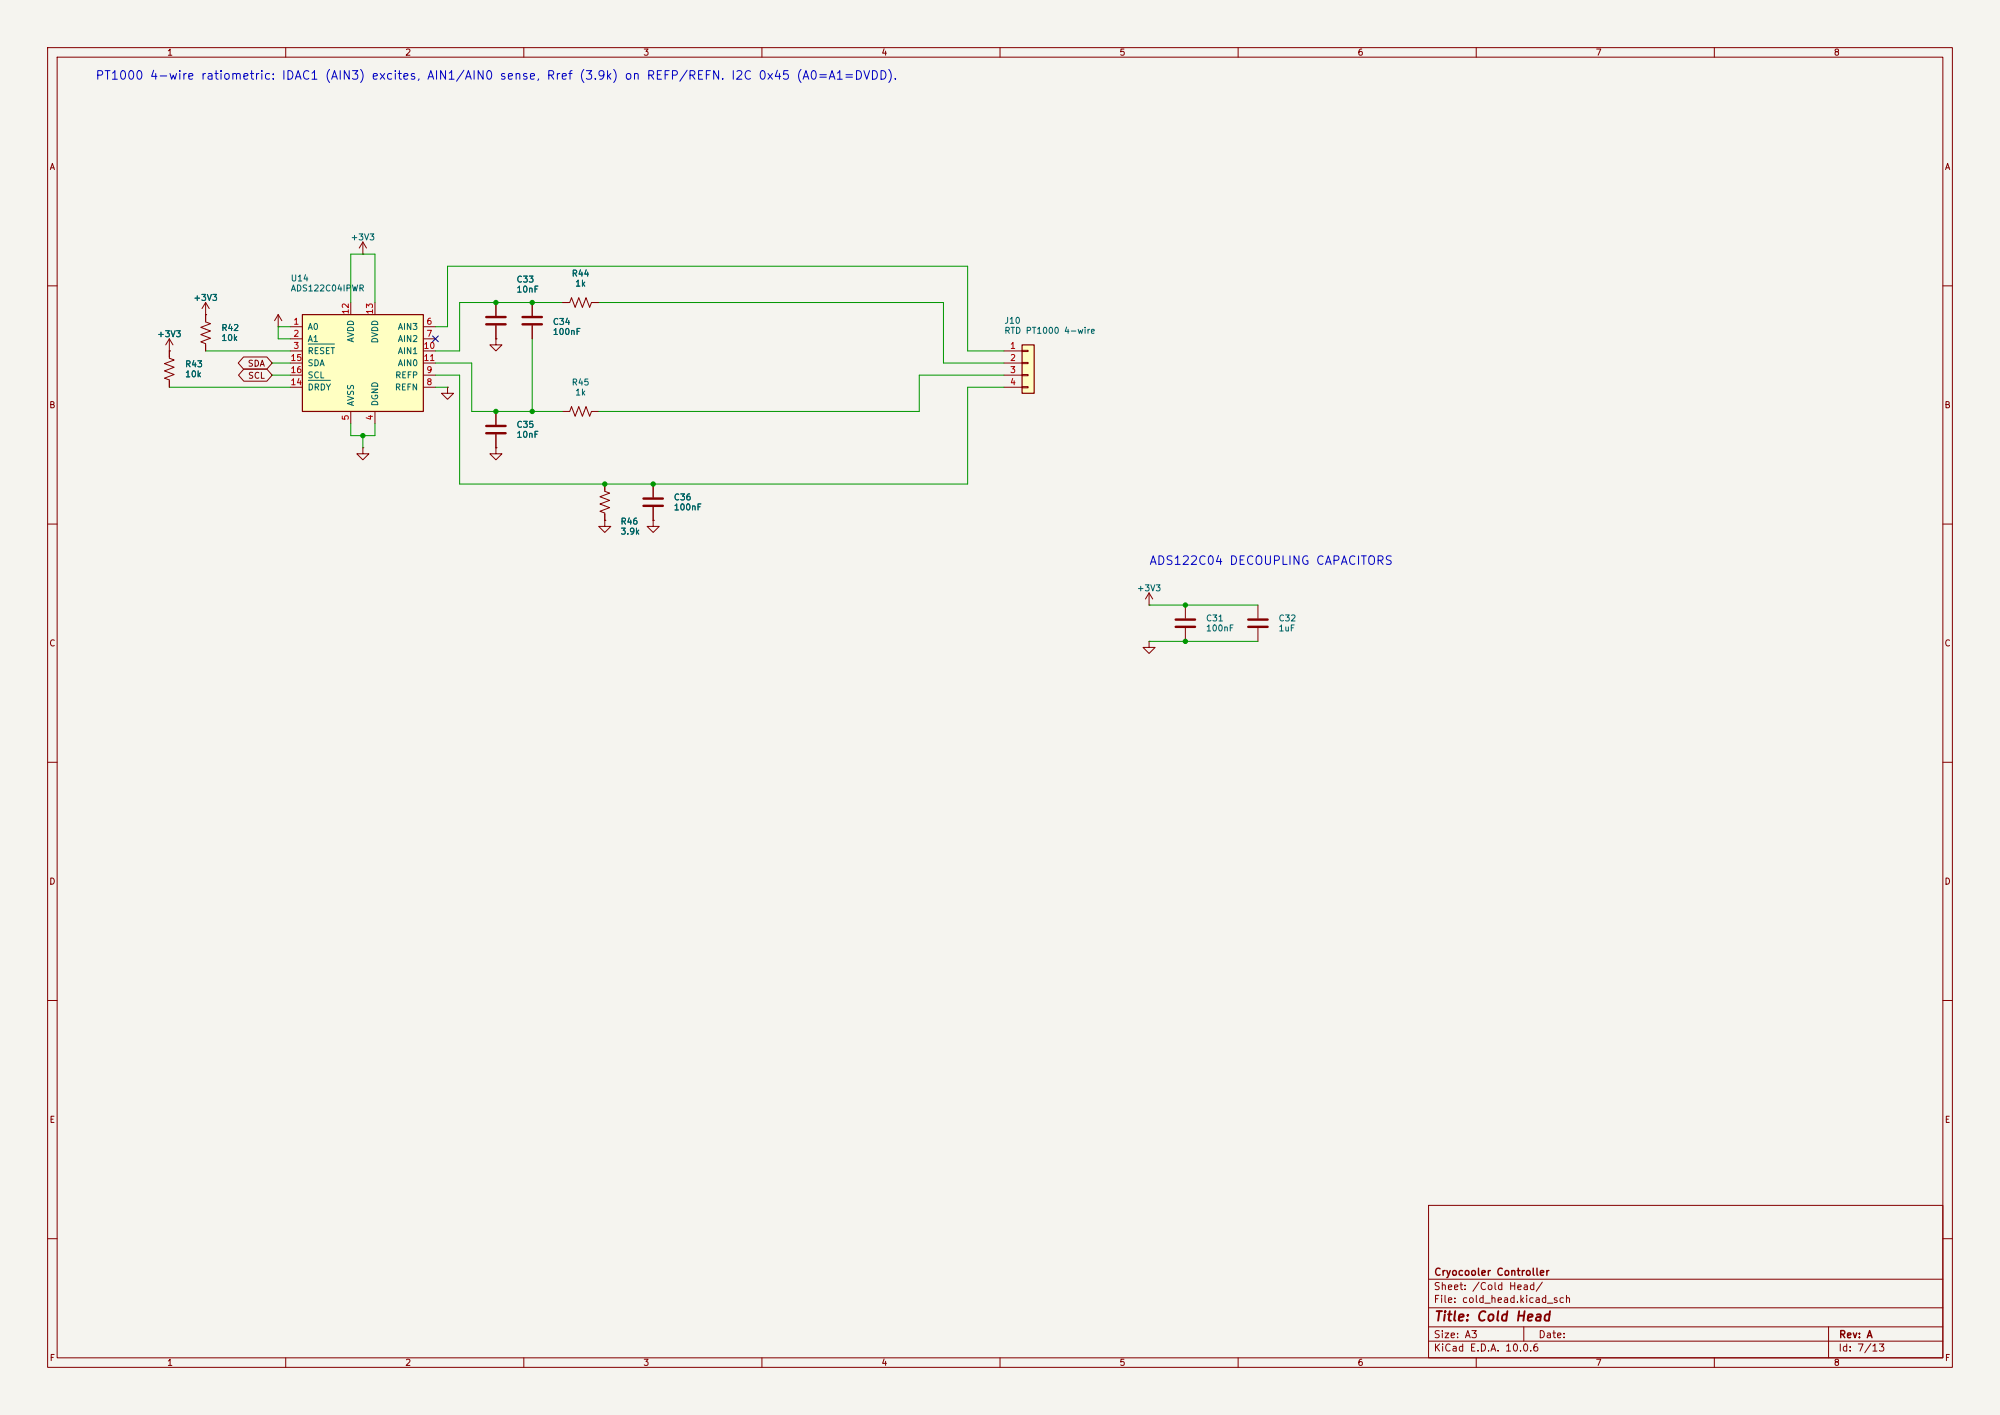
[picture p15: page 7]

1uF SDA SCL PT1000 4-wire ratiometric: IDAC1 (AIN3) excites, AIN1/AIN0 sense, Rref (3.9k) on REFP/REFN. I2C 0x45 (A0=A1=DVDD).

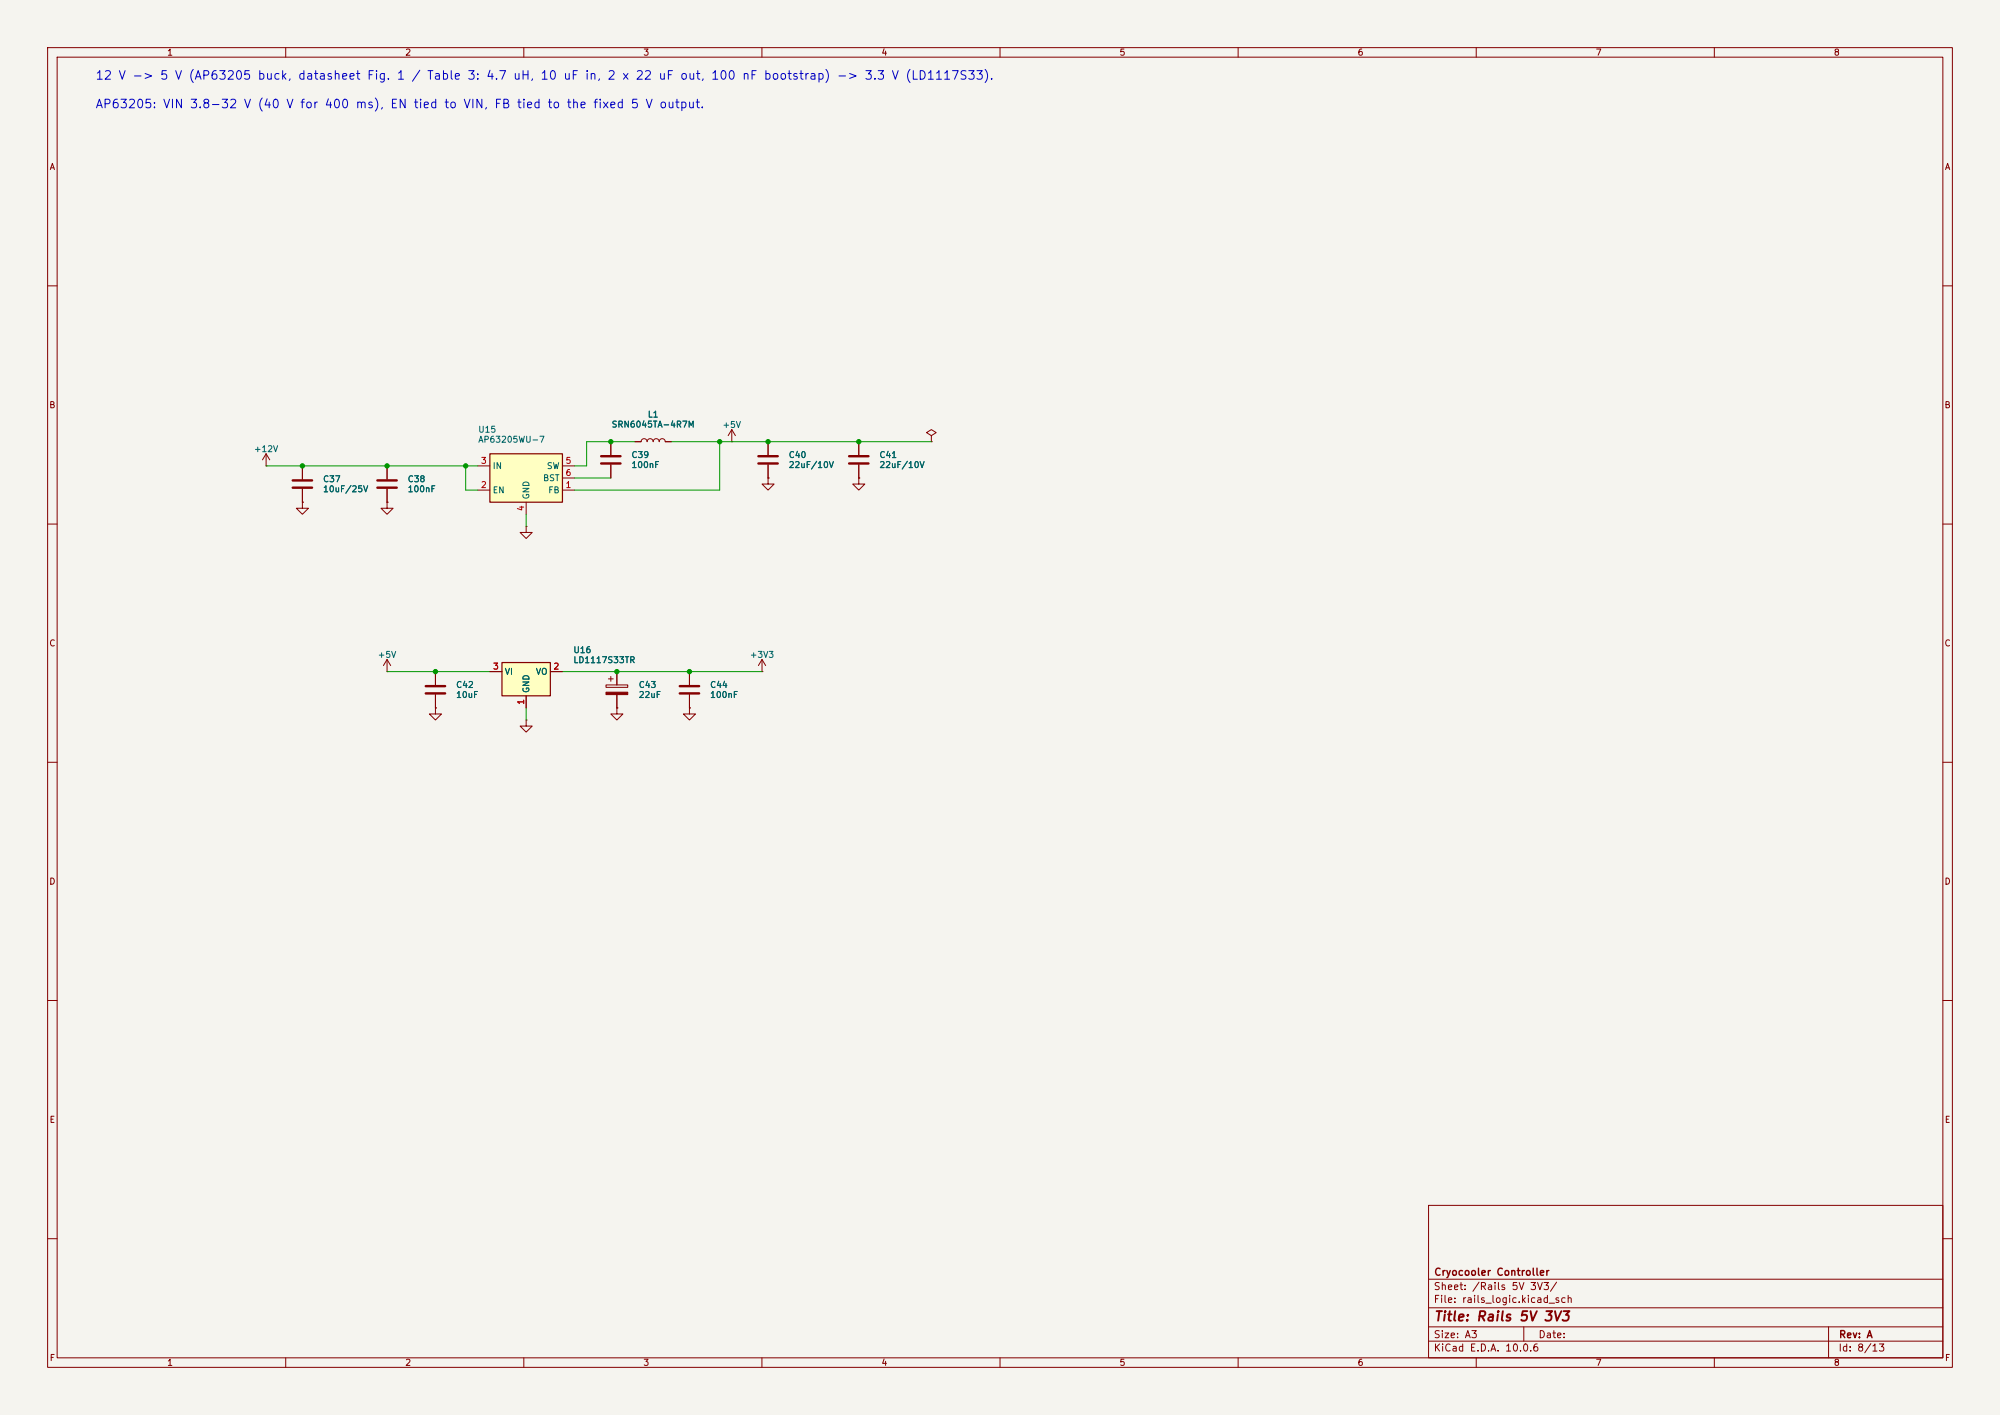
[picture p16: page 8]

SRN6045TA-4R7M 12 V -> 5 V (AP63205 buck, datasheet Fig. 1 / Table 3: 4.7 uH, 10 uF in, 2 x 22 uF out, 100 nF bootstrap) -> 3.3 V (LD1117S33).

AP63205: VIN 3.8-32 V (40 V for 400 ms), EN tied to VIN, FB tied to the fixed 5 V output. C39

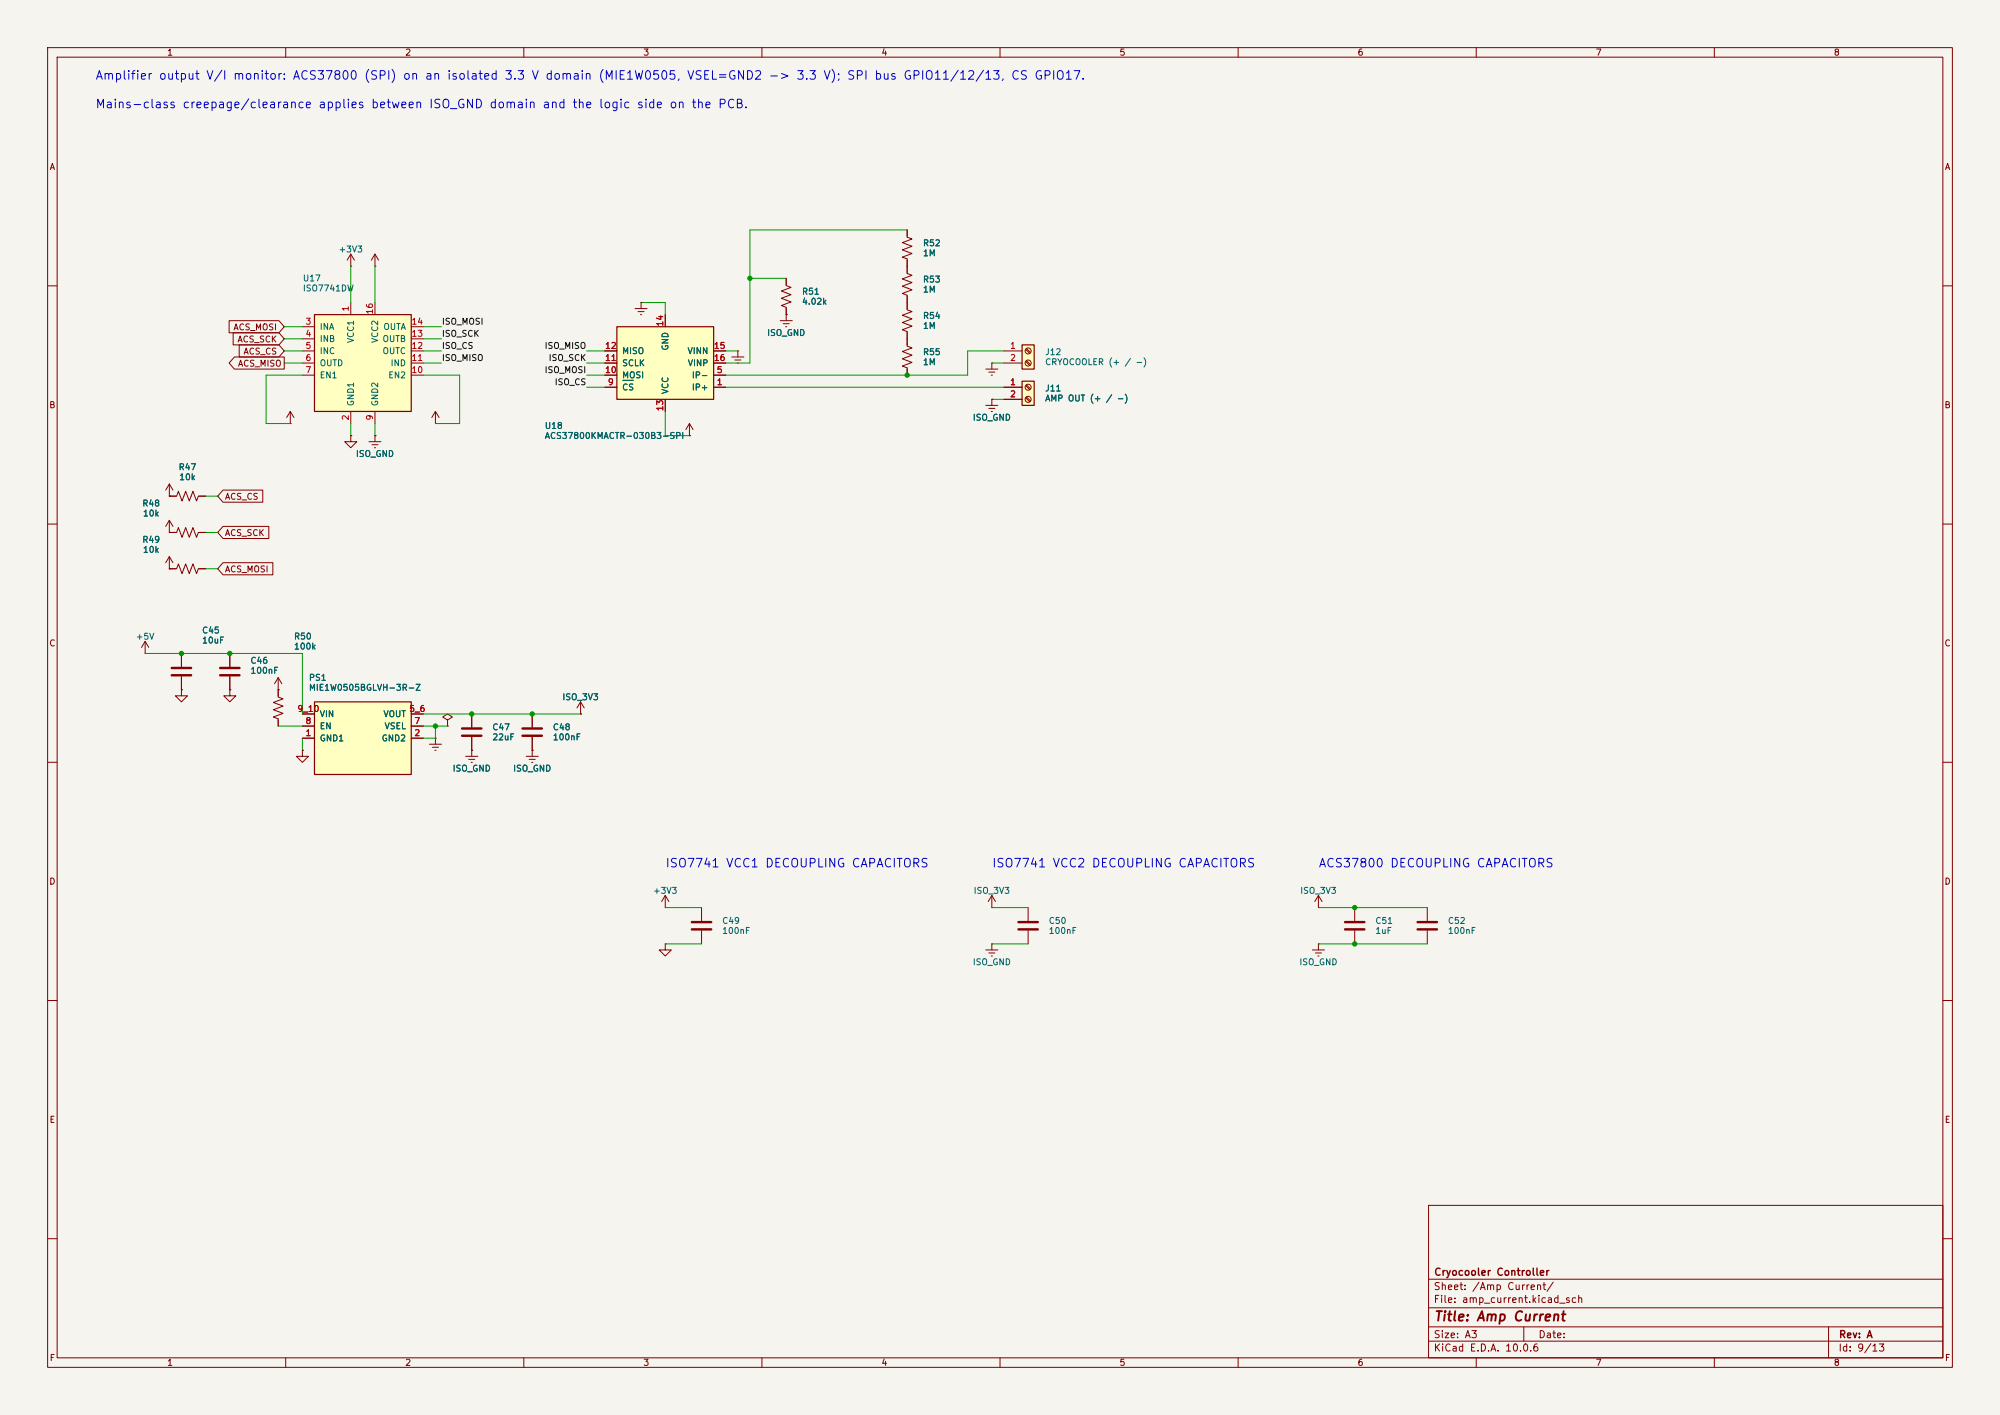
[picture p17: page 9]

Amplifier output V/I monitor: ACS37800 (SPI) on an isolated 3.3 V domain (MIE1W0505, VSEL=GND2 -> 3.3 V); SPI bus GPIO11/12/13, CS GPIO17.

ISO_CS Mains-class creepage/clearance applies between ISO_GND domain and the logic side on the PCB.

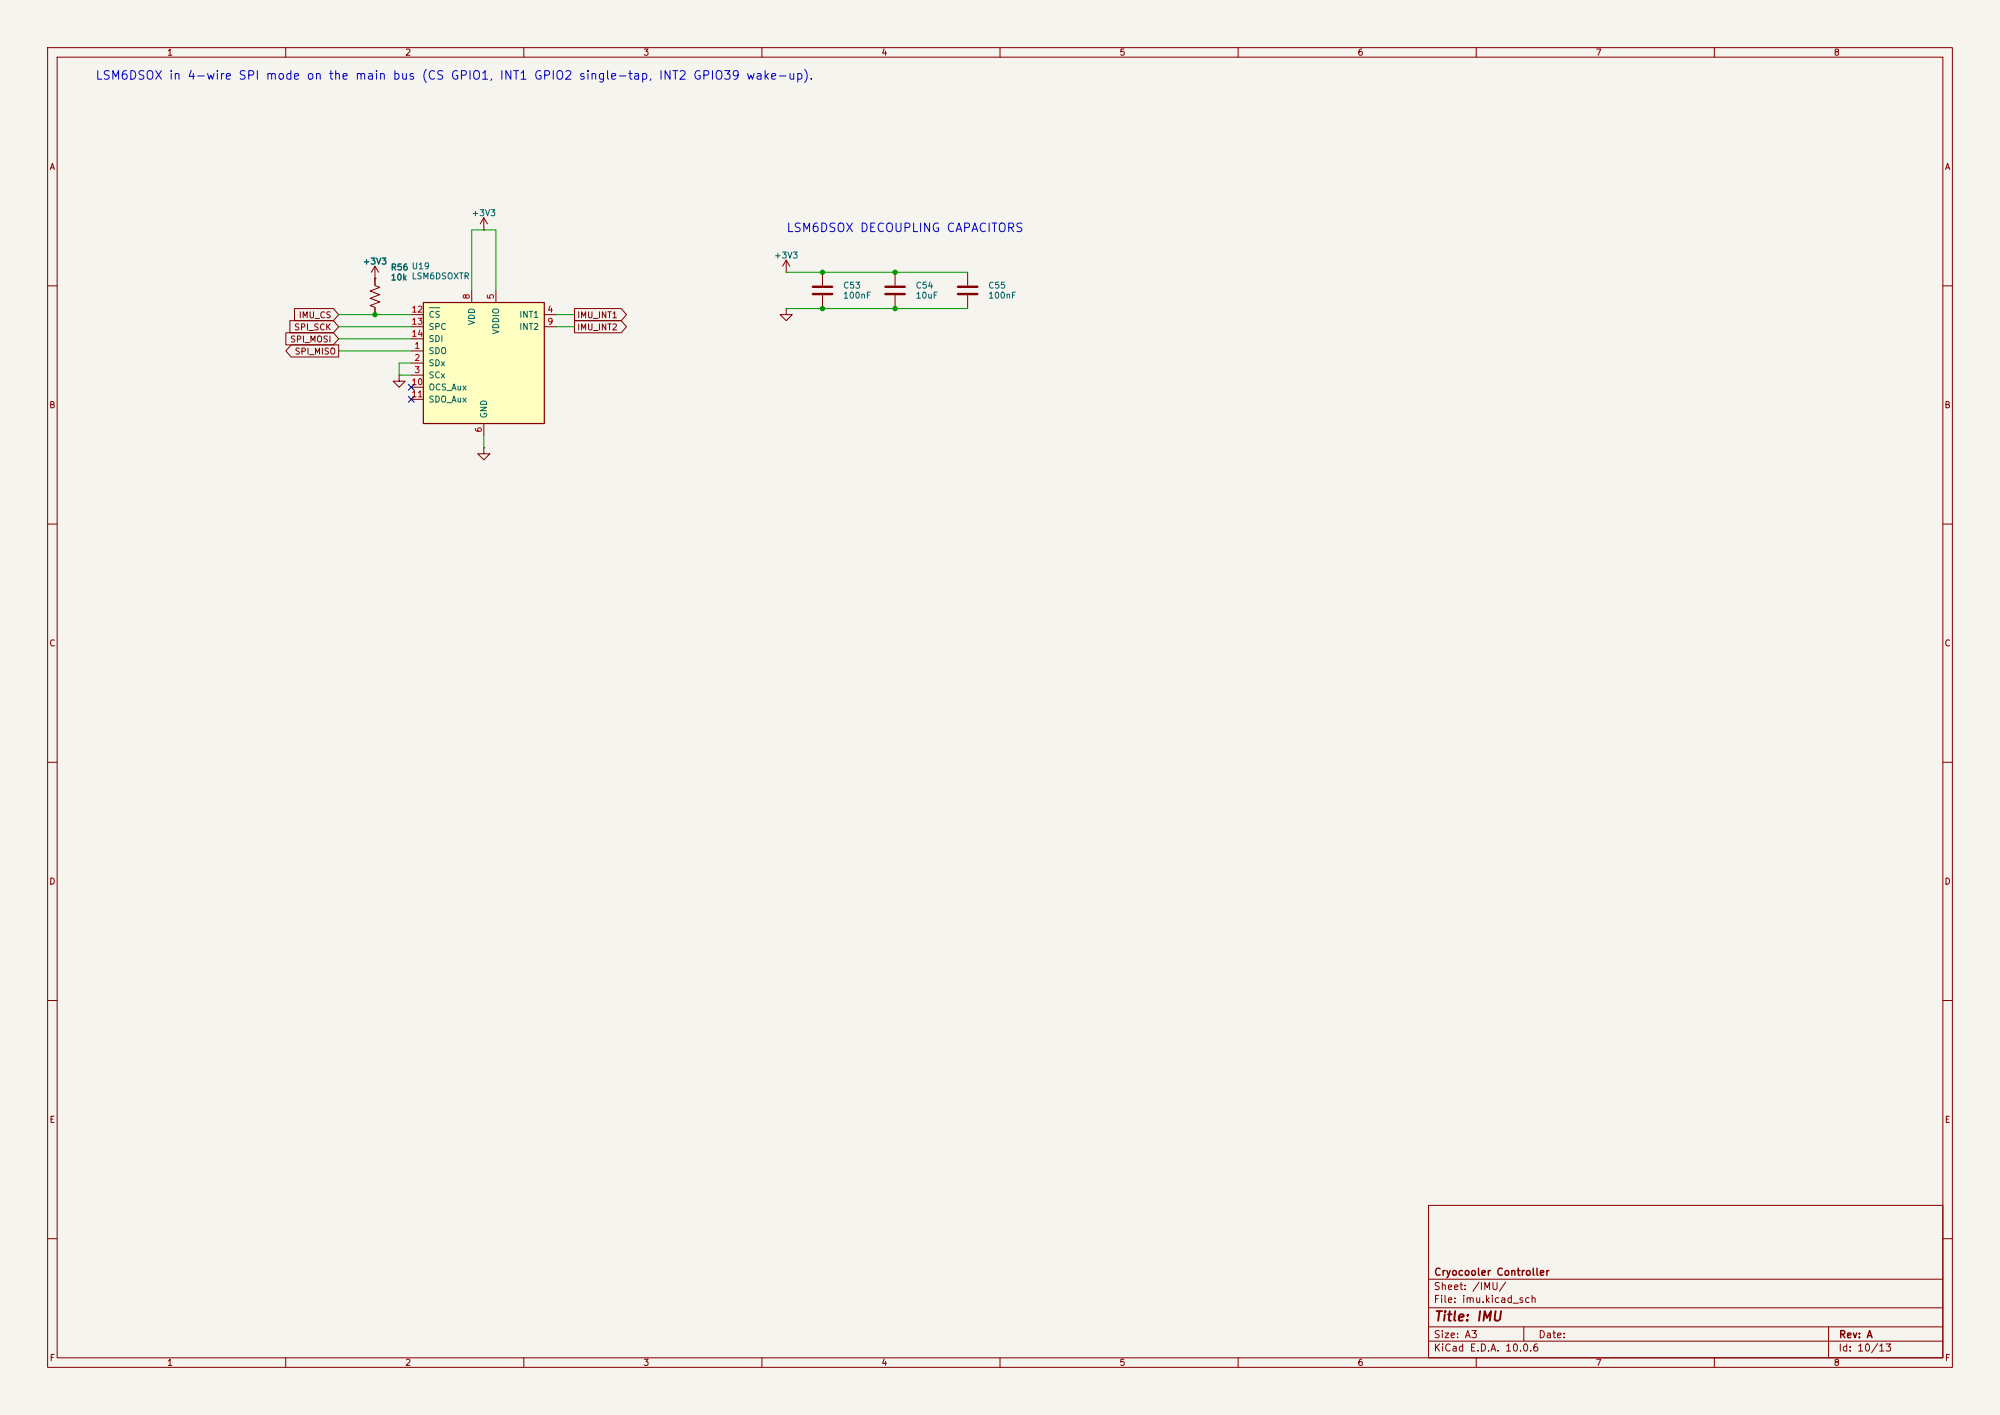
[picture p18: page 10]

LSM6DSOX in 4-wire SPI mode on the main bus (CS GPIO1, INT1 GPIO2 single-tap, INT2 GPIO39 wake-up). +3V3 R56

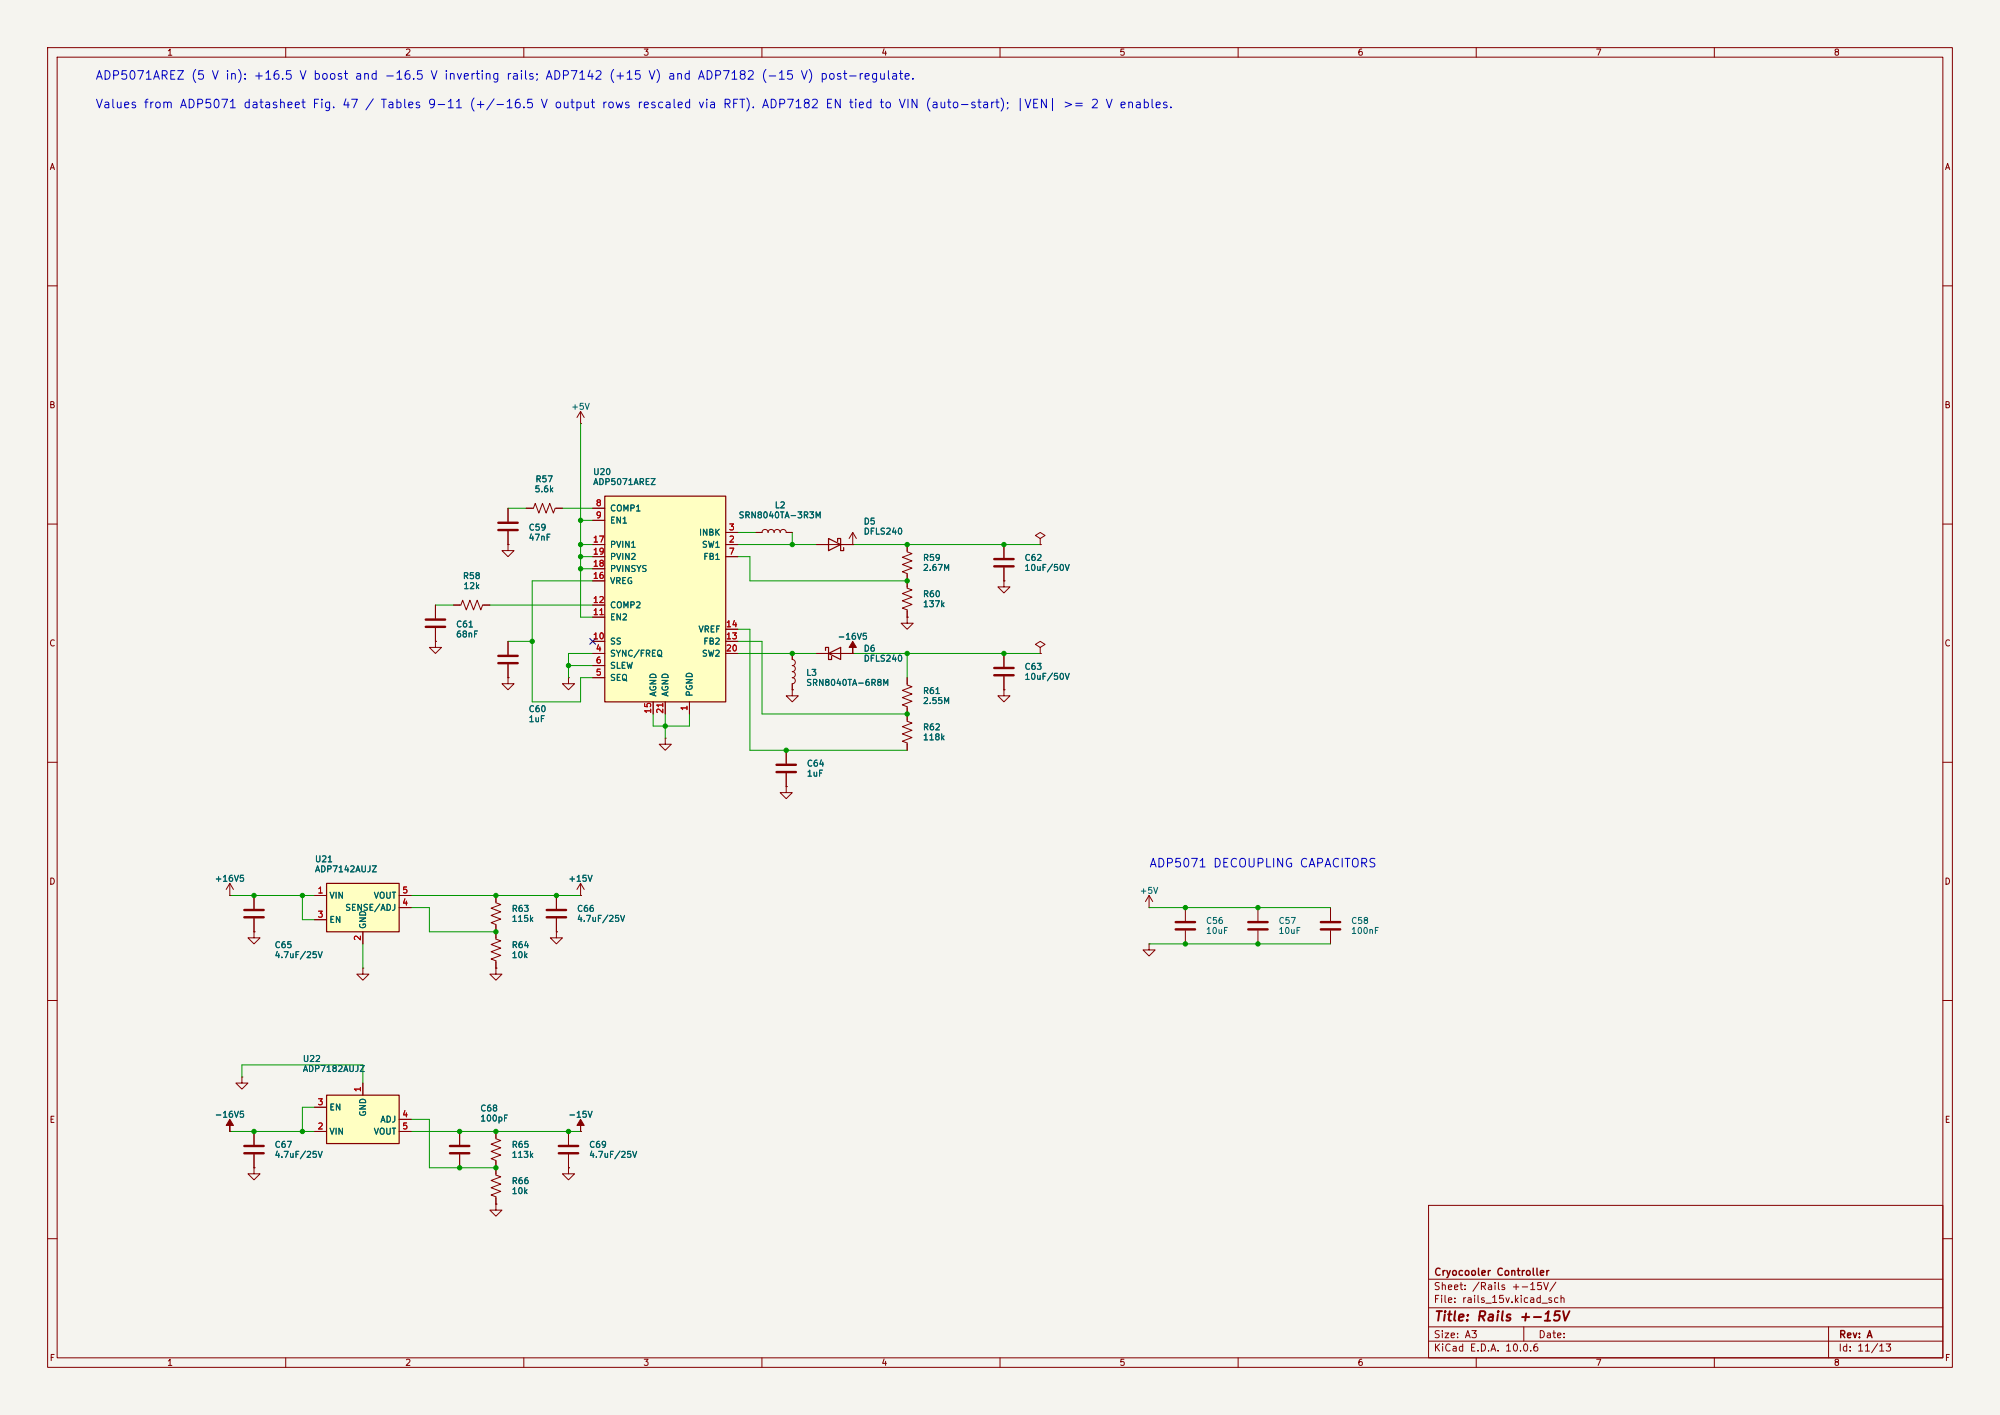
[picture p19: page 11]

ADP5071AREZ (5 V in): +16.5 V boost and -16.5 V inverting rails; ADP7142 (+15 V) and ADP7182 (-15 V) post-regulate.

Values from ADP5071 datasheet Fig. 47 / Tables 9-11 (+/-16.5 V output rows rescaled via RFT). ADP7182 EN tied to VIN (auto-start); |VEN| >= 2 V enables.

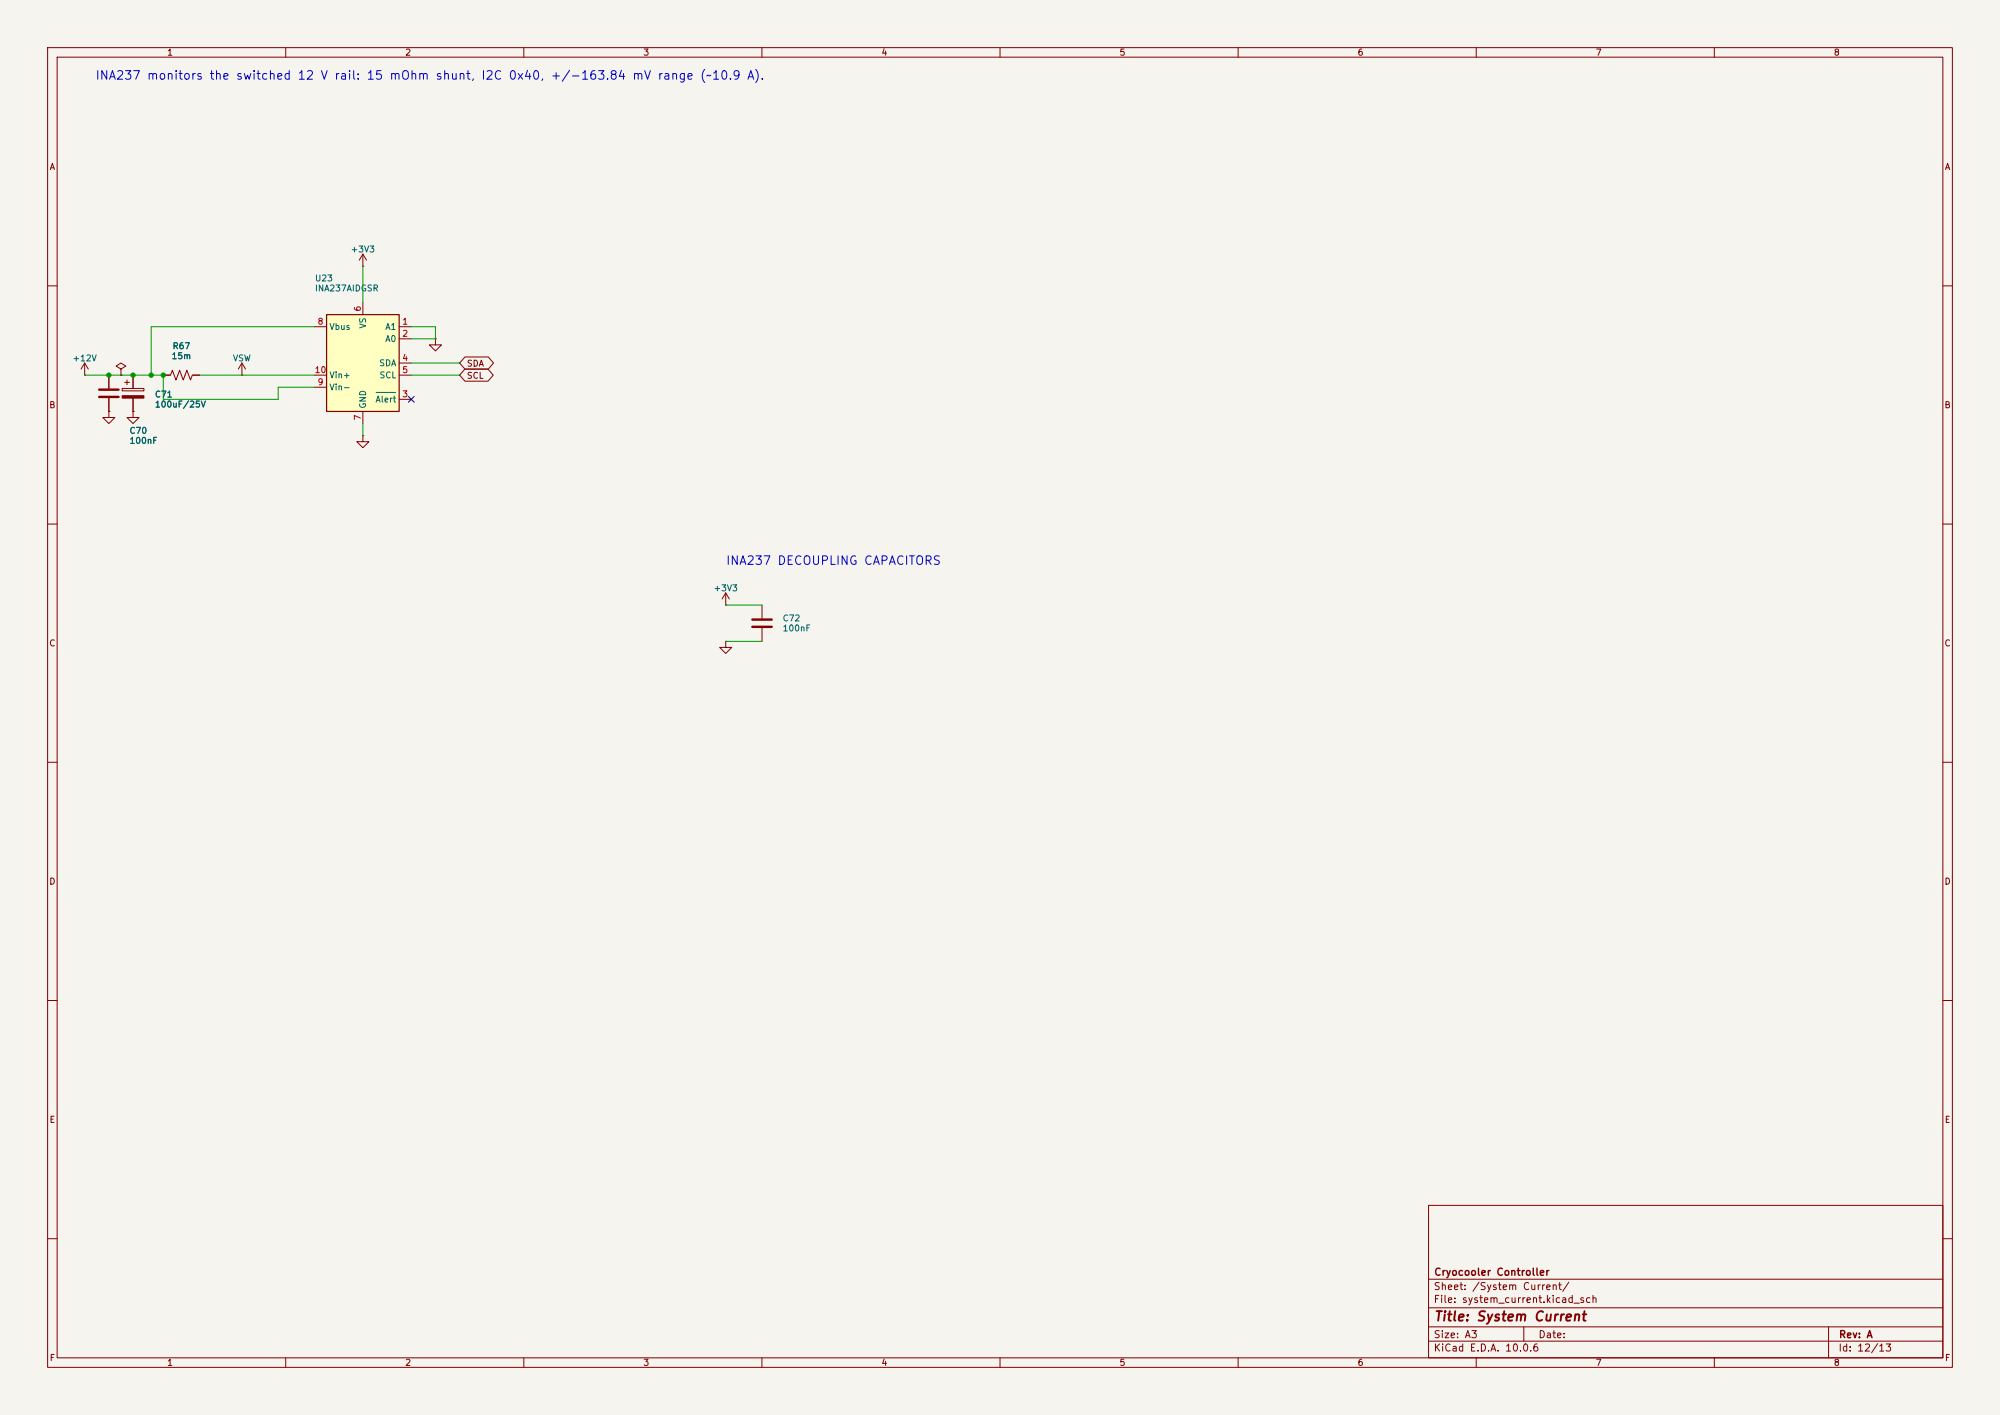
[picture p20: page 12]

INA237 monitors the switched 12 V rail: 15 mOhm shunt, I2C 0x40, +/-163.84 mV range (~10.9 A). R67


LED_FAULT LED_READY STATUS_RGB READY (GPIO15) and FAULT (GPIO14) LEDs, active high; WS2812B status LED on GPIO38 via a 74AHCT1G125 3.3 V -> 5 V level shifter (WS2812B VIH = 0.7 x VDD).

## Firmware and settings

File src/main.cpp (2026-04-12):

/**
 * @file main.cpp
 * @brief ESP32-S3 cryocooler controller -- application entry point
 *
 * Orchestrates all subsystem modules through the state machine and emits
 * one Serial Studio telemetry frame each loop tick.  See telemetry.h for
 * the full Serial Studio frame format and column definitions.
 *
 * Required Libraries (platformio.ini lib_deps):
 *   - SparkFun ADS122C04 ADC Arduino Library
 *   - MD_AD9833
 */

#include <Arduino.h>
#include <esp_system.h>   // esp_register_shutdown_handler()

#include "config.h"
#include "hardware.h"
#include "pin_config.h"
#include "cold_head.h"
#include "indicator.h"
#include "state_machine.h"
#include "telemetry.h"
#include "commands.h"
#include "sysinfo.h"
#include "cooling.h"
#include "dashboard.h"
#include "imu.h"
#include "sensor_mock.h"
#include "amplifier.h"
#include "compressor.h"
#include "logger.h"
#include "esp_log.h"
#include "ota.h"
#include "espnow.h"
#include "tick.h"
// =============================================================================
// Logging
// =============================================================================

static constexpr char TAG[] = "main";
static LogStream _Log = Log.createChildLogger("main");

// Printf-style function used by module::initGroup / serviceWithLog / reportStatus.
__attribute__((format(printf, 1, 2)))
static void logPrintf(const char* fmt, ...) {
    char buf[192];
    va_list ap;
    va_start(ap, fmt);
    vsnprintf(buf, sizeof(buf), fmt, ap);
    va_end(ap);
    _Log.print(buf);
}

// =============================================================================
// Module registry — init & service arrays
//
// Order within each array encodes dependency constraints:
//   - OTA before dashboard (registerRoutes must exist before setupServer)
//   - dashboard before espnow (WiFi must be up)
//   - compressor first in control group (de-energise relay ASAP)
//
// Special-cased modules that don't appear here:
//   - hardware    — fatal init, must succeed before anything else
//   - indicator   — init before WiFi to avoid neopixelWrite deadlock
//   - state_machine — non-standard update() signature
//   - telemetry   — emit(out) takes state_machine output
//   - cold_head   — in gated section, before state_machine
//   - sensor_mock — no Module struct
// =============================================================================

/// Modules initialized once at boot (never re-initialized on reinit).
static const module::ModuleEntry persistentModules[] = {
    MODULE_ENTRY(imu,       false),
    MODULE_ENTRY(ota,       false),
    MODULE_ENTRY(dashboard, false),
#if ENABLE_ESPNOW
    MODULE_ENTRY(espnow,    false),
#endif
    MODULE_ENTRY(telemetry, false),
    MODULE_ENTRY(sysinfo,   false),
};
static constexpr size_t NUM_PERSISTENT = sizeof(persistentModules) / sizeof(persistentModules[0]);

/// Control hardware modules — re-initialized on every FSM reinit().
static const module::ModuleEntry controlModules[] = {
#if ENABLE_COMPRESSOR
    MODULE_ENTRY(compressor, false),
#endif
    MODULE_ENTRY(cooling,    false),
    MODULE_ENTRY(amplifier,  false),
    MODULE_ENTRY(cold_head,  false),
};
static constexpr size_t NUM_CONTROL = sizeof(controlModules) / sizeof(controlModules[0]);

/// Modules serviced every loop() tick with health-transition logging.
static const module::ModuleEntry tickServiceModules[] = {
    MODULE_ENTRY(sysinfo,   false),
    MODULE_ENTRY(imu,       false),
    MODULE_ENTRY(amplifier, false),
    MODULE_ENTRY(cooling,   false),
};
static constexpr size_t NUM_TICK_SERVICE = sizeof(tickServiceModules) / sizeof(tickServiceModules[0]);

/// Combined list for the one-time boot status banner.
static const module::ModuleEntry allModulesForBanner[] = {
    MODULE_ENTRY(hardware,      true),
    MODULE_ENTRY(indicator,     false),
    MODULE_ENTRY(imu,           false),
    MODULE_ENTRY(ota,           false),
    MODULE_ENTRY(dashboard,     false),
    MODULE_ENTRY(sysinfo,       false),
    MODULE_ENTRY(cooling,       false),
    MODULE_ENTRY(amplifier,     false),
    MODULE_ENTRY(cold_head,     false),
    MODULE_ENTRY(state_machine, false),
#if ENABLE_COMPRESSOR
    MODULE_ENTRY(compressor,    false),
#endif
};
static constexpr size_t NUM_ALL_BANNER = sizeof(allModulesForBanner) / sizeof(allModulesForBanner[0]);

// =============================================================================
// Timing state
// =============================================================================

static uint32_t previousLoopMs = 0;
static uint32_t previousIndicatorUpdateMs = 0;

static uint32_t sSerialConnectionEstablishedMs = 0;
static uint32_t sSerialLastDetectedMs = 0;
static bool sSerialWelcomeMessageSent = false;

/**
 * Initialise modules required for the operator console and remote viewer to
 * function.  Called once in setup() before control hardware is initialised.
 *
 * These modules are intentionally never re-initialised by reinit() because
 * they provide the communication path through which the operator issues
 * commands — including the reinit command itself.
 *
 * Array order encodes dependencies (OTA before dashboard, dashboard before
 * espnow).  telemetry::emitSafe() is called after each step so the dashboard
 * shows real-time progress.
 */
static void initPersistentModules() {
    module::initGroup(persistentModules, NUM_PERSISTENT,
                      telemetry::emitSafe, logPrintf, yield);
}

/**
 * Initialise control hardware modules.
 *
 * This function is registered as the FSM's onInitialize callback and is
 * therefore called synchronously every time the machine enters the
 * Initialize state — both at startup and on any subsequent reinit() call.
 * That means hardware peripherals are re-initialised on a logical system
 * reset without requiring a full MCU reboot.
 *
 * Failures are non-fatal and do not halt startup.  Module init statuses are
 * persisted in each Module's static _initStatus; state_machine::start() reads
 * those statuses and blocks entry into any cooling state until all required
 * modules report MODULE_INIT_SUCCESS.  telemetry::emitSafe() is called after
 * each step so the dashboard shows real-time progress.
 *
 * indicator is intentionally omitted — it is initialised once in setup()
 * before WiFi starts to avoid a neopixelWrite() deadlock on ESP32-S3 with
 * Arduino 2.x.  It does not need re-initialisation on reinit().
 */
static void initControlModules() {
    module::initGroup(controlModules, NUM_CONTROL,
                      telemetry::emitSafe, logPrintf, yield);
}
// =============================================================================
// Setup
// =============================================================================

void setup() {
    Serial.setRxBufferSize(1024);
    Serial.begin(SERIAL_BAUD);
    delay(1000);
    //while (!Serial.available()) delay(100);

    _Log.println(F("Starting up"));
    _Log.println(F("Cryocooler Controller -- starting up"));
    _Log.println(F("====================================="));

    // Initialise shared buses before any module that needs them.
    // hardware::init() owns the single GuardedWire and SPIClass instances;
    // modules access them via hardware::i2c() / hardware::spi() rather than
    // the global Wire / SPI singletons.
    // hardware is fatal — halt if it fails (marked fatal in its ModuleEntry).
    {
        static const module::ModuleEntry hwEntry = MODULE_ENTRY(hardware, true);
        if (!module::initGroup(&hwEntry, 1, nullptr, logPrintf)) {
            _Log.println(F("Hardware bus init failed. Halting."));
            return;
        }
    }

    // Initialise the indicator LED before WiFi starts.  On ESP32-S3 with
    // Arduino 2.x, neopixelWrite() uses rmt_wait_tx_done() internally which
    // deadlocks if the WiFi stack is already up — WiFi interrupt priorities
    // can block the RMT "done" interrupt, hanging the main task indefinitely.
    // The indicator only needs GPIO + RMT (no I2C/SPI), so it is safe to run
    // here immediately after the hardware buses are ready.
    {
        static const module::ModuleEntry indEntry = MODULE_ENTRY(indicator, false);
        module::initGroup(&indEntry, 1, nullptr, logPrintf);
    }

    // Initialise the command line buffer before any modules — the serial
    // console must be ready so the operator can observe progress and send
    // commands even if control hardware fails to initialise.
    commands::init();

    // Bring up the console and viewer so the operator can observe progress
    // and send commands even if control hardware fails to initialise.
    initPersistentModules();

    // Initialise the FSM infrastructure (pure in-memory, always succeeds).
    state_machine::Module::init();

    // Register initControlModules as the onInitialize callback, then call
    // reinit() to enter the Initialize state.  This runs initControlModules()
    // synchronously — the same path taken on every subsequent reinit().
    state_machine::setOnInitializeCallback(initControlModules);
    state_machine::reinit();

    // Zero the DAC before any software-triggered reset (esp_restart(), IDF
    // watchdog recovery, etc.).  Hard resets (reset button, power cut) cannot
    // be caught here; initDac() handles those by force-writing 0 on every boot.
    esp_register_shutdown_handler([]() { amplifier::hardStop(); });

    _Log.println(F("[setup] Setup complete. System is initializing."));
    _Log.println(F("Type 'help' for available commands."));
}

// =============================================================================
// Main Loop
// =============================================================================

int serialAvailable = 0;

void loop() {
    tick::update();

    if ( Serial.available() != serialAvailable) {
        serialAvailable = Serial.available();
        ESP_LOGD(TAG, "Serial available: %d", static_cast<int>(serialAvailable));
    }
    //while (Serial.available()) { Serial.print("Serial:"); Serial.println(Serial.read()); }
    //while (Serial.available()) { Serial.read(); }
    //return;
    // One-time banner on the very first loop() iteration.
    // Lets the user know the loop has started and the console is ready —
    // i.e. this is the right moment to start typing commands.
    // @todo - This doesnt work unless the user is connected when the first loop is triggered
    static bool sLoopStarted = false;
    if (!sLoopStarted) {
        sLoopStarted = true;
        // Drain any characters that arrived in the USB RX buffer during setup
        // so they don't accidentally dispatch stale commands.
        //while (Serial.available()) { Serial.print("Serial:"); Serial.println(Serial.read()); }
        _Log.println();
        _Log.println(F(">>> Serial console active. Type 'help' for commands. <<<"));

        // Scan all modules for init failures and list them explicitly.
        module::reportStatus(allModulesForBanner, NUM_ALL_BANNER, logPrintf);
        Log.println();
    }

    // Serial command processing runs unconditionally so the console is always
    // reachable even when control hardware failed to initialise.
    // (The TCP/Serial-Studio path calls processLine() directly.)
    commands::service();

    // ── Per-tick module service ───────────────────────────────────────────
    // Each call returns a ServiceStatus.  SERVICE_ERROR is logged; all
    // modules are still serviced regardless so the control loop keeps running.
    // Only health-status transitions are logged (not every tick).
    //
    // Mock mode is handled inside each module: when sensor_mock::isActive(),
    // read() / service() pull values from sensor_mock::get() and skip hardware
    // access entirely.  No conditional logic is needed here.
    {
        static module::ServiceStatus prevStatus[NUM_TICK_SERVICE] = {};
        for (size_t i = 0; i < NUM_TICK_SERVICE; ++i) {
            module::serviceWithLog(tickServiceModules[i], prevStatus[i], logPrintf);
        }
    }

    const uint32_t nowMs = tick::nowMs();

    // I2C health monitor — Wire ESP_LOGE messages are suppressed; we count
    // errors via module service return codes and log periodic summaries.
    hardware::serviceI2c();

    if ((nowMs - previousIndicatorUpdateMs) < INDICATOR_UPDATE_INTERVAL_MS) {
        indicator::update();
        previousIndicatorUpdateMs = nowMs;
    }

    // Main control tick at LOOP_INTERVAL_MS cadence
    if ((nowMs - previousLoopMs) < LOOP_INTERVAL_MS) {
        return;
    }
    previousLoopMs = nowMs;
    indicator::update();

    // ---- 1. Read sensors ------------------------------------------------
    // Advance any active mock ramps before module reads, so that every module
    // sees the updated value on the same tick.
    sensor_mock::service();

    // Each module handles mock mode internally: when sensor_mock::isActive(),
    // read()/service() pulls from sensor_mock::get() instead of hardware.
    cold_head::service();  // includes fault checking internally

    // Read cached values.
    const float tempC       = cold_head::getLastTempC();
    //Serial.printf("tempC: %f\n", tempC);
    const float coolingRate = cold_head::getCoolingRateCPerMin();
    //Serial.printf("coolingRate: %f\n", coolingRate);
    const bool  stalled     = cold_head::isStalled();
    //Serial.printf("stalled: %d\n", stalled);

    const float rmsV        = amplifier::getLastRmsVoltage();

    const bool  overstroke  = imu::hasOverstroke();
    //Serial.printf("overstroke: %d\n", overstroke);
    const float sysVoltage  = sysinfo::getVoltage();
    //Serial.printf("sysVoltage: %f\n", sysVoltage);

    // ── Module undervoltage protection ───────────────────────────────────
    // Check every control module's minSystemVoltage() against the current
    // bus reading.  Modules whose threshold is breached are disabled and
    // demoted to UNDERVOLTAGE; they require a reinit to come back.
    // If any module was shut down, transition the FSM to Fault.
    if (module::checkVoltage(controlModules, NUM_CONTROL, sysVoltage, logPrintf)) {
        state_machine::triggerFault(state_machine::FaultReason::LowSystemVoltage);
    }

    // ---- 2. Advance state machine ---------------------------------------
    const auto out = state_machine::update(tempC, coolingRate, rmsV, stalled, overstroke, sysVoltage);
    // Clear edge-triggered overstroke flag after the state machine has consumed
    // it.  In real mode the flag was set by readCurrent(); in mock mode it was
    // set by setLastReadings().  Either way, clear it so it fires only once.
    if (overstroke) { imu::clearOverstroke(); }

    // ---- 3. Drive actuators ---------------------------------------------
    indicator::setFaultMode(out.faultIndMode);
    indicator::setReadyMode(out.readyIndMode);

    // DAC ramping is driven by state_machine::update() directly — either on
    // state entry (via on_enter callbacks) or per-tick for states with a
    // dynamic target (CoarseCooldown, FineCooldown, Shutdown).

    // ---- 4. Compressor timer -------------------------------------------
#if ENABLE_COMPRESSOR
    compressor::Module::service();
#endif

    // ---- 5. HTTP API ---------------------------------------------------
    //http_api::service();

    // ---- 6. Telemetry ---------------------------------------------------
    telemetry::emit(out);
    dashboard::Module::service();
}

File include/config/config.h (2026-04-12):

/**
 * @file config.h
 * @brief User-facing application configuration.
 *
 * This file contains the parameters most likely to need adjustment when
 * setting up, calibrating, or operating the cryocooler:
 *   - Hardware calibration (RTD type, sensor coefficients)
 *   - Operating setpoints (target temperature, safety limits)
 *   - Timing thresholds (settle duration, stall window)
 *   - Feature flags (telemetry, autostart)
 *
 * Pin assignments live in pin_config.h.
 * Internal algorithm parameters live in config_advanced.h, which is
 * included at the bottom of this file — no need to include it separately.
 *
 * NOTE: ADS122C04 enum values (gain, IDAC, mode) are defined in the
 * SparkFun ADS122C04 library header.
 */

#ifndef CONFIG_H
#define CONFIG_H

#include <stdint.h>

#include "pin_config.h"
#include "arduino_secrets.h"

// =============================================================================
// Compressor
// =============================================================================

// Enable the compressor relay subsystem.
// Set false to skip initialisation and service entirely (e.g. when the
// Qwiic relay hardware is not fitted or you want to bench-test without it).
#define ENABLE_COMPRESSOR false

// Hard upper limit on how long a timed compressor run may last.
// Any 'compressor start' duration exceeding this value is clamped to it.
// Set to 0 to disable the limit (not recommended).
#define COMPRESSOR_MAX_RUN_MS   static_cast<uint32_t>(120u * 60u * 1000u)  // 2 hours in milliseconds

// =============================================================================
// System
// =============================================================================

#define HOSTNAME      "cryocooler"

#define ENABLE_LOGGER false

// Enable HTTP OTA firmware updates (GET /ota — upload form, POST /ota — flash).
// Requires an OTA-capable partition table (partitions.csv) and WiFi connectivity.
// Set false to compile out the OTA endpoint entirely.
#define ENABLE_OTA true

#define SERIAL_BAUD   static_cast<uint32_t>(115200)

// =============================================================================
// Network / HTTP API
// =============================================================================

#define HTTP_API_PORT static_cast<uint16_t>(80)
#define WS_PORT       static_cast<uint16_t>(8080)

// =============================================================================
// ESP-NOW — peer-to-peer telemetry bridge
// =============================================================================
//
// ESP-NOW coexists with WiFi (STA mode) on the same radio.  The transmit
// channel is determined automatically by the AP association — the peer device
// must be configured to listen on the same channel.
//
// Fragmentation: ESP-NOW frames are limited to 250 bytes.  Telemetry JSON is
// split into 246-byte chunks, each prefixed with a 4-byte header:
//   [msg_id][total_chunks][chunk_index][payload_len][...JSON fragment...]
// The peer reassembles chunks that share the same msg_id (wraps at 255).

// Enable ESP-NOW telemetry forwarding.  WiFi, HTTP dashboard, and OTA all
// remain fully operational when this is true.
#define ENABLE_ESPNOW  false

// MAC address of the receiving ESP32.
// Find it by running `Serial.println(WiFi.macAddress())` on the peer.
// Format: {0xAA, 0xBB, 0xCC, 0xDD, 0xEE, 0xFF}
// IMPORTANT: replace the placeholder below before enabling ESP-NOW.
// d0:cf:13:05:6f:0c
#define ESPNOW_PEER_MAC  { 0xd0, 0xcf, 0x13, 0x05, 0x6f, 0x0c }

// Telemetry burst interval sent to the peer (milliseconds).
// 1000 ms matches the dashboard broadcast cadence.
#define ESPNOW_SEND_INTERVAL_MS  static_cast<uint32_t>(1000)

// =============================================================================
// Telemetry
// =============================================================================

#define TELEMETRY_ENABLED        true

// Emit telemetry frames even while the cryocooler is in the Idle state.
// Requires TELEMETRY_ENABLED true.
#define EMIT_TELEMETRY_WHEN_IDLE true

// =============================================================================
// RTD Sensor (ADS122C04 + PT1000)
// =============================================================================

#define ANALOG_RESOLUTION static_cast<uint8_t>(12)

// Reference resistor value in ohms (external precision resistor between
// REFP and REFN on the ADS122C04 board).  Adjust to your measured value.
#define PT1000_REF_R    static_cast<float>(3854.0f)

// ADC gain setting.  Gain 1 with PGA disabled for PT1000 (high signal).
#define PT1000_GAIN     static_cast<float>(1.0f)

// Nominal 0 °C resistance of the PT1000 RTD element.
#define PT1000_R0       static_cast<float>(1000.0f)

// 24-bit ADC full-scale value (2^23 for signed).
#define ADS122C04_ADC_FULL_SCALE  static_cast<float>(8388608.0f)
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

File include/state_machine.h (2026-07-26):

/**
 * @file state_machine.h
 * @brief Cryocooler system state machine
 *
 * Implements the ten-state control sequence:
 *
 *   -1 Off           - System powered down (not running)
 *    0 Initialize    - Power-up: AMBER flash, amplifier relay off, DAC = 0
 *    1 Idle          - Warm / standby: FAULT RED, amplifier relay off, DAC = 0
 *    2 CoarseCooldown - Cooling above 85 K: FAULT flash fast RED, ramp DAC
 *    3 FineCooldown   - Cooling below 85 K: + READY flash slow GREEN
 *    4 Overshoot      - Below setpoint, integrator settling: READY flash fast GREEN
 *    5 Settle         - Near setpoint, Normal relay engaged
 *    6 Baseline       - Collecting baseline: READY ON GREEN
 *    7 Operating      - Normal run: READY ON GREEN
 *    8 Shutdown       - Graceful stop: ramp DAC to 0 (relay stays on), then relay off → Idle
 *    9 Delay          - Timed wait: hold for N ms, then advance to configured next state
 *  127 Fault          - Any fault condition: FAULT flash fast RED, alarm relay active (terminal state), amplifier relay off
 *
 * Transition inputs on every update() call:
 *   - tempC          : current cold-stage temperature in Celsius
 *   - coolingRate    : C/min (positive = cooling)
 *   - rmsVoltage     : measured RMS voltage (stub; 0.0 until implemented)
 *   - stalled        : true when temp has not dropped enough in STALL_DETECT_WINDOW_MS
 *   - tick::nowMs()  : current tick timestamp
 *
 * The module is pure logic — no Serial or hardware calls — so it can be
 * unit-tested on the native (host-PC) platform.
 */

#ifndef STATE_MACHINE_H
#define STATE_MACHINE_H

#include <stdint.h>
#include <time.h>
#include "config.h"
#include "indicator.h"
#include "module.h"
#include "tick.h"

namespace state_machine {

/**
 * X-macro table for all system states.
 * Each row:  X(enumerator, int8_t value, short name, status text)
 *
 * The status text for State::Fault is dynamic (it depends on the active
 * FaultReason) and is handled separately in statusTextForState() inside
 * state_machine.cpp.  nullptr is used here as an explicit sentinel; it is
 * never returned to callers at runtime.
 *
 * Usage patterns
 * ──────────────
 * Generate the enum body:
 * @code
 *   #define X(name, value, sname, status) name = value,
 *   STATE_MACHINE_STATES(X)
 *   #undef X
 * @endcode
 *
 * Generate a name-lookup switch:
 * @code
 *   #define X(name, value, sname, status) case State::name: return sname;
 *   STATE_MACHINE_STATES(X)
 *   #undef X
 * @endcode
 */
#define STATE_MACHINE_STATES(X)                                                                                              \
    X(Off,            -1,  "Off",            "System is off")                                                            \
    X(Initialize,      0,  "Initialize",     "Initial power up state")                                                   \
    X(Idle,            1,  "Idle",           "Cold stage is warm; dewar is not cooling")                                 \
    X(CoarseCooldown,  2,  "CoarseCooldown", "Cooling; cold stage is above -188 °C")                                    \
    X(FineCooldown,    3,  "FineCooldown",   "Cooling; cold stage is below -188 °C")                                     \
    X(Overshoot,       4,  "Overshoot",      "Cold stage is cooler than set point; integrator is settling")              \
    X(Settle,          5,  "Settle",         "Cold stage temperature is settling; circuits switched to Normal")           \
    X(Baseline,        6,  "Baseline",       "Cold stage temperature has settled; collecting baseline data")              \
    X(Operating,       7,  "Operating",      "System is operating normally; checking for deviations from baseline")      \
    X(Shutdown,        8,  "Shutdown",       "Gracefully shutting down; ramping DAC to zero (relay on)")                 \
    X(Delay,           9,  "Delay",          "Timed wait; will advance to next state after delay expires")               \
    X(Fault,         127,  "Fault",          nullptr)   /* status text is computed at runtime — see statusTextForState() */

/** System states as per design spec.  Generated from STATE_MACHINE_STATES. */
enum class State : int8_t {
#define X(name, value, sname, status) name = value,
    STATE_MACHINE_STATES(X)
#undef X
};


/**
 * Fault reason flags — stored as a bitmask so multiple simultaneous
 * conditions can be captured in a single FaultRecord.
 *
 * Each enumerator is a unique power-of-2 bit.  Use bitwise OR to combine:
 *   faultReason = FaultReason::LowSystemVoltage | FaultReason::TemperatureStall;
 *
 * Test individual bits:
 *   if (static_cast<uint8_t>(r) & static_cast<uint8_t>(FaultReason::RmsOvervoltage)) …
 *
 * Use formatFaultReasons() to produce a human-readable pipe-delimited string.
 */
enum class FaultReason : uint8_t {
    None              = 0,
    RmsOvervoltage    = 1u << 0,  ///< amplifier RMS voltage exceeded AMPLIFIER_MAX_VOLTAGE_VAC
    TemperatureStall  = 1u << 1,  ///< cold stage failed to cool within STALL_DETECT_WINDOW_MS
    TooManyBackoffs   = 1u << 2,  ///< back-EMF backoff event count reached BACKOFF_MAX_COUNT
    LowSystemVoltage  = 1u << 3,  ///< DC supply voltage fell below MIN_SYSTEM_VOLTAGE_VDC
    StateOscillation  = 1u << 4,  ///< FSM bouncing between the same two states too many times
    SensorFault       = 1u << 5,  ///< RTD hardware fault or tempC outside MIN/MAX_PLAUSIBLE_COLDHEAD_TEMP_C
    RmsOvercurrent    = 1u << 6,  ///< amplifier RMS current exceeded AMPLIFIER_MAX_CURRENT_A
    ModuleNotReady    = 1u << 7,  ///< a required control module was not initialised when a cooling
                                  // state was entered
};

/** Bitwise OR — combine two fault reasons into a composite mask. */
inline FaultReason operator|(FaultReason a, FaultReason b) {
    return static_cast<FaultReason>(static_cast<uint8_t>(a) | static_cast<uint8_t>(b));
}
/** Bitwise OR-assign — accumulate fault bits in place. */
inline FaultReason& operator|=(FaultReason& a, FaultReason b) {
    a = a | b;
    return a;
}

/**
 * Return a short ASCII name for a single-bit FaultReason.
 * Only meaningful when exactly one bit is set; use formatFaultReasons()
 * for composite (multi-fault) values.
 */
inline const char* faultReasonName(FaultReason r) {
    switch (r) {
        case FaultReason::None:             return "None";
        case FaultReason::RmsOvervoltage:   return "RmsOvervoltage";
        case FaultReason::TemperatureStall: return "TemperatureStall";
        case FaultReason::TooManyBackoffs:  return "TooManyBackoffs";
        case FaultReason::LowSystemVoltage: return "LowSystemVoltage";
        case FaultReason::StateOscillation: return "StateOscillation";
        case FaultReason::SensorFault:      return "SensorFault";
        case FaultReason::RmsOvercurrent:   return "RmsOvercurrent";
        case FaultReason::ModuleNotReady:   return "ModuleNotReady";
        default:                            return "Multi";
    }
}
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

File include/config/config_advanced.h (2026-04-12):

/**
 * @file config_advanced.h
 * @brief Advanced / implementation-level parameters.
 *
 * This file is included automatically by config.h — do not include it
 * directly.  All symbols defined here are available to any translation
 * unit that includes config.h.
 *
 * These parameters govern internal algorithmic behaviour (ramp tuning,
 * ADC internals, loop timing, tracking-monitor thresholds, FSM diagnostics,
 * etc.).  They have been calibrated for the reference hardware and should
 * not need adjustment during normal operation.  Change them only if you
 * are modifying the underlying hardware or retuning the control algorithms.
 */

#ifndef CONFIG_ADVANCED_H
#define CONFIG_ADVANCED_H

#include <stdint.h>


// =============================================================================
// Relays
// =============================================================================
// Compressor relay: SparkFun Qwiic Single Relay (I2C, COMPRESSOR_RELAY_ADDR in pin_config.h)
// Amplifier relay:  GPIO-driven (AMPLIFIER_RELAY_PIN in pin_config.h)

// =============================================================================
// ADC / DAC internals
// =============================================================================

// ADC read resolution in bits (9–12 on ESP32).
#define ADC_RESOLUTION    static_cast<uint8_t>(12)

// ADC readings below this raw count are treated as 0 (noise floor / off).
#define ADC_MIN_VOLTAGE   static_cast<uint8_t>(15)

// 12-bit DAC full scale (0–4095).  Fixed by the MCP4921 hardware.
// Voltage resolution is ~0.029 V/step (120 V / 4095).
#define AMPLIFIER_RESOLUTION  static_cast<uint16_t>(4095)

// =============================================================================
// Amplifier ramp rates (DAC counts per LOOP_INTERVAL_MS tick)
// =============================================================================
//
// Scaled ×16 from 12-bit values to preserve the same wall-clock ramp speed
// at 16-bit resolution.

// Maximum DAC increment per main-loop tick (soft ramp-rate cap).
// Scaled for 12-bit MCP4921 (4095 full scale).
// At LOOP_INTERVAL_MS = 200 ms, 16 counts/tick → full-scale in ~51 s.
#define AMPLIFIER_MAX_STEP_PER_INTERVAL       static_cast<uint16_t>(16)

#define AMPLIFIER_RAMP_RATE_VERY_FAST         static_cast<uint16_t>(16)
#define AMPLIFIER_RAMP_RATE_FAST              static_cast<uint16_t>(16)
#define AMPLIFIER_RAMP_RATE_MEDIUM            static_cast<uint16_t>(16)
#define AMPLIFIER_RAMP_RATE_SLOW              static_cast<uint16_t>(32)
#define AMPLIFIER_RAMP_RATE_VERY_SLOW         static_cast<uint16_t>(48)

// DAC step size during the shutdown ramp (ramps down much faster than up).
// At LOOP_INTERVAL_MS = 200 ms, 208 counts/tick → full-scale in ~4 s.
#define AMPLIFIER_DAC_SHUTDOWN_STEP_PER_INTERVAL  static_cast<uint16_t>(208)

// The DAC output should only output 0-10vdc. This is the multiplier voltage
// that gets passed to the AD633 voltage
#define AMPLIFIER_DAC_MAX_OUTPUT_VOLTAGE_V   static_cast<float>(10.0f)

// =============================================================================
// ACS712 AC Current Sensor — internal ADC constants
// =============================================================================

// ADC supply voltage on the ESP32-S3 (3.3 V rail).
#define ACS712_ADC_VOLTS      static_cast<float>(3.3f)

// Maximum ADC output value for ADC_RESOLUTION = 12 → (2^12) − 1 = 4095.
#define ACS712_ADC_MAX_VALUE  static_cast<uint16_t>((1u << ADC_RESOLUTION) - 1u)

// ESP32 ADC attenuation for ACS712_CURRENT_PIN.
// ADC_11db → 0–3.3 V (full 5 A range; default safe choice).
#ifdef ARDUINO
#  define ACS712_ADC_ATTENUATION  ADC_11db
#endif

// =============================================================================
// Overstroke (back-EMF spike) detection — algorithm internals
// =============================================================================

// EMA smoothing factor for the current baseline (0 < α ≤ 1).
// Smaller values track more slowly so brief spikes stand out more clearly.
#define OVERSTROKE_EMA_ALPHA          static_cast<float>(0.08f)

// Number of readCurrent() calls to prime the EMA before detection is armed.
// At LOOP_INTERVAL_MS = 200 ms this is ~4 seconds.
#define OVERSTROKE_PRIME_READINGS     static_cast<uint8_t>(20)

// Minimum time between consecutive overstroke detections (milliseconds).
// Prevents a single physical event from generating many consecutive flags.
#define OVERSTROKE_DEBOUNCE_MS        static_cast<uint32_t>(200)

// DAC counts subtracted from the target per confirmed backoff event.
// At AMPLIFIER_RESOLUTION = 4095, each step is ~4.9 % of full scale.
#define BACKOFF_DAC_STEP              static_cast<uint16_t>(200)
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

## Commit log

2026-02-19 using namespaces to avoid function name collisions.
    [conversions.h, main.cpp, temperature.cpp]
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2026-03-07 Fixing fsm, moving dependency check to fsm start state prechecks
    [commands.cpp, main.cpp, state_machine.h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]
2026-03-08 Switching out some of the modules; fixing mock;
    [cold_head.cpp, imu.cpp, sensor_mock.h]
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2026-03-11 Fixing a few things.
    [config_advanced.h, cooling.cpp, imu.cpp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]
2026-03-11 Fixing the fam/pump rpm readings
    [config_advanced.h, cooling.cpp]
2026-03-11 Fixing the serial bug. No thanks to AI, jeez
    [amplifier.cpp, commands.cpp, config_advanced.h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]
2026-03-12 Workin out the bugs; switched the relay module
    [amplifier.cpp, commands.cpp, compressor.cpp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]
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2026-03-13 Fixing the faults in dashboad, and a fsm state loop
    [commands.cpp, state_machine.h]
2026-03-17 Updating dashboard, fixing a few things, changing the voltage based logic to fractions
    [amplifier.cpp, cold_head.cpp, commands.cpp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]
2026-03-18 Reconnect logic, and other fixes
    [cold_head.cpp, commands.cpp, config_advanced.h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]
2026-03-19 Replace dual EMC2101 with single EMC2302 via new EMC230x library
    Migrate cooling module from two separate Adafruit_EMC2101 ICs to a single
    EMC2302-2 dual-channel controller using a custom EMC230x Arduino library.
    Key changes:
    - Add lib/EMC230x/ library supporting EMC2301/02/03/05 variants with
    direct-drive PWM, RPM closed-loop, software LUT, and 6 examples
    - Rewrite src/cooling.cpp: remove I2C mux/address translator code,
    replace hardware LUT with software LUT + hysteresis, add deferred
    init for hot-plug (EMC2302 powered from 12V-derived 3.3V regulator)
    - Rescale COOLING_PUMP_MAX_DUTY_PCT from 16 to 41 (EMC2101 used 0-100%
    scale, EMC2302 uses 0-255 raw)
    - Add ModuleBase::overrideIni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
    [commands.cpp, config_advanced.h, cooling.cpp]
2026-03-19 Update README to reflect current hardware and architecture
    - Hardware table: EMC2302 replaces dual EMC2101, AD5693R replaces MCP4921,
    INA237 replaces INA260, LSM6DSOX replaces QMI8658, Qwiic relays replace
    GPIO-driven relays, add coolant flow/temp sensors
    - Module reference: expand cooling section (software LUT, deferred init,
    pump normalisation), add compressor and OTA modules, update dashboard
    (Preact SPA, WebSocket Protobuf), update amplifier (AD5693R DAC)
    - Commands table: add all current commands (cooling fan/pump, relay,
    compressor, fsm, fault, mock, ota, reinit, etc.)
    - Build pipeline: document 3-stage pre-build (proto, dashboard, embed)
    - Dependencies: update to current Pla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
2026-03-22 Update README for ADS122C04 migration and add module system docs
    - Replace all MAX31865/PT100/SPI references with ADS122C04/PT1000/I2C
    - Add EMC2302 ALERT# fault detection and I2C bus recovery docs
    - Update conversions table (resistanceToTemperaturePT1000, parseDurationMs, etc.)
    - Remove Adafruit_MAX31865 from local library listing
    - Add sparkfun/SparkFun ADS122C04 to PlatformIO library listing
    - Create docs/modules.md covering the full module lifecycle, CRTP base,
    registry system, init/service flow, and authoring guide
    - Rename COOLING_FAN_FAULT_PIN → COOLING_FAN_FAULT_INDICATOR_PIN
    [cooling.cpp, pin_config.h]
2026-03-22 Replace ASCII art with Mermaid diagrams in docs/modules.md
    Init flow, service flow, and module group chains are now rendered
    as Mermaid flowcharts with colour-coded node classes for readability.
2026-03-22 Add shared tick clock, fix all native tests, fix PT1000 conversion
    Major changes:
    - Add tick module (tick.h/tick.cpp): shared monotonic clock updated once
    per loop() iteration. All modules read tick::nowMs() instead of
    accepting uint32_t nowMs parameters. Removes ~22 nowMs parameters
    across state_machine, indicator, compressor, cold_head, hardware,
    tracking, sensor_mock, and their callers.
    - Fix native test build: add -std=gnu++17 to native env, guard millis()
    in indicator.h/tracking.h with #ifdef ARDUINO, add lib_ignore for
    hardware-only libraries, create esp32s3_test env for embedded tests.
    - Fix PT1000 conversion: AN709 polynomial was receiving raw PT1000
    resistance (10x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
    [amplifier.cpp, cold_head.cpp, commands.cpp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]
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2026-04-07 Switch EMC2302 to EMC2303, clarify variable names in cooling module
    - Constructor: 2 → 3 channels (fan=ch0, pump=ch1, ch2 unused)
    - Rename EMC2302_2_I2C_ADDRESS → EMC2303_I2C_ADDRESS (still 0x2F)
    - Rename unclear variables: st → controllerStatus, fanSt → fanStatusReg,
    stallSt → stallStatusReg, spinSt → spinStatusReg, driveSt →
    driveFailStatusReg, dutyCycle → fanDutyCycle, t → interpFraction
    - Update all comments, docs, and README references
    [config_advanced.h, cooling.cpp]
2026-04-29 Still some ACS issues
    [amplifier.cpp, hardware.cpp, pin_config.h]
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2026-10-04 KiCad: cleaner layout, decoupling blocks, label directions, KiCad format fixes
    - move IC decoupling caps into labelled blocks at the side of each sheet
    - global labels show input/output direction per net
    - no 4-way junctions (generator now checks and fails)
    - generator output matches KiCad's saved format (hide property, junction
    and wire normalisation, lib symbol embedded fonts, multi-unit pins)
    - hand-laid USB ESD protection as a pass-through
    [amp_control.kicad_sch, amp_current.kicad_sch, cold_head.kicad_sch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]
2026-10-04 More fixes
    [amp_control.kicad_sch, amp_current.kicad_sch, cold_head.kicad_sch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]
2026-10-04 Fixing the UUID issues
    [amp_control.kicad_sch, amp_current.kicad_sch, cold_head.kicad_sch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]
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2026-10-05 Add generated 4-layer KiCad PCB layout for the controller
    Placement, Freerouting autoroute, pours and stitching are generated by
    hardware/kicad/tools/gen_pcb.py from the schematic netlist. DRC: 0 errors,
    0 unconnected. Open items are listed in DESIGN_REVIEW.md.
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2026-10-15 Put supply pins on top and grounds on the bottom of IC symbols; flake8-clean Python
    Schematic: re-laid out pins on U2, U3, U6, U7, U11, U14, U17-U20, U22-U24
    and PS1 (supply on top, ground/strap pins on the bottom edge) via custom
    `cryocooler:` symbols (make_lib.from_stock) and a gnd_bus helper; U18/U2
    use mirroring instead of a 180 degree rotation. Nets are unchanged (ERC 0,
    117/117 datasheet rules, PCB nets still match). Text placement now shows
    every power-symbol name, avoids wires, and uses a realistic character width.
    Python: black -l 79 -S plus manual wrapping so hardware/kicad and scripts/
    pass flake8; add .flake8.
2026-10-15 Move the power monitor, RTD ADC and fan controller to SPI; drive the compressor relay by GPIO
    - sysinfo: INA237 (I2C) -> INA239 (SPI mode 1, CS GPIO3) via robtillaart/INA239.
    Presence is checked by reading the ID registers each tick instead of an
    I2C ping.
    - cold_head: ADS122C04 (I2C) -> ADS1220 (SPI mode 1, CS GPIO44) via
    wollewald/ADS1220_WE. DRDY is not wired, so the 50 ms single-shot
    conversion is timed. Adds 50/60 Hz rejection.
    - i2c_bridge: new SC18IS604 SPI-to-I2C bridge driver (CS GPIO8, RESET GPIO9,
    SPI mode 3). hardware::i2c() now returns an EMC230xBus behind the bridge;
    Wire is no longer used. cooling and the i2c scan command go through it.
    - compressor: the off-board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
2026-10-15 KiCad PCB: regenerate and route for the new parts (DRC 0 errors, 0 unconnected)
    - Places the INA239 LEDs and filter, the compressor relay driver, the
    SC18IS604 and its buffer, and about 40 test points; test points and the
    debug LEDs are placed beside a pad on their net.
    - gen_pcb.py fixes: escape stubs now sample the whole stub and ignore only
    the pad's own tracks (diagonal-track bounding boxes hid real obstacles);
    isolated-side passives are derived from nets instead of fixed refs; ground
    pads boxed in by tracks get an escape via; locked 0.35 mm via-in-pad on the
    fine-pitch ground pads of U19, U23 and U4 before routing.
    - tools/link_usb_vbus.py joins the USB-C VBUS pad pairs afte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
2026-10-15 Docs: correct the hardware tables and describe the SPI-only design
    - README: fix the hardware table (MCP4921 on SPI, IMU on SPI, ACS37800 on its
    own SPI bus, EMC2303 at 0x4D, relay and sensor pins), the bus notes, module
    sections, command table and library lists.
    - AGENTS.md and docs/modules.md: I2C now exists only behind the SC18IS604.
    - hardware/kicad: sheet table, GPIO map, DESIGN_REVIEW entries for the INA239,
    ADS1220, SC18IS604 (including the unconfirmed MISO behaviour and register
    address inconsistency), the relay driver and the PCB limits.
2026-10-15 PCB silkscreen: button and LED labels, cryocooler logo, title and ALPHA mark
    - Small labels beside the RESET / BOOT / POWER buttons, the panel button
    connector and every indicator LED (17 in all), each on the first side of
    the part that is clear of footprints, holes and reference texts.
    - Back silkscreen: black-and-white trace of the Hybrid-98 cryocooler (stickers
    removed, vectorized with potrace, mirrored so it reads from the back) with
    "STI Hybrid-98 Cryocooler Control Unit" and "ALPHA DEV UNIT" below it,
    placed clear of the through-hole pads. Artwork and trace script are in
    hardware/kicad/artwork/.
    - Front silkscreen: large "ALPHA" in the free spot nearest the board centre.
    -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
2026-10-15 Add JLCPCB fabrication files (Gerbers and drill) for the 4-layer board
    Gerbers, Excellon drills (PTH/NPTH separate), drill maps and report, a
    ready-to-upload cryocooler_jlcpcb.zip, and a README with the regenerate
    commands and order settings to check (notably the 0.35 mm via-in-pad).
    Made from the routed board on pcb-silkscreen-labels (DRC 0 errors).
2026-10-15 Add the pre-order audit and correct the INA239 power note
    AUDIT.md records an independent pass over every part's pinout, the nets and
    the PCB: no wrong pinout, rail short or reversed polarized part found. It
    lists what was read from datasheets this session (INA239, ADS1220,
    SC18IS604, AD633 SOIC, AP63205, CL25, LM4040, 74LVC1G125, MIE1W0505 pins and
    land pattern), what rests on secondary sources or earlier audits, BOM notes
    (2 W shunt, voltage ratings), bench checks and a first-power-up procedure.
    DESIGN_REVIEW.md wrongly said the ESP32 could be USB-powered while the INA239
    was unpowered; USB VBUS powers nothing, so both lose power together.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
2026-10-15 Swap F1 to the Littelfuse NANO2 453 footprint and re-route
    F1 is now the 5 A fast-acting Littelfuse 0453005.MR (2410 package); there is
    no 5 A fast-acting fuse in 1812. Schematic, PCB (DRC 0 errors, 0 unconnected,
    807/807 pad nets), Gerbers, BOM and notes regenerated.
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2026-10-15 Remove Serial Studio TCP server, dashboard config and submodule
    Drop the port-8080 AsyncTCP server, the Device-Defined-Dashboard submodule,
    dashboard_config.h and the Serial Studio tests. The Preact dashboard path
    (WebSocket protobuf + /api/telemetry JSON) is unchanged. Also fixes the mDNS
    ws service advertising the removed port.
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2026-10-16 Move the IMU off-board (J14) and add labelled module boxes to the PCB
    The LSM6DSOX is now the Adafruit breakout (product 4438) mounted on the
    cryocooler and cabled to a 10-pin JST XH header (J14) over the shared SPI
    bus. U19 and its capacitors are gone; J14 and six 100 R series resistors
    are added, and every other reference number is unchanged.
    PCB (130 x 110 mm, was 130 x 100):
    - one outlined, labelled silkscreen box per module (pcbfloorplan.py); the
    placer keeps parts inside their box and reserves a label pocket beside
    every part so each label sits next to its own part
    - box 3D models for U3, L2, L3, F1 and PS1, whose library models are missing
    - re-routed; DRC 0 errors, 0 unconnected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
2026-10-16 Regenerate Gerbers, zip and board renders automatically
    Add tools/export_fab.py, which runs kicad-cli to write the Gerbers, drill
    files, JLCPCB zip and the front/back 3D renders in hardware/kicad/fabrication.
    gen_pcb.py (every mode) and link_usb_vbus.py now run it after writing the
    board; set SKIP_FAB_EXPORT=1 to skip it. Gerbers, zip and the two render
    PNGs are refreshed from the current board.
2026-10-16 Add per-section supply jumpers, 8-pin IMU header and connector pin labels
    - Four 1.27 mm 2-pin jumpers (JP1-JP4), each with a rail-on LED, cut the
    supply of one section for debugging: signal generator +3V3, +-15V
    generator +5V in, isolated amp-current supply +5V in, and a shared
    +3V3 net for the cooling chips (EMC2303, RTD ADC, I2C bridge).
    - J14 is now an 8-pin JST XH in the Adafruit LSM6DSOX pad order
    (VIN, GND, SCL, SDA, DO, CS, I1, I2); firmware pin comments updated.
    - Pin-function labels beside every connector, "RAILS ±15V" box title.
    - Board re-placed and re-routed (130 x 110 mm); DRC 0 errors, 0 unconnected,
    ERC 0, 173 datasheet rules pass. BOM, READMEs, Gerbers and renders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
2026-10-16 Swap L2/L3 for shielded Bourns SRP7050TA inductors
    L2 (3.3 uH boost) and L3 (6.8 uH inverting) were semi-shielded SRN8040TA
    parts. Replace them with fully shielded SRP7050TA-3R3M / -6R8M, using a
    new L_Bourns_SRP7050TA footprint (datasheet land pattern, 7.3 x 6.6 mm
    body) and a 5.0 mm envelope model. The routed board keeps its tracks (the
    footprints were swapped in place and the pours refilled); DRC 0 errors,
    0 unconnected. Gerbers and BOM regenerated.
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2026-10-18 Widen 0.2 mm drill vias to 0.45 mm for JLCPCB
    JLCPCB flagged 0.2 mm holes on 0.3 mm pads and required a paid 4-wire
    Kelvin test. The six via-in-pad vias are now 0.45/0.2 mm (the size JLC
    accepts without it); two free GND vias were nudged for clearance and a
    DRC rule allows 0.1 mm clearance for 0.2 mm-drill vias on 0.5 mm-pitch
    pads. Gerbers and the JLCPCB zip are regenerated.
2026-10-20 Replace the ±15 V LDOs with one LT3097 and add a power-good interlock
    - rails_15v: ADP7142 + ADP7182 replaced by one LT3097 (±14.7 V, 147 k SET
    resistors); the ADP5071 output caps are now 22 uF / 50 V and double as the
    LT3097 inputs. PGP / PGN make the PG_15V node (fed from +15 V, so it reads
    0 V if a rail is missing).
    - amp_control: a series BSS138 (Q9) gated by PG_15V blocks AMP_REM unless
    both rails are good. New power_good sheet: LED (D23) and the active-low
    PG_15V_N flag on GPIO43 (PG_15V_N_PIN).
    - Tooling: LT3097 symbol, footprint and 3D envelope; datasheet rules (191),
    GPIO check, BOM tables, floor plan, PAD_BRIDGES and pre-placed GND vias in
    gen_pcb.py, new fix_route.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
2026-10-20 Move the power-good stage into the ±15 V box
    The free bottom-left corner of the RAILS ±15V box holds the stage (LEDs D24 /
    D25, FETs Q10-Q12, BAT54AW D23 and their 0402 resistors) right next to the
    LT3097 it indicates. The earlier "box is full" result predates the box growing
    and the smaller parts.
    - gen_pcb.py: Power Good sheet maps to RAILS ±15V; its parts are placed last
    around anchors in the corner; the box's passives and debug LEDs are frozen
    at their previous positions so nothing else moves; GND pad vias for U20, U25
    and U11 are pre-placed before routing.
    - fix_route.py: moves a crowded GND via inside a large pad instead of removing
    it, and switches the pour connection off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
2026-10-28 WIP: restructure PCB for the Phoenix UCS 125-87 housing
    Work in progress, layout not finished: about 90 parts still do not fit
    their sections and the board is not routed.
    - Right-angle connectors: Phoenix MSTBA 2,5 / MC 1,5, JST XH side entry,
    Hirose DF13, Molex 505448-0871 (new footprint from the Molex drawing)
    - Datasheet and product links on every symbol (tools/part_links.py)
    - Test points so every IC has one on its own nets
    - gen_pcb.py: 100 x 62 mm two-sided board, housing holes and restricted
    corners, ESP32 antenna notch, one section per sheet, board ID block,
    ESP32 pin names, pin-1 marks, blue mask
    - Housing drawings in hardware/housing/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
2026-10-29 WIP: pack the UCS 125-87 board and enforce readable silkscreen
    Placement on the 100 x 62 mm board now gets every part on with the
    silkscreen check passing in most runs, but the board is at capacity and
    not yet stable or routed. Generator changes:
    - grid index for the occupancy map (about 4x faster placement)
    - through-hole parts checked against the other side, placed first
    - largest parts first, test points last, 0.25 mm retry grid
    - text measured with pcbnew; silk check also flags text over pads
    - vertical and in-box section titles, short title and label forms
    - connector pin and function labels reserved early, other-side fallback
    - references with no room hidden from silkscreen (kept on F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
2026-10-29 Lay out the board for the Phoenix UCS 145-125 housing
    Move to a 120 x 100 mm, 4-layer, blue-mask board for the UCS 145-125-F-CCD
    7035 housing: housing mounting holes and restricted corners, ESP32 antenna
    over a routed notch, one labelled section per schematic sheet with almost
    every part on top. Placed, routed and cleaned up: DRC 0 errors, 0
    unconnected, 0 schematic-parity issues; ERC 0; 193/193 datasheet rules.
    - AGENTS.md: test points go on the same side as the part they test, close
    to it
    - gen_pcb: test points held to their IC's side and within 8 mm; silkscreen
    check measures text by ink and also fails on pads, part outlines, section
    lines and pin-1 dots; titles along or up a borde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
2026-10-29 Keep the indicator LEDs on the top side
    D8, D13, D17 and D19 had fallen back to the underside, where they cannot be
    seen. LEDs are now placed on the top only; re-placed and re-routed. DRC 0
    errors, 0 unconnected, 0 schematic-parity issues; silkscreen and test point
    checks pass. A part's own label in its courtyard margin no longer counts as
    an overlap (the silkscreen check keeps it off pads and outlines).
2026-10-29 Use an M12 receptacle for the PT1000 and JST PH headers for the 2-pin I/O
    - J10 (cold head PT1000): TE T4145035041-001, M12 A-coded 4-pin female,
    right angle, shielded, panel and PCB mount through the right side wall;
    footprint from TE drawing T41450350X1001 rev B
    - J6, J7, J13 (NTC, panel button, relay out): Adafruit 1769 (4UCON 17311),
    JST PH compatible 2-pin right-angle SMT; footprint from its drawing
    - BOM, part links and 3D envelopes for both; schematic nets unchanged
    - gen_pcb: ground fan-out before routing (a locked via and short track per
    small ground pad, clear of other holes) so no ground pad is left on a
    pour island; fallback labels must sit inside a section box
    - fix_ro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
2026-10-29 Ground the M12 shield, order the ground loops, name the J14 cable parts
    - J10: shielded symbol (Conn_01x04_Shielded); the M12 shield pin and its
    four shell legs are pad SH, tied to GND
    - TP22-TP25: Keystone 5001 black miniature PC test points (KiCad
    TestPoint_Keystone_5000-5004 footprint, 1.02 mm hole per Keystone's
    drawing); now in the BOM, the bare pad test points stay out
    - J14 BOM note: cable housing Molex 5054320801 with 505431 terminals, or
    tin pre-crimped leads 797581148 / 797581149 (from molex.com)
    Only netlist change: GND gains J10 SH. DRC 0 errors, 0 unconnected, 0
    schematic-parity issues; ERC 0; 193/193 datasheet rules.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
2026-11-02 Finish OEM controller transcription; fix text and line overlaps
    - KiCad: net alias table, real project generated, TRANSCRIPTION_NOTES,
    text/line overlap checker (check_text_overlap.py, run by check.sh)
    and generator fixes so all 13 pages pass with 0 problems
    - draw.io: edge labels placed beside lines, layouts re-spaced; all 16
    pages pass a rendered glyph-vs-stroke check
    - OVERSTROKE.md section 2.3 (FIG 5C back-off counter) and the
    overstroke signal-path diagram
2026-11-02 Rev 2 schematic: LT8582, display sheet, power-good to bridge GPIOs, R6 fix
    - R6 (OPA1656 feedback) 51k -> 22k || 1 nF C0G per the rev 1 bench fix
    (gain 7.67); gen_sim mirrors it.
    - Replace the ADP5071 with an LT8582 (datasheet p.30 circuit, 1.5 MHz):
    boost to +16.4 V, coupled-inductor (MSD7342-103) inverter to -16.5 V.
    New MSD7342 footprint generator (tools/make_footprints.py).
    - LT8582 PG1/PG2 and LT3097 PGP/PGN each go to an SC18IS604 GPIO;
    GPIO0 enables the display backlight.
    - New Display sheet: FH12-14S FPC for the Phoenix 2.4" ST7789V touch
    display (pinout from datasheet 109921), TSC2046 touch controller on the
    shared SPI bus, backlight switch, strap pull-downs. GPIO45-48 u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
2026-11-02 Rev 2 PCB: double-sided placement on the 100 x 62 UCS 125-87 board
    gen_pcb.py now places parts on both sides (side-aware occupancy, bottom
    flip, through-hole pins block both sides), with per-side module boxes,
    antenna notch, corner keep-outs / mask-free squares, board ID block and
    test points labelled with their net names. Placement-only board: every
    part placed, floorplan clean, DRC 0 errors (unrouted).
    Schematic: four low-value test points dropped (IMU INT1/2, ESP EN/BOOT),
    1 uF decoupling caps in 0603.
2026-11-02 Rev 2 firmware: status display, bridge GPIOs, per-rail power-good flags
    - pin_config: display (CS 47, D/C 48, RESET 46) and touch CS (45) pins,
    SC18IS604 GPIO assignments.
    - i2c_bridge: configureGpio / writeGpio / readGpio; GPIO0 drives the
    display backlight, GPIO1-4 read the four +-15 V power-good flags.
    - amplifier: polls the four rail flags every 250 ms and logs which rail
    changed (RailFlags / decodeRailFlags in power_good.h, with tests).
    - New display module (Adafruit ST7789 on the shared SPI bus) with the
    Phoenix 109921 panel settings, printing state, cold-head temperature,
    +-15 V status and uptime once a second.
    - gen_pcb: Earth net class (1.5 mm) for the J11/J12 pass-through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
2026-11-02 Rev 2 PCB generator: JLCPCB rules, shared section walls, blue mask, BETA ID
    - JLCPCB 4-layer limits in the board settings (0.1 mm via ring, 0.2 mm
    hole clearance and via hole-to-hole, 0.15 mm silk-to-pad, 1.0 mm / 0.15 mm
    silk text, 0.1 mm mask dam) and in cryocooler.kicad_dru (0.45 mm pad
    hole-to-hole, 0.15 mm PTH ring, 0.3 mm inner PTH clearance, 0.2 mm NPTH to
    copper); footprint silk widened to 0.15 mm.
    - Test point names shortened to fit 1.0 mm text.
    - Neighbouring sections share one silk wall.
    - Footprints carry their schematic symbol links (Update PCB from Schematic
    no longer offers to add every part); `gen_pcb.py link` stamps them onto an
    existing board.
    - Blue solder mask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
2026-11-02 Rev 2 PCB: route the board to 3 open nets (DRC 0, parity 0)
    Freerouting stalled at 24 open items. A grid A* router (tools/gridroute.py)
    plus a corner rip-up (tools/ripup.py) and a refill / island-stitch step
    (tools/finish_route.py) finish all but three: PGP_15V, PGN_15V and PGN_16V5
    to the SC18IS604 GPIOs, which are sealed in by the +-15 V section's power
    copper. Two GND pour fragments are also still unstitched. Removes the GND
    via 0.3 mm from the left edge. Status and options are in
    hardware/HANDOFF_rev2.md; not ready to order.
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2026-11-03 UCS 145-125 schematic: PH 4-pin PT1000, 2-way amp out, 3-way cryocooler with GND
    - J10 PT1000 becomes an Adafruit 4392 JST PH 4-pin right-angle SMT header
    (footprint from the CW2001-04T drawing); the M12 and Molex parts go.
    - J11 (amp out) is 2-way, J12 (cryocooler) 3-way with pin 3 on board GND.
    - Connectors return to this board's side-wall set: MSTBA 2,5 / MC 1,5
    pluggables, JST XH side entry, Adafruit 1769 JST PH.
    - Part links on every symbol again; BOM groups via bom_value / resolve;
    0402 LEDs get Kingbright APHHS1005SURCK / APHHS1005CGCK.
    ERC 0, 228/228 datasheet rules, 0 parts without a part number.
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
